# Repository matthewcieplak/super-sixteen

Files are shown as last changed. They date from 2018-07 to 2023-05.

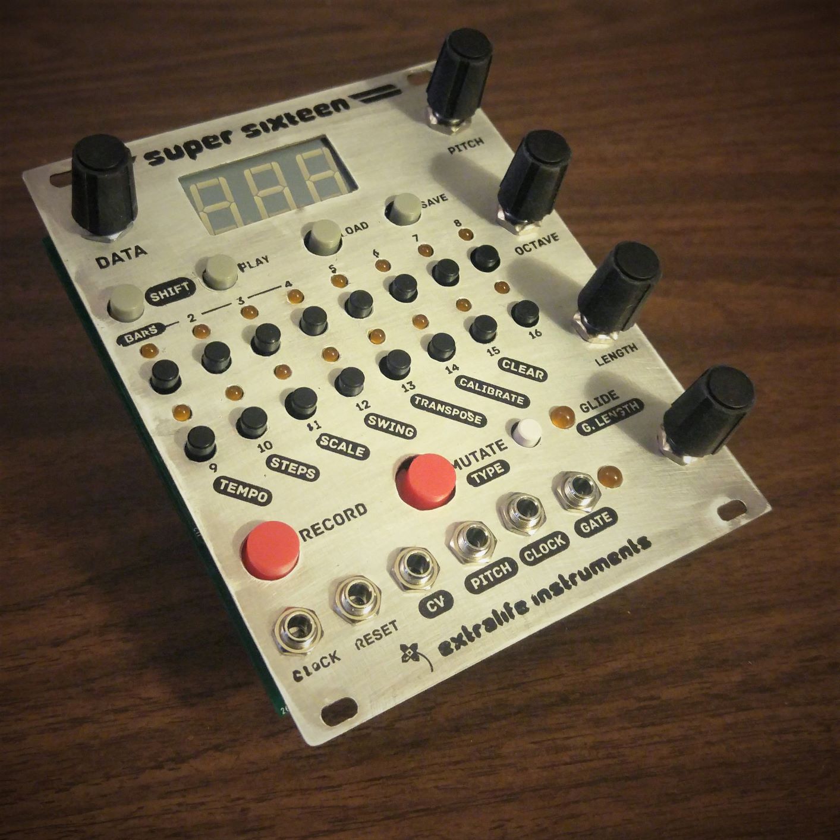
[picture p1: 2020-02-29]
graphics/supersixteen.jpg

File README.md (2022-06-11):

# Super Sixteen Eurorack Sequencer
Super Sixteen is an open-source/open-hardware sequencer for the Eurorack synthesizer format. It's available through my [web shop](https://store.extralifeinstruments.com) and fine retailers as a complete module and DIY kit. It's developed on the Arduino codebase on Atmega328P, using the [PlatformIO](https://platformio.org/) extension for Visual Studio Code.

Photo of the Super Sixteen module

At just 20HP, it is a compact and powerful 64-step control voltage sequencer with 99 song patch memory, motion recording, scale selection, realtime pitch and rhythm effects, paraphonic modes, generative mutations, and a uniquely powerful two-handed programming interface.

Video blogs [documenting the sequencer progress are available on youtube](
https://www.youtube.com/playlist?list=PLXcIAQij6ZZKMTHAFv8BHvEnsouNYhx3t).

# Documentation

*   [USER MANUAL (pdf)](graphics/manual_1.1.pdf)
*   [BUILD GUIDE (pdf)](http://extralifeinstruments.com/docs/super-sixteen/build-guide.pdf)
*   [BILL OF MATERIALS (octopart list)](https://octopart.com/bom-tool/Wq51xQ3R)
*   INTERACTIVE BOM (html - for easy part placement) [CPU board](http://extralifeinstruments.com/docs/super-sixteen/ibom-cpu.html) / [Control board](http://extralifeinstruments.com/docs/super-sixteen/ibom-control.html)
*   [Video build guide](https://www.youtube.com/watch?v=RGmp3aG8Nbw&feature=emb_title)
*   [1v/oct calibration tutorial video](https://www.youtube.com/watch?v=QJvS-ma6CHY)
*   [Build support thread on Mod Wiggler](https://modwiggler.com/forum/viewtopic.php?f=97&t=238514)
*   [ModularGrid page](https://modulargrid.net/e/other-unknown-extralife-instruments-super-sixteen)

# Hardware files
Kicad and gerber files for four PCBs are included in this repository. The project is split into two boards, one for the CPU, memory, power, and DAC logic (CPU_board) and one for the front panel controls (control_board). Each board comes in a through-hole version for DIY builders and an SMT version for automated assembly. They are functionally identical but part numbers are different to reflect the different footprints. 

# Software
Primary development of the firmware takes place in [sequencer_app_v2](https://github.com/matthewcieplak/super-sixteen/tree/master/sequencer_app_v2) using the Arduino C++ libraries but compiled using PlatformIO and typical C header files. (The older, pure Arduino version, [sequencer_app](https://github.com/matthewcieplak/super-sixteen/tree/master/sequencer_app) is here only for archival purposes and is unmaintained). You can find the .hex files to upload using the arduino updater in [sequencer_app_v2/build](https://github.com/matthewcieplak/super-sixteen/tree/master/sequencer_app_v2/build). The shell commands for updating using avrdude are contained in [upload.sh](sequencer_app_v2/upload.sh), though you may also use the Arduino IDE to upload new firmware.

# Troubleshooting
Please refer to the [official build support thread on Mod Wiggler](https://modwiggler.com/forum/viewtopic.php?f=97&t=238514) to post a query. You may find your question has already been answered!

Common issues:
* *My sequencer doesn't turn on!* - Check your soldering carefully, under magnification and bright light! 90% of functional issues can be traced to bad connections caused by missing or cold solder joints. A common place to find bad joints is on the header connector pins, as they are on the opposite side of the board from the othres.
* *My soldering is good, now what?*  After that, check the *orientation* of all your ICs closely. A backwards chip or capacitor or diode is easy to miss.
* *The screen shows "nEn" at startup and freezes when I move the encoder* - This message (actually "mEm") is caused by a communication failure between the CPU (Atmega328p) and the memory chip (W25Q80DV). Most often this is caused by soldering issues on the SMT memory chip. Reflow the SMT joints with flux and try again. If it persists, check for 3.3v at pins 8 and 4 of the memory chip. If that fails, you may suspect the 2n7000 transistors nearby (mosfets are fragile) and then potentially check the integrity of the traces between the chip and the resistors. Opening kicad and using the show net tool is helpful for this.
* *I can program sequences but they're not in tune* You need to perform the DAC calibration procedure, as outlined in the manual and [this video tutorial](https://www.youtube.com/watch?v=QJvS-ma6CHY). You'll need a multimeter or electronic tuner.

# License
Code: [GPL3.0](https://www.gnu.org/licenses/gpl-3.0.en.html)
Hardware: [cc-by-sa-3.0](https://creativecommons.org/licenses/by-sa/3.0/deed.en)

By: Matthew Cieplak (matthew.cieplak@gmail.com)

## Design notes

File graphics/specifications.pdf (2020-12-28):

# specifications

Dimensions:
Height 129.5mm
Width 102mm / 20 HP (horizontal pitch) Rear Depth 38mm
Front Depth 16mm (aka knob height)
Total Depth 55mm
Electrical characteristics:
Max current draw: 90mA (+12v) / 5mA (-12v) Pitch output voltage: 0-8 volts
CV output voltage: 0-8 volts
Gate output voltage: 0-5 volts
Clock output voltage: 0-5 volts

Clock input voltage: 10v maximum Reset input voltage: 10v maximum

Copyright 2020, Extralife Instruments, LLC

Power connector:
Super Sixteen requires a standard “Eurorack” -12V / +12V power supply (2x5 pin connector). The red stripe of the ribbon cable (-12V side) must be oriented on the same side as the “Red stripe” marking on the circuit board.

The complete manual can be found online at:
http://extralifeinstruments.com/docs/super-sixteen/manual.pdf

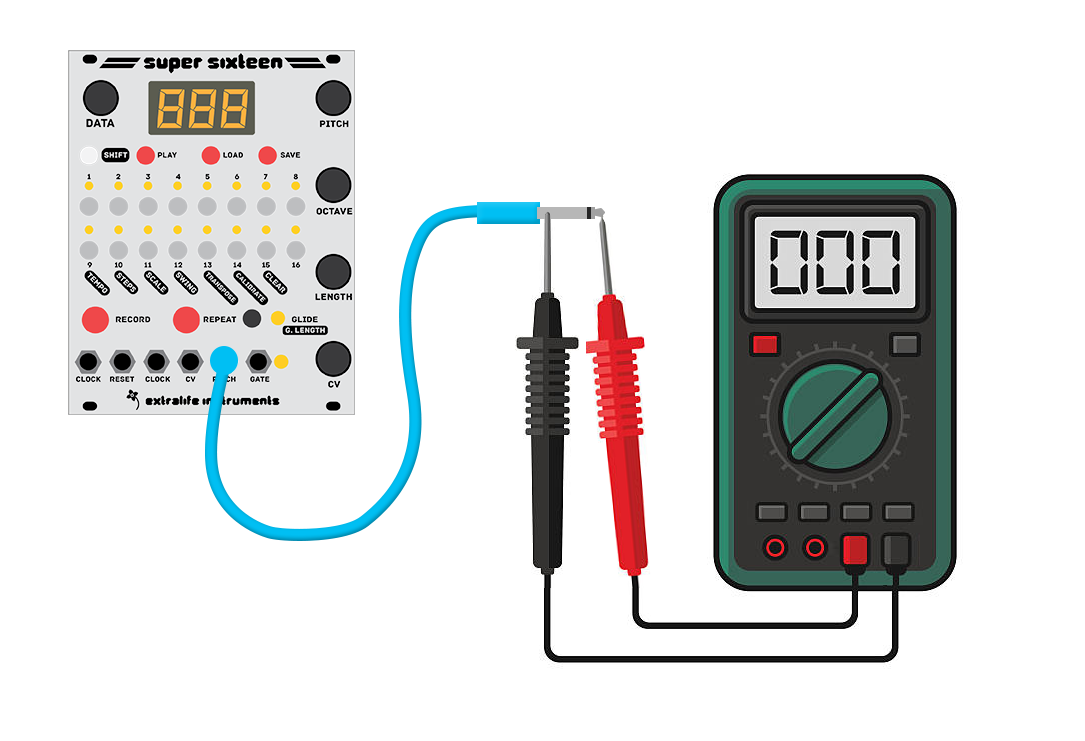
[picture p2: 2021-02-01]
graphics/multimeter clipart.png

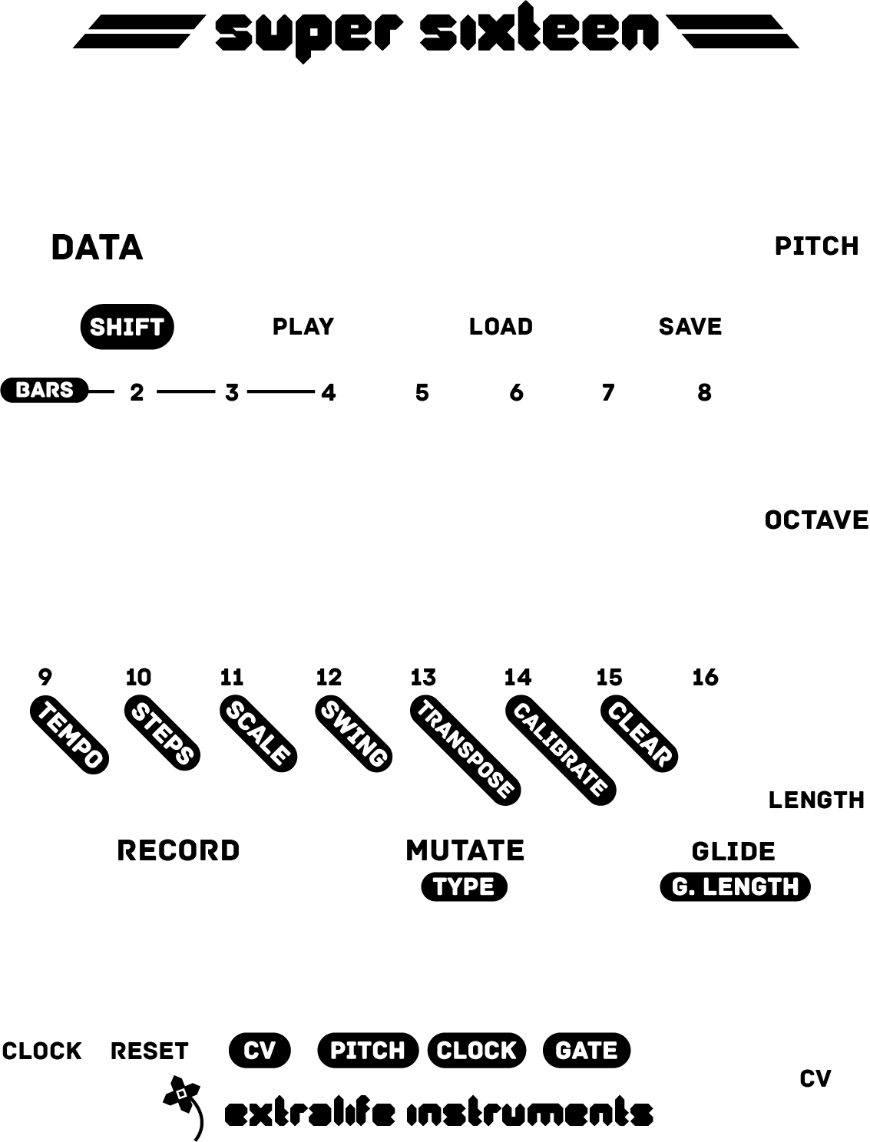
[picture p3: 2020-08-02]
kicad-panel/front_panel_labels.png

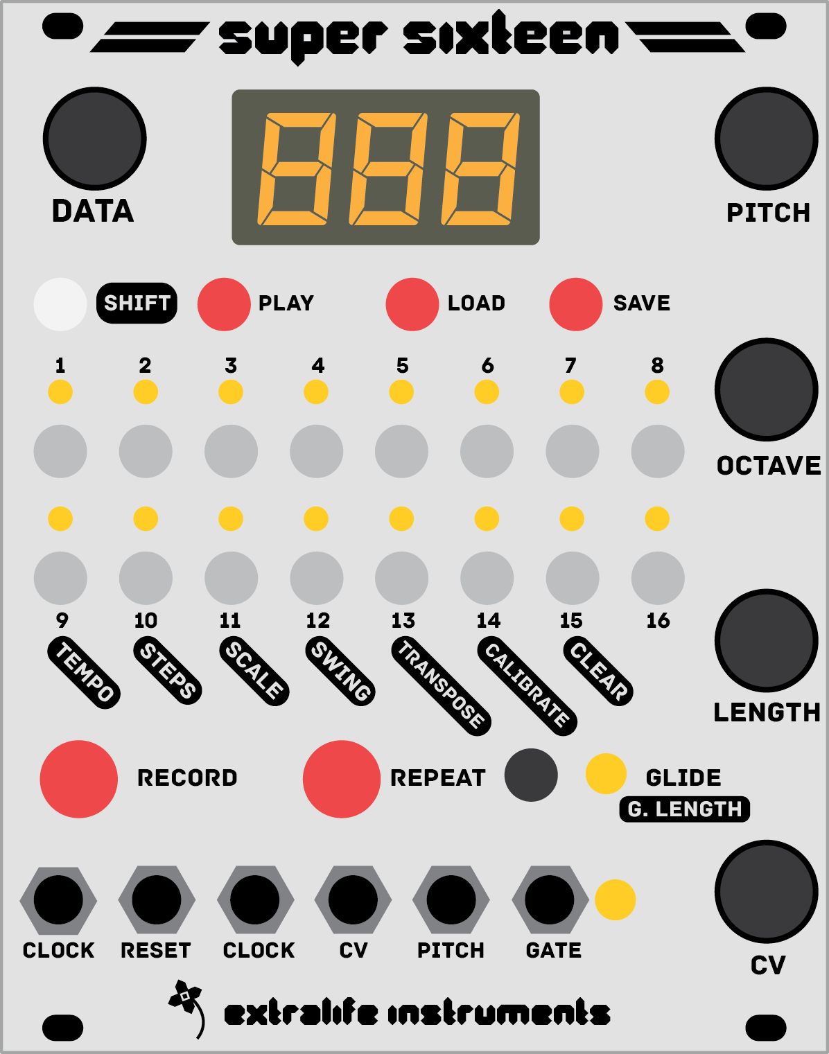
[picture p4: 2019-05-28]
graphics/front_panel.png

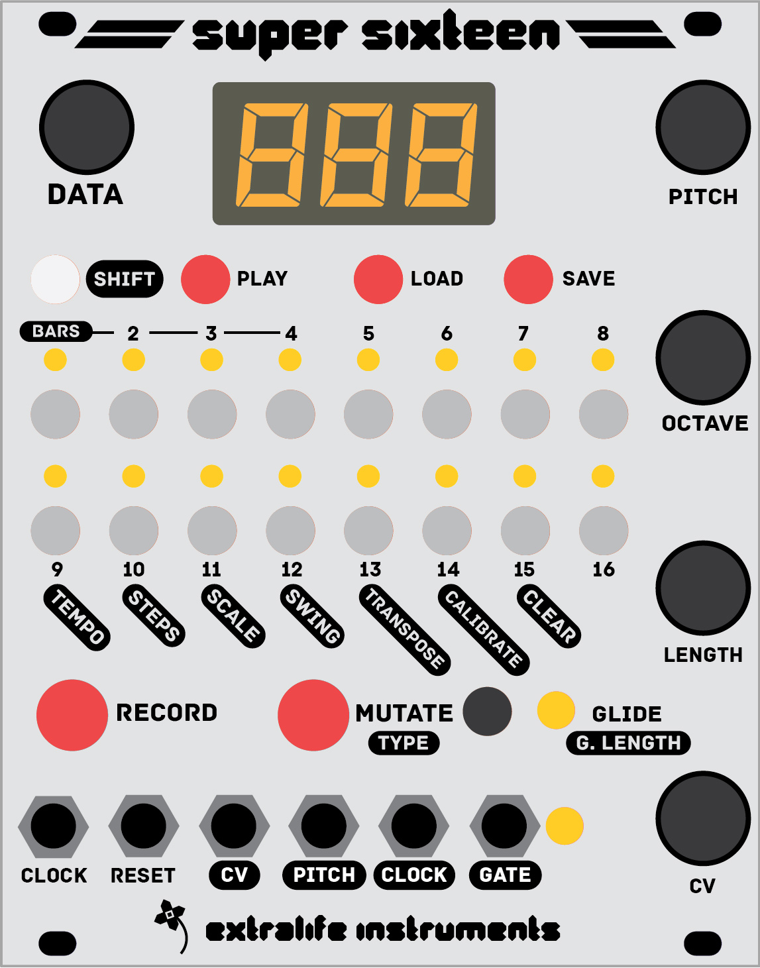
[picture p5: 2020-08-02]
graphics/supersixteenfrontpanel.jpg

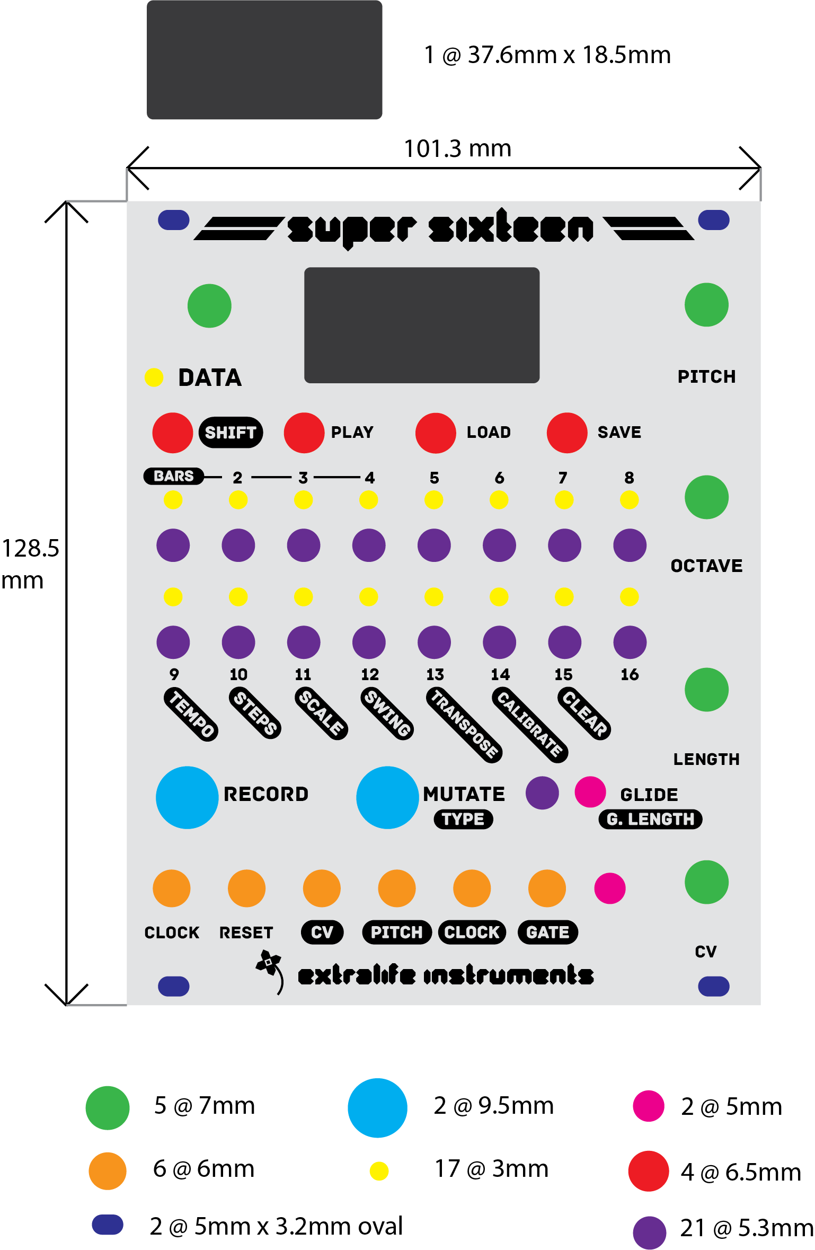
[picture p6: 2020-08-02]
kicad-panel/front_panel_legend.png

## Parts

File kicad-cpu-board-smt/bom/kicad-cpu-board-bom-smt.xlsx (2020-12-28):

Item Number | Comment | Do Not Install | Quantity | Reference Designators | Footprint | Vendor | Vendor Part # | Manufacturer Part # | Manufacturer
1 | 220uF |  | 1 | C11 | Capacitors_SMD:CP_Elec_10x10 | Digikey | 493-2179-6-ND | UWT1C221MCL1GS | Nichicon
2 | 47uF |  | 3 | C12,C10,C2 | Capacitors_SMD:CP_Elec_6.3x7.7 | Digikey | 493-2225-6-ND | UWT1H470MCL1GS | Nichicon
3 | 100nF |  | 7 | C13,C9,C1,C14,C6,C5,C4 | Capacitors_SMD:C_0603_HandSoldering | Digikey | 399-1100-6-ND | C0603C104Z3VACTU | Kemet
4 | 22pf |  | 4 | C16,C15,C7,C8 | Capacitors_SMD:C_0603_HandSoldering | Digikey | 399-7874-6-ND | C0603C220J1GACTU | Kemet
5 | 1uF |  | 1 | C3 | Capacitors_SMD:CP_Elec_4x5.3 | Digikey | 493-9985-6-ND | UUX2G010MNL1GS | Nichicon
6 | 1SMB5918BT3G |  | 2 | D2,D1 | Diodes_SMD:D_SMA-SMB_Universal_Handsoldering | Digikey | 1SMB5918BT3GOSDKR-ND | 1SMB5918BT3G | ON Semiconductor
7 | S1KB |  | 2 | D4,D3 | Diodes_SMD:D_SMA-SMB_Universal_Handsoldering | Digikey | S1KB-FDIDKR-ND | S1KB-13-F | Diodes Incorporated
8 | ICSP Header | DNI | 1 | J1 | Pin_Headers:Pin_Header_Straight_2x03_Pitch2.54mm | Digikey | 609-3218-ND | 67996-406HLF | Amphenol
9 | Conn_01x10_Male | DNI | 1 | J2 | Pin_Headers:Pin_Header_Straight_1x10_Pitch2.54mm | Digikey | 609-3285-ND | 68001-410HLF | Amphenol
10 | Conn_01x16_Male | DNI | 1 | J3 | Pin_Headers:Pin_Header_Straight_1x16_Pitch2.54mm | Digikey | 609-3267-ND | 68000-416HLF | Amphenol
11 | Conn_02x05_Odd_Even | DNI | 1 | J4 | Pin_Headers:Pin_Header_Straight_2x05_Pitch2.54mm | Digikey | 609-3243-ND | 67997-410HLF | Amphenol
12 | 220uH |  | 3 | L3,L2,L1 | Inductors_SMD:L_1210_HandSoldering | Digikey | 445-1545-6-ND | NLCV32T-221K-PF | TDK
13 | 2N7002 |  | 4 | Q2,Q4,Q3,Q1 | TO_SOT_Packages_SMD:SOT-23_Handsoldering | Digikey | 2N7002LT1GOSDKR-ND | 2N7002LT1G | ON Semiconductor
14 | 1M |  | 1 | R1 | Resistors_SMD:R_0603_HandSoldering | Digikey | RMCF0603FT1M00DKR-ND | RMCF0603FT1M00 | Stackpole Electronics, Inc
15 | 1k |  | 12 | R16,R4,R3,R12,R11,R8,R7,R6,R5,R10,R9,R13 | Resistors_SMD:R_0603_HandSoldering | Digikey | RMCF0603FT1K00DKR-ND | RMCF0603FT1K00 | Stackpole Electronics, Inc
16 | 10k |  | 5 | R17,R18,R14,R15,R2 | Resistors_SMD:R_0603_HandSoldering | Digikey | RNCP0603FTD10K0DKR-ND | RNCP0603FTD10K0 | Stackpole Electronics, Inc
17 | AMS1117-5.0 |  | 1 | U1 | TO_SOT_Packages_SMD:SOT-223-3_TabPin2 | Digikey | NCP1117ST50T3GOSDKR-ND | NCP1117ST50T3G | ON Semiconductor
18 | AMS1117-3.3 |  | 1 | U2 | TO_SOT_Packages_SMD:SOT-223-3_TabPin2 | Digikey | NCP1117ST33T3GOSDKR-ND | NCP1117ST33T3G | ON Semiconductor
19 | ATmega328P-AU |  | 1 | U3 | Housings_QFP:TQFP-32_7x7mm_Pitch0.8mm | Digikey | ATMEGA328P-AURDKR-ND | ATMEGA328P-AUR | Microchip Technology
20 | W25Q80DVSN |  | 1 | U4 | Housings_SOIC:SOIC-8_3.9x4.9mm_Pitch1.27mm | Digikey | W25Q80DVSNIG-ND | W25Q80DVSNIG | Winbond
21 | TL072 |  | 1 | U5 | Housings_SOIC:SOIC-8_3.9x4.9mm_Pitch1.27mm | Digikey | 296-1282-6-ND | TL072CDR | Texas Instruments
22 | MCP4822 |  | 1 | U6 | Housings_SOIC:SOIC-8_3.9x4.9mm_Pitch1.27mm | Digikey | MCP4822-E/SN-ND | MCP4822-E/SN | Microchip
23 | 16mHz |  | 1 | Y1 | Crystals:Crystal_SMD_3225-4pin_3.2x2.5mm_HandSoldering | Digikey | SER4069DKR-ND | TSX-3225 16.0000MF09Z-AC0 | Epson

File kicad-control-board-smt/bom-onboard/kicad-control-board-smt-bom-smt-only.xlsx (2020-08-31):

Comment | Quantity | Do Not Install | Reference Designators | Footprint | Vendor | Vendor Part # | MFG Part # | Manufacturer
47uF | 3 |  | C101,C104,C107 | Capacitors_SMD:CP_Elec_6.3x7.7 | Digikey | 493-2225-6-ND | UWT1H470MCL1GS | Nichicon
100nF | 3 |  | C102,C105,C108 | Capacitors_SMD:C_0603_HandSoldering | Digikey | 399-1100-6-ND | C0603C104Z3VACTU | Kemet
100pF | 3 |  | C103,C106,C109 | Capacitors_SMD:C_0603_HandSoldering | Digikey | 399-7821-6-ND | C0603C101J1GACTU | Kemet
SS54 | 1 |  | D1 | Diodes_SMD:D_SMA_Handsoldering | Digikey | TSS54URGGDKR-ND | TSS54U RGG | Taiwan Semiconductor
LED | 18 | DNI | D105,D114,D115,D111,D106,D102,D103,D107,D112,D116,D117,D113,D108,D104,D110,D101,D118,D109 | LEDs:LED_D3.0mm | Digikey | 160-1940-ND | LTL-1CHA | Lite-On
Conn_01x10_Female | 1 | DNI | J101 | Pin_Headers:Pin_Header_Straight_1x10_Pitch2.54mm | Digikey | S7008-ND | PPTC101LFBN-RC | Sullins
Conn_01x16_Female | 1 | DNI | J102 | Pin_Headers:Pin_Header_Straight_1x16_Pitch2.54mm | Digikey | S7014-ND | PPTC161LFBN-RC | Sullins
BA56_3DIG_7SEG | 1 | DNI | J103 | Eurocad:BA56_3DIG_7SEG | Digikey | 754-1656-5-ND | BA56-12GWA | Kingbright
3.5mm jacks | 6 | DNI | J104,J105,J106,J107,J108,J109 | Eurocad:PJ301M-12 | N/A | N/A | WQP-WQP518MA | Qingpu
MMBT3906 | 3 |  | Q101,Q102,Q103 | TO_SOT_Packages_SMD:SOT-23_Handsoldering | Digikey | MMBT3906LT1GOSDKR-ND | MMBT3906LT1G | ON Semiconductor
MMBT3904 | 2 |  | Q104,Q105 | TO_SOT_Packages_SMD:SOT-23_Handsoldering | Digikey | MMBT3904LT3GOSDKR-ND | MMBT3904LT3G | ON Semiconductor
100R | 12 |  | R101,R102,R104,R105,R106,R107,R108,R109,R110,R111,R112,R113 | Resistors_SMD:R_0603_HandSoldering | Digikey | RMCF0603FT100RDKR-ND | RMCF0603FT100R | Stackpole Electronics Inc
1k | 3 |  | R114,R118,R103 | Resistors_SMD:R_0603_HandSoldering | Digikey | RMCF0603FT1K00DKR-ND | RMCF0603FT1K00 | Stackpole Electronics Inc
680R | 3 |  | R115,R116,R117 | Resistors_SMD:R_0603_HandSoldering | Digikey | RMCF0603FT680RCT-ND | RMCF0603FT680R | Stackpole Electronics Inc
10k | 2 |  | R119,R122 | Resistors_SMD:R_0603_HandSoldering | Digikey | RMCF0603FT10K0DKR-ND | RMCF0603FT10K0 | Stackpole Electronics Inc
100k | 2 |  | R120,R123 | Resistors_SMD:R_0603_HandSoldering | Digikey | RMCF0603FG100KDKR-ND | RMCF0603FG100K | Stackpole Electronics Inc
1M | 2 |  | R121,R124 | Resistors_SMD:R_0603_HandSoldering | Digikey | RMCF0603FT1M00DKR-ND | RMCF0603FT1M00 | Stackpole Electronics Inc
R_POT | 4 | DNI | RV102,RV103,RV104,RV101 | Potentiometers:Potentiometer_Alps_RK09K_Horizontal | Digikey | N/A |  | Alpha
SW_PUSH_12mm | 2 | DNI | SW106,SW105 | Buttons_Switches_THT:Push_E-Switch_KS01Q01 | Digikey | 401-1992-ND | D6R40 F2 LFS | C&K
SW_Push_6mm | 21 | DNI | SW101,SW102,SW103,SW104,SW107,SW112,SW109,SW110,SW113,SW114,SW115,SW117,SW118,SW119,SW120,SW121,SW122,SW123,SW124,SW111,SW108 | Buttons_Switches_THT:SW_PUSH_6mm | Digikey | EG1861-ND | TL1105SPF160Q | E-Switch
Rotary_Encoder | 1 | DNI | SW116 | Rotary_Encoder:RotaryEncoder_Alps_EC12E_Vertical_H20mm | Digikey | PEC11R-4215F-N0024-ND | PEC11R-4215F-N0024 | Bourns, Inc
74HC595 | 2 |  | U101,U103 | Housings_SOIC:SOIC-16_3.9x9.9mm_Pitch1.27mm | Digikey | 1727-2821-6-ND | 74HC595D,118 | Nexperia USA, Inc
MCP23S17 | 1 |  | U102 | Housings_SOIC:SOIC-28W_7.5x18.7mm_Pitch1.27mm | Digikey | MCP23S17-E/SO-ND | MCP23S17-E/SO | Microchip

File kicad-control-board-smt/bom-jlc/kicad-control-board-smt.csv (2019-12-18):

Comment | Designator | Footprint | LCSC Part Number | MFG Part Number | Manufacturer
47uF | C101,C104,C107 | Capacitors_SMD:CP_Elec_6.3x7.7 | C108053 | VES470M1HTR-0607 | Lelon
100nF | C102,C105,C108 | Capacitors_SMD:C_0603_HandSoldering | C14663 | CC0603KRX7R9BB104 | Yageo
100pF | C103,C106,C109 | Capacitors_SMD:C_0603_HandSoldering | C14858 | CL10C101JB8NNNC | Samsung
SS54 | D1 | Diodes_SMD:D_SMA_Handsoldering | C22452 | SS54 | MDD
LED | D105,D114,D115,D111,D106,D102,D103,D107,D112,D116,D117,D113,D108,D104,D110,D101,D118 | LEDs:LED_D3.0mm
GlideLED | D109 | LEDs:LED_D3.0mm
Conn_01x10_Female | J101 | Pin_Headers:Pin_Header_Straight_1x10_Pitch2.54mm
Conn_01x16_Male | J102 | Pin_Headers:Pin_Header_Straight_1x16_Pitch2.54mm
BA56_3DIG_7SEG | J103 | Eurocad:BA56_3DIG_7SEG
Gate Out | J104 | Eurocad:PJ301M-12
Clock Out | J105 | Eurocad:PJ301M-12
Clock In | J106 | Eurocad:PJ301M-12
Pitch Out | J107 | Eurocad:PJ301M-12
CV Out | J108 | Eurocad:PJ301M-12
Reset In | J109 | Eurocad:PJ301M-12
MMBT3906 | Q101,Q102,Q103 | TO_SOT_Packages_SMD:SOT-23_Handsoldering | C53444 | MMBT3906LT1G | On Semicon
MMBT3904 | Q104,Q105 | TO_SOT_Packages_SMD:SOT-23_Handsoldering | C20526 | MMBT3904 | Changjiang
100 | R101,R102,R104,R105,R106,R107,R108,R109,R110,R111,R112,R113 | Resistors_SMD:R_0603_HandSoldering | C22775 | 0603WAF1000T5E | Uniroyal
1k | R114,R118,R103 | Resistors_SMD:R_0603_HandSoldering | C21190 | 0603WAF1001T5E | Uniroyal
680R | R115,R116,R117 | Resistors_SMD:R_0603_HandSoldering | C23228 | 0603WAF6800T5E | Uniroyal
10k | R119,R122 | Resistors_SMD:R_0603_HandSoldering | C25804 | 0603WAF1002T5E | Uniroyal
100k | R120,R123 | Resistors_SMD:R_0603_HandSoldering | C25803 | 0603WAF1003T5E | Uniroyal
1M | R121,R124 | Resistors_SMD:R_0603_HandSoldering | C22935 | 0603WAF1004T5E | Uniroyal
R_POT | RV102,RV103,RV104,RV101 | Potentiometers:Potentiometer_Alps_RK09K_Horizontal
Shift | SW101 | Buttons_Switches_THT:SW_PUSH_6mm
Play | SW102 | Buttons_Switches_THT:SW_PUSH_6mm
Load | SW103 | Buttons_Switches_THT:SW_PUSH_6mm
Save | SW104 | Buttons_Switches_THT:SW_PUSH_6mm
Repeat | SW105 | Buttons_Switches_THT:Push_E-Switch_KS01Q01
Mutate | SW106 | Buttons_Switches_THT:Push_E-Switch_KS01Q01
Glide | SW107 | Buttons_Switches_THT:SW_PUSH_6mm
SW_Push | SW112,SW109,SW110,SW113,SW114,SW115,SW117,SW118,SW119,SW120,SW121,SW122,SW123,SW124,SW111,SW108 | Buttons_Switches_THT:SW_PUSH_6mm
Rotary_Encoder | SW116 | Rotary_Encoder:RotaryEncoder_Alps_EC12E_Vertical_H20mm
74HC595 | U101,U103 | Housings_SOIC:SOIC-16_3.9x9.9mm_Pitch1.27mm | C5947 | 74HC595D,118 | Nexperia
MCP23S17 | U102 | Housings_SOIC:SOIC-28W_7.5x18.7mm_Pitch1.27mm | C145413 | MCP23S17-E/SO | Microchip

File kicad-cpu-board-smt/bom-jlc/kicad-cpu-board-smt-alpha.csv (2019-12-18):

Comment | Designator | Footprint | LCSC | LCSC Part Number | MFG Part Number | Manufacturer
220uf | C11 | Capacitors_SMD:CP_Elec_10x10 |  | C134521 | VZH221M1VTR-1010K | LELON
47uF | C2,C10,C12 | Capacitors_SMD:CP_Elec_6.3x7.7 |  | C108053 | VES470M1HTR-0607 | LELON
10uF | C3 | Capacitors_SMD:CP_Elec_4x5.3 |  | C249759 | VEZ100M1ETR-0405 | LELON
100nF | C4,C5,C6,C14,C1,C9,C13 | Capacitors_SMD:C_0603_HandSoldering |  | C14663 | CC0603KRX7R9BB104 | YAGEO
22pf | C8,C7,C15,C16 | Capacitors_SMD:C_0603_HandSoldering |  | C1653 | CL10C220JB8NNNC | SAMSUNG
1SMA4733A | D1,D2 | Diodes_SMD:D_SMA_Handsoldering |  | C173487 | 1SMA4733A | MDD
M7 | D3,D4 | Diodes_SMD:D_SMA_Handsoldering |  | C95872 | M7 | MDD
ICSP Header | J1 | Pin_Headers:Pin_Header_Straight_2x03_Pitch2.54mm
Conn_01x10_Male | J2 | Pin_Headers:Pin_Header_Straight_1x10_Pitch2.54mm
Conn_01x16_Female | J3 | Pin_Headers:Pin_Header_Straight_1x16_Pitch2.54mm
Conn_02x05_Odd_Even | J4 | Pin_Headers:Pin_Header_Straight_2x05_Pitch2.54mm
220uH | L1,L2,L3 | Inductors_SMD:L_1210_HandSoldering |  | C89015 | NLV32T-221J-PF | TDK
2N7002 | Q1,Q3,Q4,Q2 | TO_SOT_Packages_SMD:SOT-23_Handsoldering |  | C8545 | 2N7002 | CJ
1M | R1 | Resistors_SMD:R_0603_HandSoldering |  | C22935 | 0603WAF1004T5E | Uniroyal
10k | R2,R15,R14,R18,R17 | Resistors_SMD:R_0603_HandSoldering |  | C25804 | 0603WAF1002T5E | Uniroyal
1k | R3,R4,R13,R16 | Resistors_SMD:R_0603_HandSoldering |  | C21190 | 0603WAF1001T5E | Uniroyal
1K | R9,R10,R5,R6,R7,R8,R11,R12 | Resistors_SMD:R_0603_HandSoldering |  | C21190 | 0603WAF1001T5E | Uniroyal
AMS1117-5.0 | U1 | TO_SOT_Packages_SMD:SOT-223-3_TabPin2 |  | C6187 | AMS1117-5.0 | AMS
AMS1117-3.3 | U2 | TO_SOT_Packages_SMD:SOT-223-3_TabPin2 |  | C6186 | AMS1117-3.3 | AMS
ATmega328-PU | U3 | Housings_QFP:LQFP-32_7x7mm_Pitch0.8mm |  | C14877 | ATMEGA328P-AU | Microchip
W25Q80DVSN | U4 | Housings_SOIC:SOIC-8_3.9x4.9mm_Pitch1.27mm |  | C401655 | W25Q80DVSNIG TR | Winbond
TL072 | U5 | Housings_SOIC:SOIC-8_3.9x4.9mm_Pitch1.27mm |  | C6961 | TL072CDT | ST
MCP4822 | U6 | Housings_SOIC:SOIC-8_3.9x4.9mm_Pitch1.27mm |  | C16040 | MCP4822-E/SN | Microchip
16mHz | Y1 | Crystals:Crystal_SMD_3225-4pin_3.2x2.5mm_HandSoldering |  | C13738 | X322516MLB4SI | Yanxing Tech

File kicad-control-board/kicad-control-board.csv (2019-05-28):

Id | Designator | Package | Quantity | Designation | Supplier and ref
1 | J3 | BA56_3DIG_7SEG | 1 | BA56_3DIG_7SEG
2 | U2 | DIP-28_W7.62mm | 1 | MCP23S17
3 | J2 | Pin_Header_Straight_1x15_Pitch2.54mm | 1 | Conn_01x15_Male
4 | R23,R20 | R_Axial_DIN0204_L3.6mm_D1.6mm_P7.62mm_Horizontal | 2 | 100k
5 | C1,C4,C7 | CP_Radial_D6.3mm_P2.50mm | 3 | 47uF
6 | SW3 | RotaryEncoder_Alps_EC12E_Vertical_H20mm | 1 | Rotary_Encoder
7 | S9,S1,S2,S3,S4,S5,S6,S7,S8,S10,S11,S12,S13,S14,S15,S16 | SW_TH_Tactile_Omron_B3F-10xx | 16 | SW
8 | R14,R15,R16 | R_Axial_DIN0204_L3.6mm_D1.6mm_P7.62mm_Horizontal | 3 | 1K
9 | R17,R26,R25 | R_Axial_DIN0204_L3.6mm_D1.6mm_P7.62mm_Horizontal | 3 | R
10 | R19,R22 | R_Axial_DIN0204_L3.6mm_D1.6mm_P7.62mm_Horizontal | 2 | 10k
11 | R21,R24 | R_Axial_DIN0204_L3.6mm_D1.6mm_P7.62mm_Horizontal | 2 | 1M
12 | R18,R13 | R_Axial_DIN0204_L3.6mm_D1.6mm_P7.62mm_Horizontal | 2 | 1k
13 | R1,R2,R3,R4,R5,R12,R8,R9,R10,R11,R6,R7 | R_Axial_DIN0204_L3.6mm_D1.6mm_P7.62mm_Horizontal | 12 | 100
14 | C2,C5,C8 | C_Disc_D5.0mm_W2.5mm_P2.50mm | 3 | 100nF
15 | C3,C6,C9 | C_Disc_D3.8mm_W2.6mm_P2.50mm | 3 | 100pF
16 | D1,D2,D3,D4,D5,D6,D7,D8,D9,D10,D11,D12,D13,D14,D15,D16,D17 | LED3mm | 17 | LED
17 | D18 | LED3mm | 1 | GlideLED
18 | D19 | D_A-405_P7.62mm_Horizontal | 1 | BAT85
19 | J1 | Pin_Header_Straight_1x10_Pitch2.54mm | 1 | Conn_01x10_Female
20 | J4 | PJ301M-12 | 1 | Gate Out
21 | J5 | PJ301M-12 | 1 | Clock Out
22 | J6 | PJ301M-12 | 1 | Clock In
23 | J7 | PJ301M-12 | 1 | Pitch Out
24 | J8 | PJ301M-12 | 1 | CV Out
25 | J9 | PJ301M-12 | 1 | Reset In
26 | Q1,Q2,Q3,Q4,Q5 | TO-92_Inline_Narrow_Oval | 5 | 2N3904
27 | RV1,RV2,RV3,RV4 | Alpha9mmPot | 4 | B100K
28 | S17 | SW_TH_Tactile_Omron_B3F-10xx | 1 | Load
29 | S18 | SW_TH_Tactile_Omron_B3F-10xx | 1 | Save
30 | S19 | SW_TH_Tactile_Omron_B3F-10xx | 1 | Play
31 | S20 | SW_TH_Tactile_Omron_B3F-10xx | 1 | Shift
32 | S21 | SW_TH_Tactile_Omron_B3F-10xx | 1 | GlideBtn
33 | SW1 | Push_E-Switch_KS01Q01 | 1 | Repeat
34 | SW2 | Push_E-Switch_KS01Q01 | 1 | Mutate
35 | U1,U3 | DIP-16_W7.62mm | 2 | 74HC595

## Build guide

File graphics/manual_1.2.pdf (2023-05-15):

## extralife instruments

Owner’s manual v1.2
Documents available at:
http://extralifeinstruments.com/

# SUPER SIXTEEN

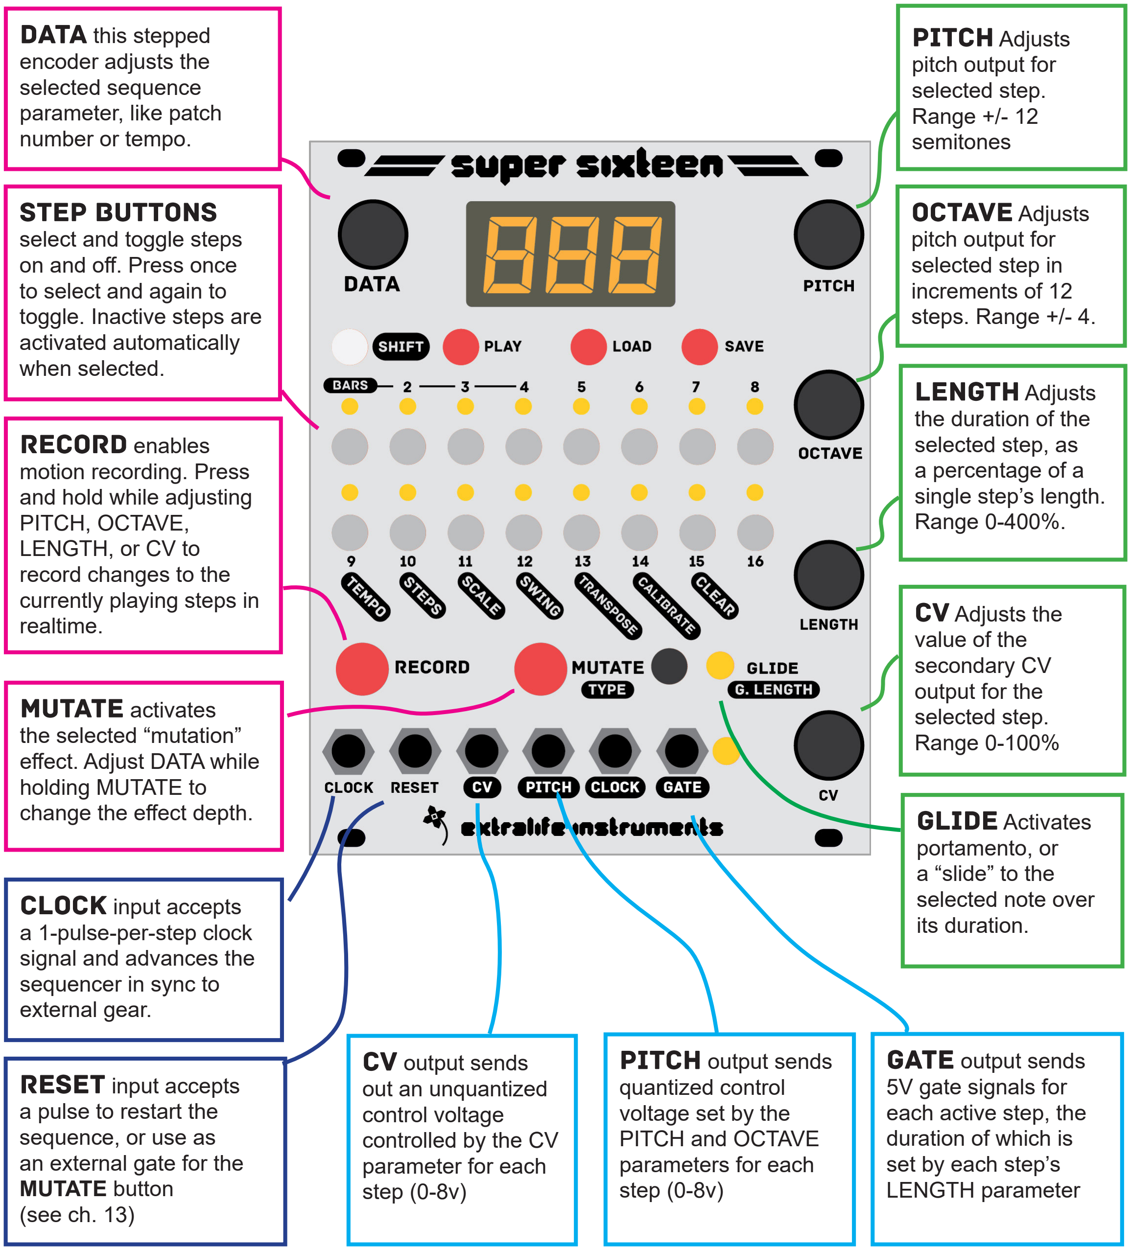
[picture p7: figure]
PITCH Adjusts pitch output for selected step. Range +/- 12 semitones; DATA this stepped encoder adjusts the selected sequence parameter, like patch number or tempo.; CLOCK input accepts a 1-pulse-per-step clock signal and advances the sequencer in sync to external gear.; RESET input accepts a pulse to restart the sequence, or use as an external gate for the MUTATE button (see ch. 13); CV output sends out an unquantized control voltage controlled by the CV parameter for each step (0-8v); PITCH output sends quantized control voltage set by the PITCH and OCTAVE parameters for each step (0-8v)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

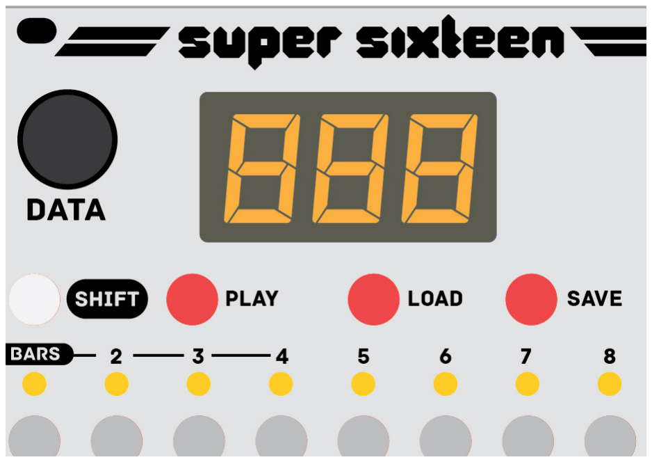
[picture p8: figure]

SHIFT Press [SHIFT] plus another button simultaneously to access its secondary or “shift” function (these are outlined in black labels on the panel). Buttons that have shift functions include Steps 9-16, Record, Mutate, Glide, and Play. When
you are editing a parameter, press [SHIFT] again to exit back to the main note data display.

PLAY Start or stop the internal sequencer playback. [SHIFT]+Play resets to the start, the same as a pulse to the RESET input. A pulse to the CLOCK input will stop the internal sequencer.

Note: Pressing play while the
CLOCK input is receiving a signal generally has no effect - if the internal tempo is set much faster than the external clock, however, pressing play may cause the sequencer to gain a step relative to the external clock before it syncs again.

LOAD/SAVE enables you to save the active sequence or load a new one. To save a sequence to memory, press SAVE once, and then use the DATA knob to choose the PATCH NUMBER (1-99) [0-99] where this sequence will be saved. To confirm it, press SAVE again. Press [SHIFT] to cancel saving. Once saved, the sequence can be recalled at any time. It’s a good idea to save your sequences frequently, since it’s easy to radically alter the patch memory.

Note: While selecting a patch number, the decimal point after the number indicates that there is already a sequence saved at that patch number.

Once you’ve chosen a PATCH NUMBER to save your sequence, you can double-tap SAVE to overwrite it with the active sequence. Get in the habit of doing this whenever you make a change you like! You can likewise double-tap LOAD to reload the last-saved sequence if you make a change you dislike.

To load a sequence, press LOAD once, and then use the DATA knob to choose a PATCH NUMBER to load. Press LOAD again to confirm and load the sequence

Note:If there is no sequence in that patch number, a blank sequence will be loaded.

When a new sequence is loaded, the sequence will “pick up” playback in real-time at the same place in the last bar of the sequence, making synchronized songs and pickup phrasing dead simple.

# 1. Sequence controls

# 2. Step editing

Step editing is accomplished by pressing the the 16 step buttons in the center of the panel. The LEDs adjacent to each button indicate whether that step is active or inactive. This display indicates the 16-step rhythm of the sequence.When selected for editing, its LED will blink on and off. If the selective step is active, it will be mostly on and blink off briefly. If it’s inactive, it will be mostly off and blink on briefly.

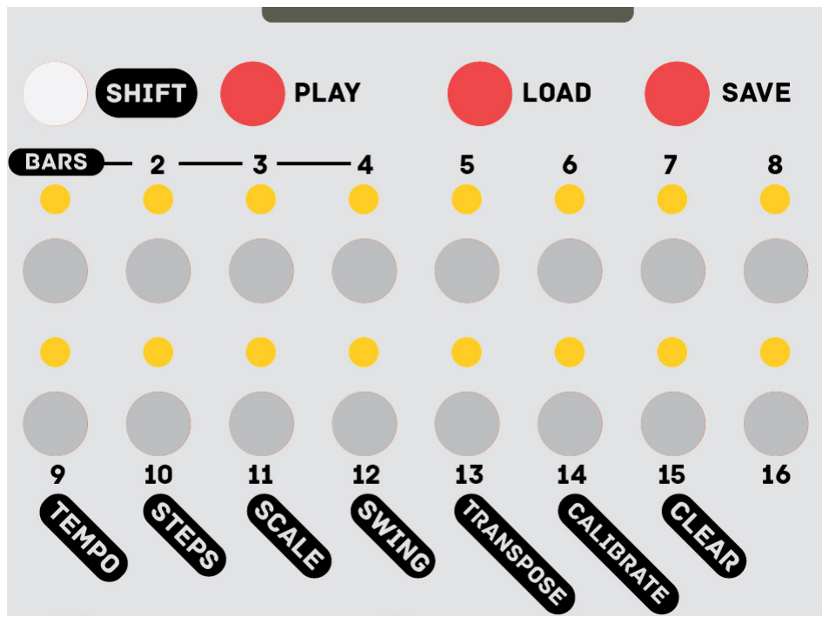
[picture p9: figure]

To select a step, press the corresponding button once.

If inactive, that step will be automatically activated when selected. To deactivate a step, press it again.

Once a step is selected, you can edit its PITCH, OCTAVE, DURATION, CV, and GLIDE values with the corresponding knobs and button on the right side of the panel. These values only change when the knobs are moved and the display updates to reflect the new value. When a step is selected, the display will update to show its value for the last edited parameter.

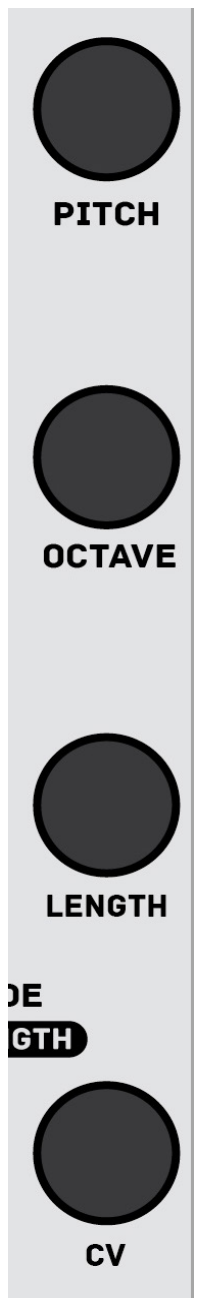
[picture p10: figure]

Only active steps will trigger the gate output and change the PITCH/CV outputs. Inactive steps do not have any effect on the seqeuncer, but their values are saved with the sequence.

While the sequencer is playing, the LEDS will blink as each step is played to show a “Running light” indicating the current step.

Tap once to select/activate a step

Tap again to deactivate

Press a button to select a step then edit it by turning the knobs.

## PITCH & OCTAVE

### together control the Pitch

output voltage.

### CV controls the CV

output voltage.

### DURATION controls the length of the pulse sent

to the GATE output.

# 5. Multi-bar sequences

To view and edit a bar of 16 steps, press SHIFT and STEP 1, 2, 3, or 4, indicated by the “BARS” label. This will update the step display LEDs to show the active steps for that bar.

The default sequence length is 16 steps, but sequences of any length from 1-64 steps can be programmed. To access steps 17-64, make use of the BARS buttons (SHIFT+1 thru 4) and the STEPS parameter (SHIFT+10). This feature is analogous to “Pages.”

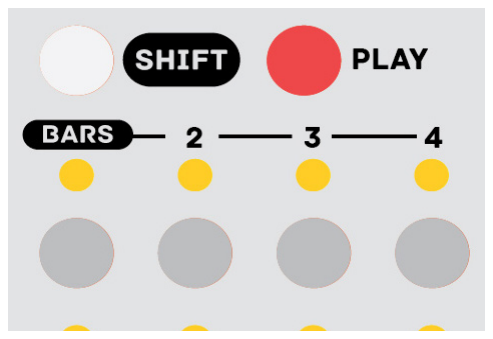
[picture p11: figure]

Note: A subsequent bar may be edited and have active steps, but it will not play unless the STEPS parameter is adjusted so the sequence is long enough to reach it.

Bars may be COPIED and PASTED within a sequence to create repetitions. To copy and paste a bar, press SHIFT, then press the button for the bar you wish to copy (the source), then (while holding SHIFT+source) press the button for the bar you want to paste it to (the destination). The display will flash “CPY” when a bar is successfully pasted.

To adjust the sequence length, select STEPS (SHIFT+10), and then select a number of steps using the DATA knob. If you continue holding shift, the knob will skip through common sequence lengths divisible by 4 (4, 8, 12, 16, 24, 32, 48, 64). Release SHIFT to adjust 1 step at a time and create odd-length sequences if desired.

### Copy/paste a bar:

[SHIFT]+ SOURCE + DESTINATION

Example:
[SHIFT] + 1 + 2 = Copy bar 1 to bar 2

[SHIFT] + 2 + 4 = Copy bar 2 to bar 4

Change seq. length:
[SHIFT] + 10 (STEPS)
Adjust with DATA knob

View and edit BARS:
[SHIFT] + 1 (Steps 1-16)
[SHIFT] + 2 (17-32)
[SHIFT] + 3 (33-48)
[SHIFT] + 4 (49-64)

# 4. Motion recording

Step parameters can also be editing in real-time using the RECORD button.

While the sequencer is playing, press and hold RECORD and adjust any of the knobs for PITCH, OCTAVE, DURATION, or CV to record those changes to the sequence as it plays.

The changes are only recorded while the button is held down, and only the first knob adjusted during recording is recorded. Only active steps will be updated. To record another parameter, release the record button and press it again as the sequence loops during playback. It is good to get in the habit of releasing the record button quickly as it is easy to overwrite your sequence with new notes.

It is also a good idea to SAVE your sequence before recording in new data. Double-tap the SAVE button to write it to the last-used patch number. Then record your new part. If you aren’t happy with the change, just double-tap LOAD to “undo” the changes and reload the previous version.

Hold RECORD
while adjusting
PITCH,
OCTAVE,
DURATION,
or CV to
make quick
changes to the
sequence

Real-time rhythm:
hold SHIFT and
tap a rhythm on
RECORD to activate
steps during sequence
playback.

Note: during a live performance, motion-recording using the PITCH parameter can be quite dangerous as it can introduce non-diatonic “wrong notes” into your sequence. These can be avoided by selecting a SCALE for the sequence to exclude such notes and allow greater improvisation (see the SCALE section). However, in a typical patch, recording real-time changes to OCTAVE, DURATION and usually CV is relatively “safe” for live performance, though it is still a good idea to save your patches frequently for reloading.

# 6. CV Output Modes

# CV - STEPPED CV MODE

# LFO - SMOOTHED CV MODE

In smoothed CV, or “LFO” (low frequency oscillator) mode, the CV output ramps up or down continuously to the next value over the course of each step, creating smooth transitions from each value to the next.

This is especially useful when using the CV output to control synth parameters like filter frequency, FM modulations, or wavetable positions, where the continuous “in-between” values create audible timbre changes. This can also be thought of as a seqeunced arbitrary envelope generator.

Using motion recording with LFO mode is especially satisfying, as it can more accurately reproduce expressive control movements than stepped mode.

In the default stepped CV mode, the CV output jumps to the next value when an active step is reached. The output ranges from 0-100, scaled from 0-8V. This can be thought of as “velocity,” providing a constant linear scaled CV output per-step.

### The secondary control voltage output “CV” and its corresponding knob

can be used to create several different types of control signals - stepped,

### smoothed, and quantized 1v/oct pitch. (This feature is only available in firmware version 1.2 and later.)

### Hold SHIFT and turn the CV knob to adjust the CV output mode to any of the following modes. This setting is saved per-sequence and resets to default stepped linear CV when a blank sequence is loaded or the CLEAR

function is used.

# int - Paraphonic interval mode

# not - Paraphonic note mode

The paraphonic CV Modes allow the CV output to be used as a 1 volt/octave scaled control, exactly like the PITCH output. In “Interval mode” the value of the CV output tracks relative to the value of the Pitch output (controlled by the Pitch/Octave knobs).
In this mode the CV output can be offset from the Pitch output by a musical interval from -24 to +24 steps (2 octaves up and down). This is ideal for creating harmonized melodies or chord sequences. If a non-chromatic scale is selected using the SCALE function, the CV output will also be quantized to the nearest diatonic scale degree (musical note within the scale), just like the Pitch output.

“Note” mode is also scaled for 1v/octave pitch output, but in this mode the CV output is decoupled from the “Pitch/Octave” controls. You can use the CV knob to select an arbitrary pitch for each active step and program a completely separate melody from the main sequence.

However, the CV output only changes when the selected step is active, so it shares the same rhythm as the main sequence. (By using an external gate sequencer, it is possible to program two completely parts.)

In this mode the CV output can be set to pitch values from C1 to C5 (1v to 5v). This mode always uses named musical pitches rather than numbers. This output also obeys the sequence’s scale quantization and transposition values, allowing lower or higher ranges to be achieved if desired (e.g. 0v-4v, or 2v-6v).

This mode is ideal for programming basslines which complement the main melody. It can also be used for programming counterpoint melodies or chords more easily by those who are familiar with music theory.

# 7. [Shift] functions

Additional sequence parameters can
be edited by pressing and holding [SHIFT] and pressing another button, then adjusting that parameter using the DATA knob. These values are saved with each sequence (except CALIBRATE and CLEAR).

Most buttons which have a secondary
function show that function in
outlined text.

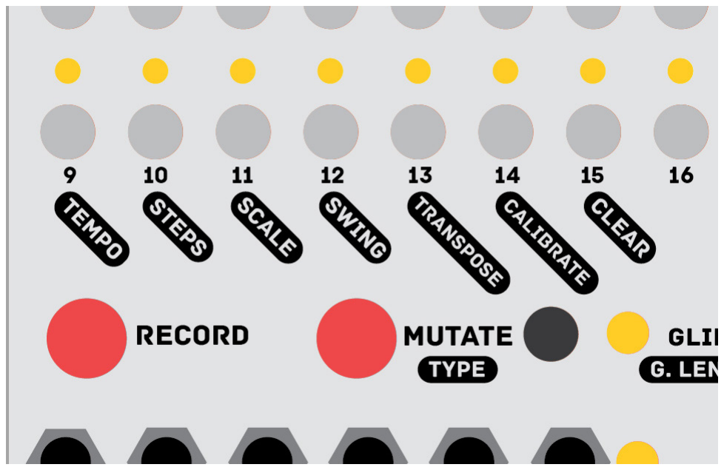
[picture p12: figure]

SELECT BAR | SHIFT + 1/2/3/4
To edit steps after 1-16, you can jump to the next BAR by pressing SHIFT+[BAR NUMBER]. Buttons 1-4 are marked BAR to indicate this function. Keep in mind than in order for steps after 16 to be played, the STEPS parameter must be adjusted as well.
TEMPO | SHIFT + 9
Controls the speed of the sequence, in beats per minute (BPM).

NOTE: When loading a new sequence, the sequencer tempo is only adjusted if the sequencer is PAUSED. When a new sequence is loaded during playback, it will continue at the same tempo as the previous sequence to avoid sudden jumps.

STEPS | SHIFT + 10
Controls the number of steps in the sequence (Range: 1-64). See the section on MULTI-BAR SEQUENCING (p 11).
SCALE | SHIFT + 11
Selects a musical scale to constrain the values for the PITCH parameter.
See SCALES (page 10).
SWING | SHIFT + 12
Adjusts the timing of even-numbered steps to create a “swing” or “shuffle” rhythm. A default value of 50 produces a “straight” rhythm, while higher values produce more swing. The sequencer can accept a straight Clock input signal and still play swung notes, but will produce a “swung” clock output when the swing parameter is adjusted.

TRANSPOSE | SHIFT + 13
Adjusts the pitch output of the entire sequence up and down in increments of 1 semitone. This enables different sequences to be played in different “keys” without adjusting oscillator tuning or step editing. Range +/- 36.
CALIBRATE | SHIFT + 14
Enters calibration mode to tune the voltage scaling. See CALIBRATION (pg. 13)
CLEAR | SHIFT + 15
Deactivates all steps and resets all note values to their default (zero for PITCH, OCTAVE, and CV, and 80 for DURATION).
FACTORY RESET | SHIFT + 15 (five times)
To reset the module to factory settings and erase all stored sequences, hold SHIFT and then the 15 button five times in a row. The screen will show “CLR” then “E - R - S” (one letter each press), then blink “ERS.” Press 15 a fifth time to erase all sequences.
SONG MODE | SHIFT + 16
This lets you choose a sequence and loop counter to chain sequences together. See the SONG MODE section for more details. ((Firmware 1.1 and later)
NEXT SEQUENCE | SHIFT + LOAD
Immediately loads the next sequence selected in SONG MODE. (Firmware 1.1 and later)
RESET CLOCK | SHIFT + PLAY
To reset the sequence clock to Step 1, hold shift and press play. When the play button is pressed or the next clock pulse is received, the sequence will restart. The same thing can be achieved by sending a pulse to the RESET input jack.
CV MODE SELECT | SHIFT + CV KNOB
To use the CV output as a paraphonic pitch control or a smoothed LFO, hold shift and turn the CV knob to the desired setting (see Ch. 6) (Firmware 1.2 and later)
Note Audition | SHIFT + PITCH KNOB
To hear the pitch of a note while editing, press shift and turn the PITCH knob to the right. Thee screen will show AUD (“audition”) or OFF. When activated, the gate output will be activated and the selected step’s pitch sent to the PITCH output whenever the PITCH or OCTAVE knobs are changed. This allows you to program sequences by ear more quickly. (Firmware 1.2 and later)

# 8. Mutations

Pressing and holding the MUTATE button activates the selected mutation effect while the button is held. While MUTATE is held, you can turn the DATA knob to adjust its effect depth. This does different things depending on the selected mutation - see the table below.

Pressing SHIFT+MUTATE will enter the mutation selection menu. Use the DATA knob to select a mutation. Press SHIFT or another button to exit the menu. The available mutations are shown in the table.

To RECORD a mutation sequence, you can press and hold RECORD, then tap the MUTATE button on each step that you want the mutation to be active, just as you would when using it in real-time, then release the RECORD button.

To ERASE a mutation sequence, you must simply record over it. So, press and hold RECORD, then tap MUTATE once to initate recording of mutation data, then release the MUTATE button and continue holding record to “erase” mutation data for as long as you like (one complete loop of the sequence will erase it all).

### EXTERNAL TRIGGERING:

You can also trigger mutations with a gate input. This produces the same effect as pressing the MUTATE button but frees up your hands. To use the RESET input as an external trigger input for the mutation function, enter calibration mode and press button 11 to toggle between “MUT” (mutate) and “RST” (reset). (See chapter 13 for diagram).

### Suggested uses:

Mutations can be used creatively to add real-time variation to recorded sequence. Try “playing” the mutate button rhythmically to introduce varied repetitions or “fills” in your sequences. While holding the mutate button, adjust the effect depth step-by-step to create variations of increasing intensity.

Recording mutation data can be especially fun with the RANDOMIZE mode, because you can create semi-random sequences in which certain sections vary each time it’s played. Use it in combination with a particular SCALE mode to create a generative sequence that never quite repeats itself twice.

The “Turing” mutation modes can be used for generative sequencing inspired by their namesake module. Turing 1 will alter your pitch data, Turing 2 will create new rhythms, and Turing 3 will create brand new sequences from scratch.

Display | Mutation | Adjustment | Description
rep | Repeat | Number of steps | Repeats a short section of the sequence
rev | Reverse | N/A | Reverses playback while held
OCT | Octave shift | Num. of octaves up/down | Transposes pitch up/down by 12 steps
TRS | Transpose | Num. of steps up/down | Transposes pitch by steps (within scale)
gld | Auto-glide | Glide duration | Activates glide for every step while held
frz | Freeze | N/A | Holds the current pitch and activates the gate
5tp | Stop | Duration | Pitch slowly ramps down to 0V
rnd | | Randomness | Transposes pitch by random amount (and conforms to selected scale)
5tt | Stutter | Stutter-step duration | Adds short repeated steps on inactive notes
rol | Roll | Step subdivision | Subdivides clock and doubles, triples, etc notes
tu1 | Turing 1* | Randomness | Melody generator: Same as “Randomize,” but new pitches are stored in the active sequence.
tu2 | Turing 2* | Density | Rhythm generator: Randomly adds new steps using existing pitch data to create new rhythms but preserves harmony.
tu3 | Turing 3* | Density | Sequence generator: creates completely new random sequence data including pitch, octave (+/-2), gate(20-170), CV (0-90), and glide (10% rate).
Cho | Chord** | Interval (semitones) | Sets CV output to a fixed harmonic interval relative to pitch output
chQ | Chord** Quantized | Interval (semitones) | Same as chord, but obeys scale selection
5ub | Sub Osc** | Num of octaves up/down | Sets CV output to an octave interval relative to pitch output (for use as sub-oscillator)
Vib | Vibrato** | Intensity | Adds a vibrato effect to pitch outputs
* = Only available in firmware version 1.1 and later | ** = Only available in firmware 1.2 and later

# 9. Glide/portamento

Glide (aka “portamento” or “slide”) may be activated for any active step by selecting a step and then pressing the GLIDE button. When active, the pitch output will slowly ramp up or down to that step’s pitch over its duration. The ramp time begins at the beginning of the step.

The glide duration may be adjusted by pressing SHIFT+GLIDE and adjusting the value with the encoder. The value goes from 0-400, and like the “duration” knob represents a percentage fo the current step length. (A value greater than 100 will take longer than one step to complete, and the pitch output may not reach the final value before the next step activates.) The glide duration is saved along with the other sequence data.

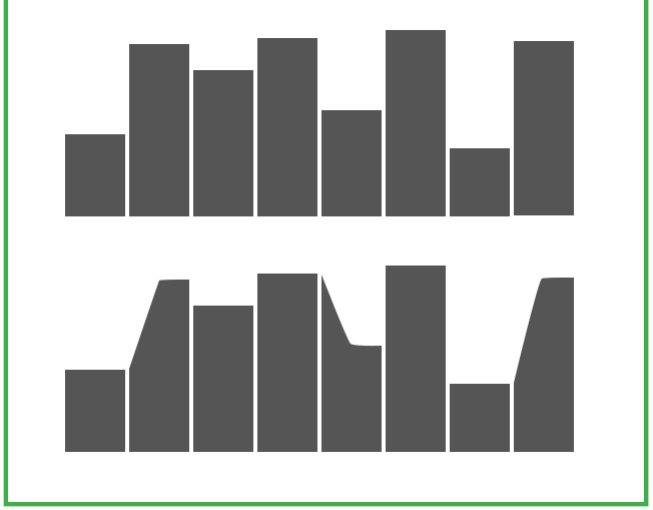
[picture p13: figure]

A sequence of control voltages showing the sharp transitions without glide (above) and the smoother “ramp” transition with glide (below)

# 10. Scales

Pressing SHIFT+11 will enter the scale selection menu, where you can use the DATA knob to select a scale.

The selected scale will quantize the sequence to and restrict pitch selection to notes within the scale. Any previously entered sequence data will remain unedited, but will be quantized in realtime to the selected scale.

RANDOMIZE and TRANSPOSE mutations will also obey the selected scale quantization and produce variations which remain in-key with the sequence.

When a scale type besides Chromatic is selected, non-diatonic pitch values will be skipped when adjusting the PITCH knob for any step.

Display | Scale
chr | Chromatic
MAJ | Major
min | Minor
pen | Pentatonic
pem | Minor pentatonic
Blu | Blues
BLM | Minor blues
phr | Phrygian
dor | Dorian
Who | Whole tone

# 11. Song mode

Sequences can be chained together one after another using SONG MODE. Enabling chaining consists of setting two special parameters for a given sequence:

1. SONG SEQUENCE (5n9) - the patch number of the sequence to be played after the current sequence. [0-99]. Setting this to zero will deactivate song mode (default).
2. SONG LOOPS (lp5) - the number of times the current sequence should loop before advancing to the next sequence [0-99]. Setting this to Zero will loop the current sequence indefinitely (default).

Both parameters can be edited by pressing SHIFT+16 in sequence mode. The display will show either 5n9 or Lp5 to indicate which parameter is selected. To edit the other, simply press SHIFT+16 again. Turn the DATA knob to edit each parameter as desired.

IMPORTANT: Editing these parameters during playback can produce unexpected jumps to the next sequence, erasing your changes! It is best to edit these parameters while paused.

After both parameters are set, save the sequence to memory by double-tapping SAVE (otherwise these settings will be lost when the next sequence is loaded!). Then reset playback by pressing SHIFT+PLAY (this resets the sequence loop counter). Start playback by pressing PLAY or using an external clock.

The sequence will play through the number of times specified in the LOOPS parameter, then the patch number selected in SONG SEQUENCE will be loaded automatically and start playing in time. This can be used to create longer, song-length compositions that play in sequence.

If either parameter is set to zero, or if the selected patch is empty, the current patch will simply continue playing.

Song mode can be used without automatic advance by choosing a next sequence and setting the LOOPS parameter to zero. Just press SHIFT+LOAD to instantly load the next sequence whenever desired. This can be used to create sequential “sets” of sequences without adhering to a strict song format and length.

Note: Song mode is only available in firmware version 1.1 and later.

# 12. Calibration

To achieve accurate tuning of the analog 1v/octave pitch output, it must be calibrated using digital multimeter, or an electronic tuner and well calibrated oscillator.

### Multimeter

Connect a 3.5mm TS cable to the PITCH output of the Super Sixteen. Set your multimeter to read DC volts (10V range minimum). Connect the negative/ground/common (black) input of the multimeter to the SLEEVE of the TS cable using an alligator clip. Connect the positive/red input of the multimeter to the TIP of the cable.

### Electronic tuner

Connect the PITCH output to the 1V/OCT input of a well-calibrated oscillator. Using a simple waveform (like a sine or triangle wave), connect the output of the oscillator to a digital tuner. (Make sure to attenuate the output if necessary, as eurorack level signals can damage equipment made for instrument or line level inputs).

Enter calibrate mode on the Super Sixteen and select the lowest output voltage (button 1). Turn on the tuner and use the COARSE tune of the oscillator to set the pitch to the lowest note that the tuner can easily pick up. Use the FINE tune of the oscillator to set it to an exact concert pitch (typically C1 or A1).

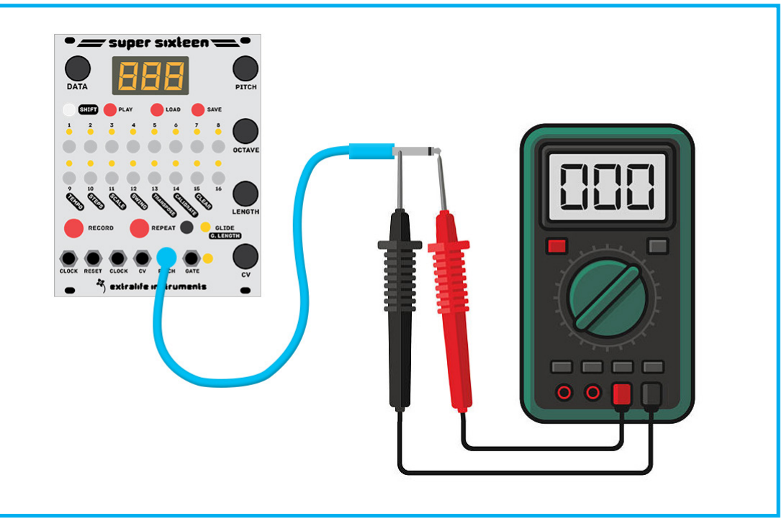
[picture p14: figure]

Connect a multimeter to the pitch output as shown. Alligator clips are helpful to secure the multimeter probes if a direct 3.5mm to banana adapter is unavailable.

Press SHIFT+14 to enter calibration mode. In this mode buttons 1-8 let you choose different octaves, which will set the PITCH output to exact voltages, from 1v, 2v, 3v, up to 8v.

Press 1 and use the DATA encoder to set the calibration to 1.000V as exactly as possible. (Use the CV knob instead to adjust the CV output voltage).

Press 2 and use the encoder to set the calibration to exactly 2.000 volts, or 1 octave above your tuned pitch at 0V. It is common to have to adjust by 5-20 “units” of correction. Each unit represents about 0.002 volts, or about 3 cents of concert pitch.

Press 3 and repeat the tuning at 3 volts. Continue all the way up to 8 (8 volts). You may have to tune your oscillator lower than initially in order to use your tuner at the top of the pitch range.

IMPORTANT: When you are satisfied that all octaves are playing in tune, press SAVE to store the calibration values to memory. These values are saved to
EEPROM and will persist even after a factory reset. If you have made and error and want to discard the new calibration values, press SHIFT to return to sequence mode.

### Calibration procedure (continued)

secondary CV OUTPUT calibration - for paraphonic sequencing If you are planning to use the secondary CV output as a 1v/oct pitch control, then it must also be calibrated to match the PITCH output. The procedure is the same as with the PITCH output. Connect a cable to the CV output and connect to either an oscillator and tuner or a multimeter. When calibrating, instead of the DATA encoder, adjust the CV output’s pitch using the CV knob.

The CV output can also be tuned to the primary PITCH output much like tuning strings on a guitar. (This may produce a more musically pleasing result than tuning both to exactly 1v/octave, esp. when playing chords.) Connect each output to two oscillators’ 1v/oct inputs, then enter calibration mode and choose an octave using buttons 1-8.

If the PITCH output is already calibrated satisfactorily, you can simply adjust the tuning of the CV output to match the two oscillators’ frequencies as closely as possible. You must adjust the second oscillator’s tuning to roughly match the first oscillator. Then listen to the “beat frequency” of the two sounds and adjust the CV knob on Super Sixteen until the “beat” slows down to a nearly imperceptible level. Repeat for each octave as you would for each pair of strings on a guitar.

NOTE NAME / NUMERIC DISPLAY
While in calibration mode, you can press buttons 15 and 16 to choose between two types of note display. This will affect what shows on the display when editing PITCH and OCTAVE values. Press 15 to choose “Note” mode (not). Notes will display as C0, B1, D3, etc, reflecting traditional MIDI/piano note names. Press 16 to choose “Numeric” mode (num). Notes will display as numbers from -12 to +12 and octaves from -4 to +4, reflecting chromatic scale degrees.
This option is only available in firmware version 1.1 and later.

Calibration values

Use buttons 1-8 to set the
PITCH and CV outputs to exact octave values, and then calibrate them using the DATA encoder and CV knob respectively.
Button 1 should output exactly 1 volt, 2 should be 2 volts, etc. (In firmware version 1.0, button 1 set the output to 0v and buttons 2-9 were used for 1-8v).

# 13. SETTINGS

BRIGHTNESS
Adjust the LED screen
brightness by pressing
9 then turning the DATA
encoder. (Range 1-5).
(Firmware v1.1 and later)

RESET/Mutate
Use the “RESET” gate input as an external mutation trigger by pressing button 11 and toggling between “RST” (RESET) and
“MUT” (MUTATE).
(Firmware v1.2 and later)

ENCODER INVERT
if your DATA encoder
changes numbers in
the opposite direction
(clockwise/anticlockwise), press button 13 to invert
its operation (INV/REG)

While in calibration mode, several other settings are available to adjust:

- BRIGHTNESS (button 9, DATA knob)
- RESET/MUTATE (button 11, toggle)
- INVERT ENCODER (button 13, toggle)
- NOTE NAME DISPLAY (buttons 15 and 16)

# 14. Specifications

### Dimensions:

Height: 129.5mm
Width: 102mm / 20 HP (horizontal pitch) Rear Depth: 38mm
Front Depth: 16mm (aka knob height)
Total Depth: 55mm

### Electrical characteristics:

Max current draw: 160mA (+12v) / 5mA (-12v) Pitch output voltage: 0-8 volts
CV output voltage: 0-8 volts
Gate output voltage: 0-5 volts
Clock output voltage: 0-5 volts

Clock input voltage: 10v maximum Reset input voltage: 10v maximum

Copyright 2020, Extralife Instruments, LLC

Power connector:
Super Sixteen requires a standard “Eurorack” -12V / +12V power supply (2x5 pin connector). The red stripe of the ribbon cable (-12V side) must be oriented on the same side as the “Red stripe” marking on the circuit board.

The complete manual can be found online at: http://extralifeinstruments.com/docs/super-sixteen/manual.pdf

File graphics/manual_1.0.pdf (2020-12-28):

### extralife instruments

Quick Start Guide 1.0
Complete manual available at: http://extralifeinstruments.com/

# SUPER SIXTEEN

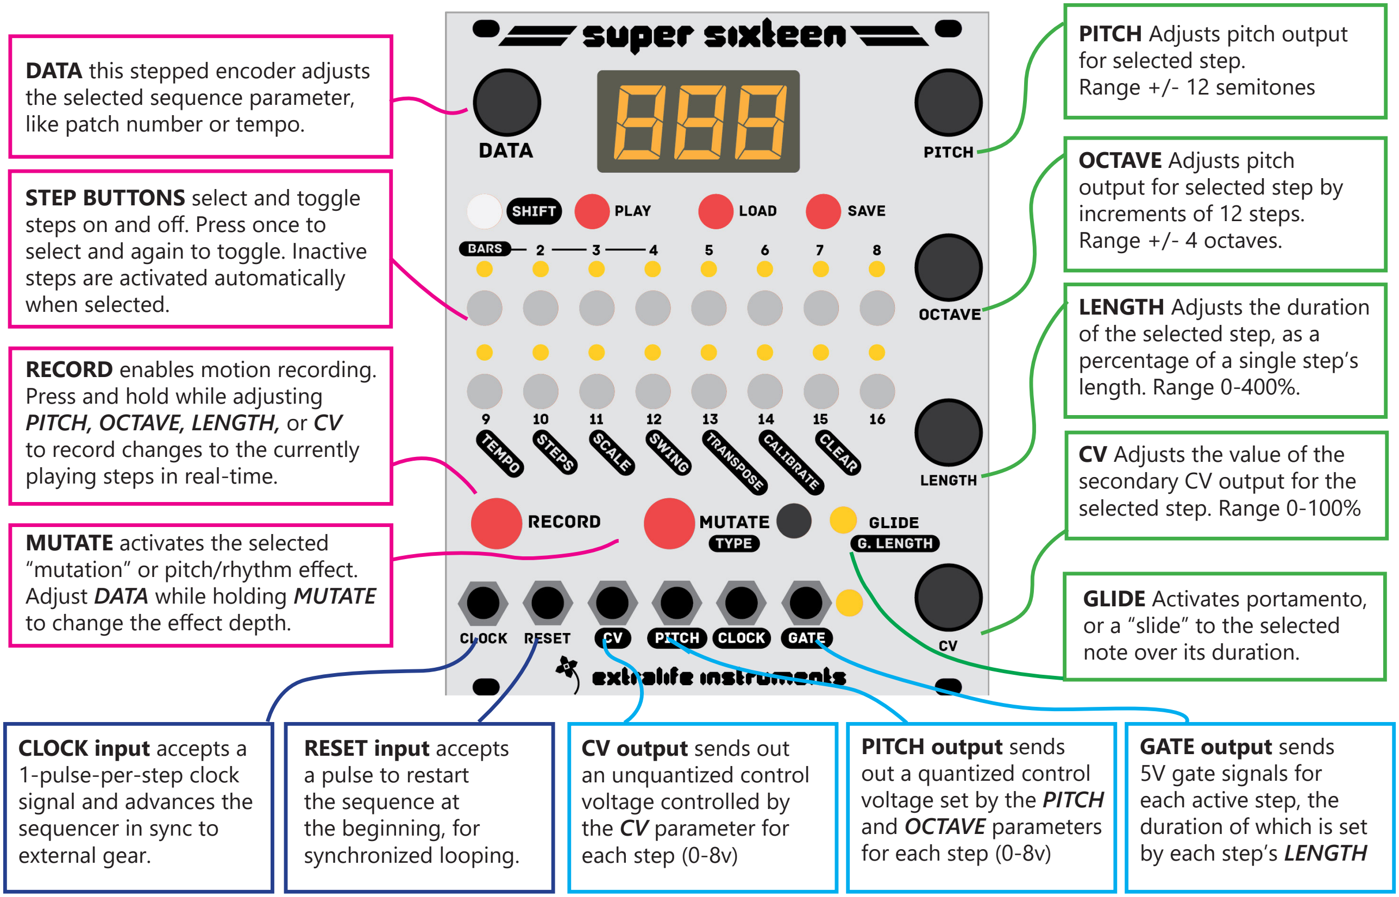
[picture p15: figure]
PITCH Adjusts pitch output for selected step. Range +/- 12 semitones; DATA this stepped encoder adjusts the selected sequence parameter, like patch number or tempo.; CLOCK input accepts a 1-pulse-per-step clock signal and advances the sequencer in sync to external gear.; RESET input accepts a pulse to restart the sequence at the beginning, for synchronized looping.; CV output sends out an unquantized control voltage controlled by the CV parameter for each step (0-8v); PITCH output sends out a quantized control voltage set by the PITCH and OCTAVE parameters for each step (0-8v)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

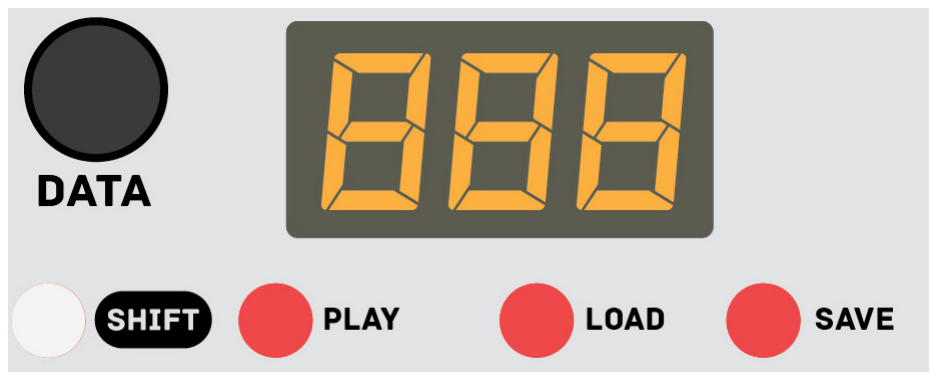
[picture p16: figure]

SHIFT Press [SHIFT] plus another button simultaneously to access its secondary or “shift” function (these are outlined in black labels on the panel). Buttons that have shift functions include Steps 9-16, Record, Mutate, Glide, and Play. When you are editing a parameter, press [SHIFT] again to exit back to the main note data display.

PLAY Start or stop the internal sequencer playback. [SHIFT]+Play resets to the start, the same as a pulse to the RESET input. A pulse to the CLOCK input will stop the internal sequencer.
NOTE: Pressing play while the CLOCK input is receiving a signal generally has no effect - if

LOAD/SAVE enables you to save the active sequence or load a new one. To save a sequence to memory, press SAVE once, and then use the DATA knob to choose the PATCH NUMBER (1-99) [0-99] where this sequence will be saved. To confirm it, press SAVE again. Press [SHIFT] to cancel saving. Once saved, the sequence can be recalled at any time. It’s a good idea to save your sequences frequently, since it’s easy to radically alter the patch memory.
Once you’ve chosen a PATCH NUMBER to save your sequence, you can double-tap SAVE to overwrite it with the active sequence. Get in the habit of doing this whenever you make a change you like! You can likewise double-tap LOAD to reload the last-saved sequence if you make a change you dislike.
To load a sequence, press LOAD once, and then use the DATA knob to choose a PATCH NUMBER to load. Press LOAD again to confirm it. If there is no sequence in that patch number, the display will flash “ERR” (error). This just means that patch number is empty.
NOTE: When a new sequence is loaded, the sequence will “pick up” playback in real-time at the same place in the last bar of the sequence, making synchronized

# -sequence controls

# step editing

Step editing is accomplished by pressing the the 16 step buttons in the center of the panel. The LEDs adjacent to each button indicate whether that step is active or inactive. This display indicates the 16-step rhythm of the sequence.When selected for editing, its LED will blink on and off. If the selective step is active, it will be mostly on and blink off briefly. If it’s inactive, it will be mostly off and blink on briefly.

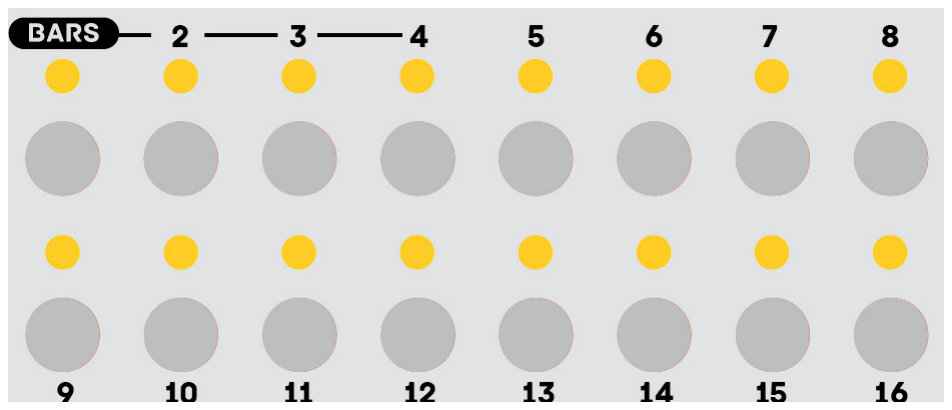
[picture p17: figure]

To select a step, press the corresponding button once. If inactive, that step will be automatically activated when selected. To deactivate a step, press it again. Once a step is selected, you can edit its PITCH, OCTAVE, DURATION, CV, and GLIDE values with the corresponding knobs and button on the right side of the panel. These values only change when the knobs are moved and the display updates to reflect the new value. When a step is selected, the display will update to show its value for the last edited parameter.
Only active steps will trigger the gate output and change the PITCH/CV outputs. Inactive steps do not have any effect on the seqeuncer, but their values are saved with the sequence.
While the sequencer is playing, the LEDS will blink as each step is played to show a “Running light” indicating the current step.

## Tap once to activate a step Double-tap a step to deactivate

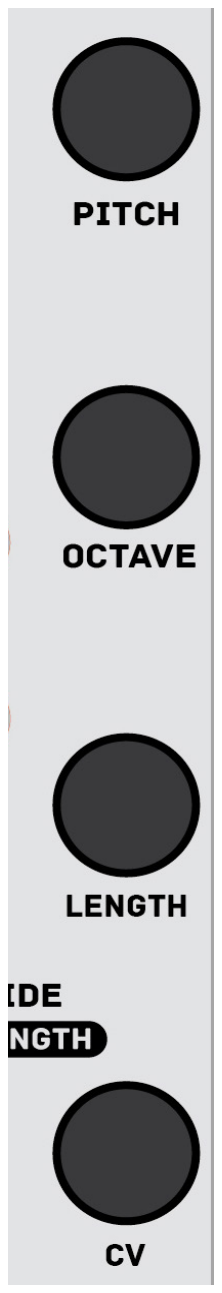
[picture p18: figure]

### Press a button to select a step

then edit it by turning the knobs.
- PITCH and OCTAVE together control the Pitch output voltage.
- CV controls the CV output voltage.
- DURATION controls the length of the pulse sent to the GATE output.

# multi-bar sequences

To view and edit a bar of 16 steps, press SHIFT and
STEP 1, 2, 3, or 4, indicated by the “BARS” label. This will update the step display LEDs to show the active steps for that bar.

The default sequence length is 16 steps, but sequences of any length from 1-64 steps can be programmed. To access steps 17-64, make use of the BARS buttons (SHIFT+1 thru 4) and the STEPS parameter (SHIFT+10). This feature is analogous to “Pages.”

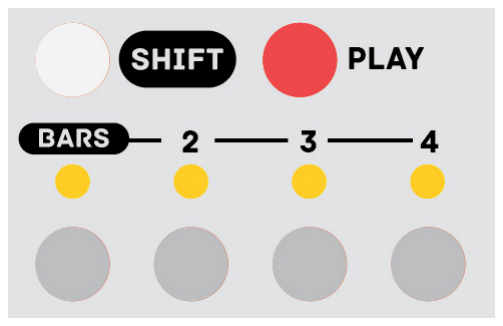
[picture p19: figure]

Note: A subsequent bar may be edited and have active steps, but it will not play unless the STEPS parameter is adjusted so the sequence is long enough to reach it. Bars may be COPIED and PASTED within a sequence to create repetitions. To copy and paste a bar, press SHIFT, then press the button for the bar you wish to copy (the source), then (while holding SHIFT+source) press the button for the bar you want to paste it to (the destination). The display will flash “CPY” when a bar is successfully pasted.

To adjust the sequence length, select STEPS (SHIFT+10), and then select a number of steps using the DATA knob. If you continue holding shift, the knob will skip through common sequence lengths divisible by 4 (4, 8, 12, 16, 24, 32, 48, 64). Release SHIFT to adjust 1 step at a time and create odd-length sequences if desired.

Copy/paste a bar:
[SHIFT]+ SOURCE + DESTINATION For example:
[SHIFT] + 1 + 2 = Copy bar 1 to bar 2 [SHIFT] + 2 + 4 = Copy bar 2 to bar 4

Change sequence length:
-[SHIFT] + 10 (STEPS)
-Adjust with DATA knob
View and edit a bar:
[SHIFT] + 1 (Steps 1-16)
[SHIFT] + 2 (17-32)
[SHIFT] + 3 (33-48)
[SHIFT] + 4 (49-64)

# motion recording

Step parameters can also be editing in real-time using the RECORD button. While the sequencer is playing, press and hold RECORD and adjust any of the knobs for PITCH, OCTAVE, DURATION, or CV to record those changes to the sequence as it plays.
The changes are only recorded while the button is held down, and only the first knob adjusted during recording is recorded. Only active steps will be updated. To record another parameter, release the record button and press it again as the sequence loops during playback. It is good to get in the habit of releasing the record button quickly as it is easy to overwrite your sequence with new notes. It is also a good idea to SAVE your sequence before recording in new data. Double-tap the SAVE button to write it to the last-used patch number. Then record your new part. If you aren’t happy with the change, just double-tap LOAD to “undo” the changes and reload the previous version.

Hold RECORD
while
adjusting
PITCH,
OCTAVE,
DURATION,
or CV to
make quick
changes to
the sequence

Real-time rhythm:
hold SHIFT+RECORD
to activate steps during
sequence playback.

Note: during a live performance, motion-recording using the PITCH parameter can be quite dangerous as it can introduce non-diatonic “wrong notes” into your sequence. These can be avoided by selecting a SCALE for the sequence to exclude such notes and allow greater improvisation (see the SCALE section). However, in a typical patch, recording real-time changes to OCTAVE, DURATION and usually CV is relatively “safe” for live performance, though it is still a good idea to save your patches frequently for reloading.

# shift functions

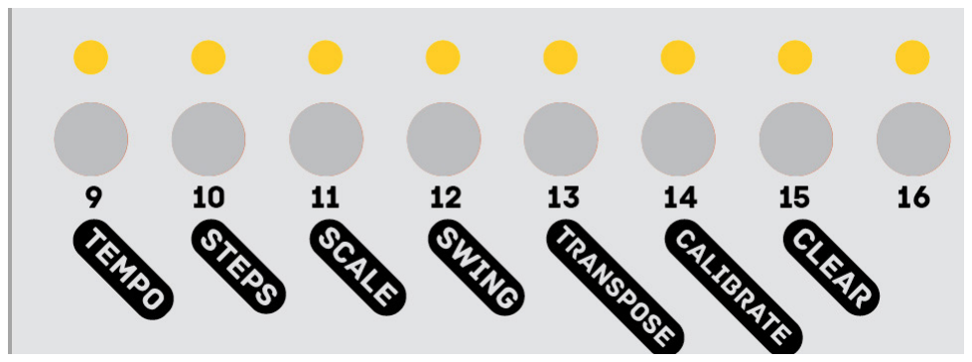
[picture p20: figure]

Additional sequence parameters can be edited by
pressing and holding [SHIFT] and pressing another
button, then adjusting that parameter using the
DATA knob. These values are saved with each sequence (except CALIBRATE and CLEAR).
Most buttons which have a secondary function
show that function in outlined text.
TEMPO (SHIFT+9)
Controls the speed of the sequence, in beats per minute (BPM).
NOTE: When loading a new sequence, the sequencer tempo is only adjusted if the sequencer is PAUSED. When a new sequence is loaded during playback, it will continue at the same tempo as the previous sequence to avoid sudden jumps.

STEPS (SHIFT+10)
Controls the number of steps in the sequence (Range: 1-64). See the section on MULTI-BAR SEQUENCING (p 11).

SCALE (SHIFT+11)
Selects a musical scale to constrain the values for the PITCH parameter. See SCALES (page 10).

SWING (SHIFT+12)
Adjusts the timing of even-numbered steps to create a “swing” or “shuffle” rhythm. A default value of 50 produces a “straight” rhythm, while higher values produce more swing. The sequencer can accept a straight Clock input signal and still play swung notes, but will produce a “swung” Clock output when the swing parameter is adjusted.
TRANSPOSE (SHIFT+13)
Adjusts the pitch output of the entire sequence up and down in increments of 1 semitone. This enables different sequences to be played in different “keys” without adjusting oscillator tuning or step editing. Range +/- 36.

## CALIBRATE (SHIFT+14

Enters calibration mode to tune the voltage scaling. See CALIBRATION (pg. 13)
CLEAR (SHIFT+15)
Deactivates all steps and resets all note values to their default (zero for PITCH, OCTAVE, and CV, and 80 for DURATION).

## FACTORY RESET (SHIFT + 15 5x)

To reset the module to factory settings and erase all stored sequences, hold SHIFT and then the 15 button five times in a row. The screen will show “CLR” then “E - R - S” (one letter each press), then blink “ERS.” Press 15 a fifth time to erase all sequences.

## RESET (CLOCK) (SHIFT+PLAY)

To reset the sequence clock to Step 1, hold shift and press play. When the play button is pressed or the next clock pulse is received, the sequence will restart. The same thing can be achieved by sending a pulse to the RESET input jack.

# mutations

Pressing and holding the MUTATE button activates the selected mutation effect while the button is held. While MUTATE is held, you can turn the DATA knob to adjust its effect depth. This does different things depending on the selected mutation - see the table below.

Pressing SHIFT+MUTATE will enter the mutation selection menu. Use the DATA knob to select a mutation. Press SHIFT or another button to exit the menu. The available mutations are shown in the table.
To RECORD a mutation sequence, you can press and hold RECORD, then tap the MUTATE button on each step that you want the mutation to be active, just as you would when using it in real-time, then release the RECORD button. To ERASE a mutation sequence, you must simply record over it. So, press and hold RECORD, then tap MUTATE once to initate recording of mutation data, then release the MUTATE button and continue holding record to “erase” mutation data for as long as you like (one complete loop of the sequence will erase it all).

## Suggested uses:

Mutations can be used creatively to add real-time variation to recorded sequence. Try “playing” the mutate button rhythmically to introduce varied repetitions or “fills” in your sequences. While holding the mutate button, adjust the effect depth step-by-step to create variations of increasing intensity (this works especially well with REPEAT, TRANSPOSE, OCTAVE SHIFT, and ROLL modes).
Recording mutation data can be especially fun with the RANDOMIZE mode, because you can create semi-random sequences in which certain sections vary each time it’s played. Use it in combination with a particular SCALE mode to create a generative sequence that varies over time.

Display | Mutation | Adjustment | Description
rep | Repeat | Number of steps | Repeats a short section of the sequence
rev | Reverse | N/A | Reverses playback while held
OCT | Octave shift | Num. of octaves up/down | Transposes pitch up/down by 12 steps
TRS | Transpose | Num. of steps up/down | Transposes pitch by steps (within scale)
gld | Auto-glide | Glide duration | Activates glide for every step while held
frz | Freeze | N/A | Holds the current pitch and activates the gate
5tp | Stop | Duration | Pitch slowly ramps down to 0V
rnd | Randomize | Randomness | Transposes pitch by random amount (w/in scale)
5tt | Stutter | Stutter-step duration | Adds short repeated steps on inactive notes
rol | Roll | Step subdivision | Subdivides clock and doubles, triples, etc notes

# glide

Glide (aka “portamento” or “slide”) may be activated for any active step by selecting a step and then pressing the glide button. When active, the pitch output will slowly ramp up or down to that step’s pitch over its duration. The ramp time begins at the beginning of the step.
The glide duration may be adjusted by pressing SHIFT+GLIDE and adjusting the value with the encoder. The value goes from 0-400, and like the “duration” knob represents a percentage fo the current step length. (A value greater than 100 will take longer than one step to complete, and the pitch output may not reach the final value before the next step activates.) The glide duration is saved along with the other sequence data.

# scales

Pressing SHIFT+11 will enter the scale selection menu, where you can use the DATA knob to select a scale to quantize the sequence to and restrict pitch selection. Any previously entered sequence data will remain unedited, but will be quantized in real-time to the selected scale.
RANDOMIZE and TRANSPOSE mutations will also obey the selected scale quantization and produce variations which remain in-key with the sequence.
When a scale type besides Chromatic is selected, non-diatonic pitch values will be skipped when adjusting the PITCH knob for any step.
Display | Scale
chr | Chromatic
MAJ | Major
min | Minor
pen | Pentatonic
pem | Minor pentatonic
Blu | Blues
BLM | Minor blues
phr | Phrygian
dor | Dorian
Who | Whole tone

# calibration

To get accurate tuning of the analog 1v/octave pitch output, it must be calibrated using digital multimeter, or an electronic tuner and well calibrated oscillator.

### Multimeter

Connect a 3.5mm TS cable to the PITCH output of the Super Sixteen. Set your multimeter to read DC volts (10V range minimum). Connect the negative/ground/common (black) input of the multimeter to the SLEEVE of the TS cable using an alligator clip. Connect the positive/red input of the multimeter to the TIP of the cable.

### Electronic tuner

Connect the PITCH output to the 1V/OCT input of a well-calibrated oscillator. Using a simple waveform (like a sine or triangle wave), connect the output of the oscillator to a digital tuner. (Make sure to attenuate the output if necessary, as eurorack level signals can damage equipment made for instrument or line level inputs).
Enter calibrate mode on the Super Sixteen and select the lowest output voltage (button 1). Turn on the tuner and use the COARSE tune of the oscillator to set the pitch to the lowest note that the tuner can easily pick up. Use the FINE tune of the oscillator to set it to an exact concert pitch (typically C1 or A1).

Press SHIFT+14 to enter calibration mode. In this mode buttons 1-9 let you choose different octaves, which will set the PITCH output to exact voltages, from 0v, 1v, 2v, 3v up to 8v.
Press 1 and use the encoder to set the calibration of the lowest step to zero (0). The lowest possible output of the DAC is not very accurate at 0v, and cannot be made to go lower (this will cause it to “wrap around” to 8V, so avoid this at all costs! Because of this limitiation, this lowest octave is the least accurate range.
Press 2 and use the encoder to set the calibration to exactly 1 volt, or 1 octave above your tuned pitch at 0V. It is common to have to adjust by 5-20 “units” of correction. Each unit represents about 0.002 volts, or about 3 cents of concert pitch.
Press 3 and repeat the tuning at 2 volts. Continue all the way up to 9 (8 volts). You may have to tune your oscillator lower than initially in order to use your tuner at the top of the pitch range.
IMPORTANT: When you are satisfied that all octaves are playing in tune, press SAVE to store the calibration values to memory. These values are saved to EEPROM and will persist even after a factory reset. If you have made and error and want to discard the new calibration values, press SHIFT to return to sequence mode.

# specifications

Dimensions:
Height 129.5mm
Width 102mm / 20 HP (horizontal pitch) Rear Depth 38mm
Front Depth 16mm (aka knob height)
Total Depth 55mm
Electrical characteristics:
Max current draw: 90mA (+12v) / 5mA (-12v) Pitch output voltage: 0-8 volts
CV output voltage: 0-8 volts
Gate output voltage: 0-5 volts
Clock output voltage: 0-5 volts Clock input voltage: 10v maximum Reset input voltage: 10v maximum

Copyright 2020, Extralife Instruments, LLC

Power connector:
Super Sixteen requires a standard “Eurorack” -12V / +12V power supply (2x5 pin connector). The red stripe of the ribbon cable (-12V side) must be oriented on the same side as the “Red stripe” marking on the circuit board. The complete manual can be found online at:
http://extralifeinstruments.com/docs/super-sixteen/manual.pdf

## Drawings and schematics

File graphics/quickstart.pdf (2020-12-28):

# extralife instruments

## Quick Start Guide 1.0

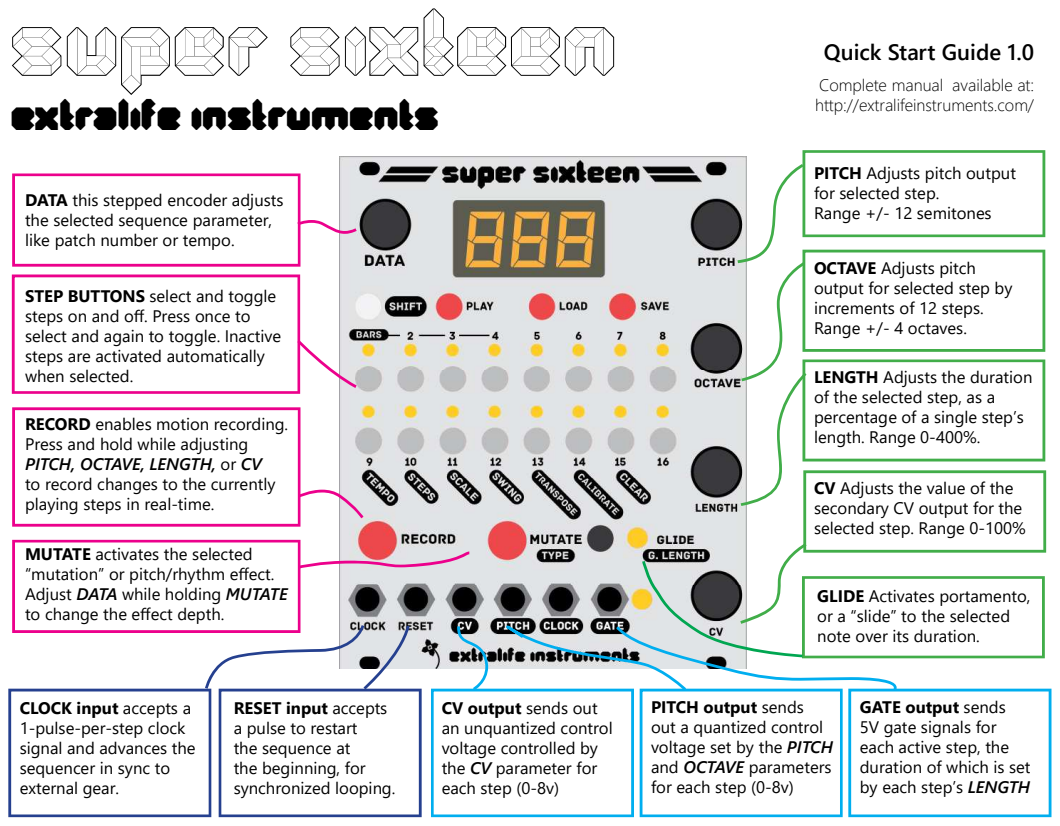
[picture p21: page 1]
SUPER SIXTEEN

Complete manual available at:
http://extralifeinstruments.com/

PITCH Adjusts pitch output
for selected step.

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

OCTAVE Adjusts pitch
output for selected step by
increments of 12 steps.
Range +/- 4 octaves.

STEP BUTTONS select and toggle
steps on and off . Press once to
select and again to toggle. Inactive
steps are activated automatically
when selected.

LENGTH Adjusts the duration
of the selected step, as a
percentage of a single step’s
length. Range 0-400%.

RECORD enables motion recording.
Press and hold while adjusting
PITCH, OCTAVE, LENGTH, or CV
to record changes to the currently
playing steps in real-time.

CV Adjusts the value of the
secondary CV output for the
selected step. Range 0-100%

MUTATE activates the selected
“mutation” or pitch/rhythm eff ect.
Adjust DATA while holding MUTATE
to change the eff ect depth.

GLIDE Activates portamento,
or a “slide” to the selected
note over its duration.

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

RESET input accepts
a pulse to restart
the sequence at
the beginning, for
synchronized looping.

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

GATE output sends
5V gate signals for
each active step, the
duration of which is set
by each step’s LENGTH

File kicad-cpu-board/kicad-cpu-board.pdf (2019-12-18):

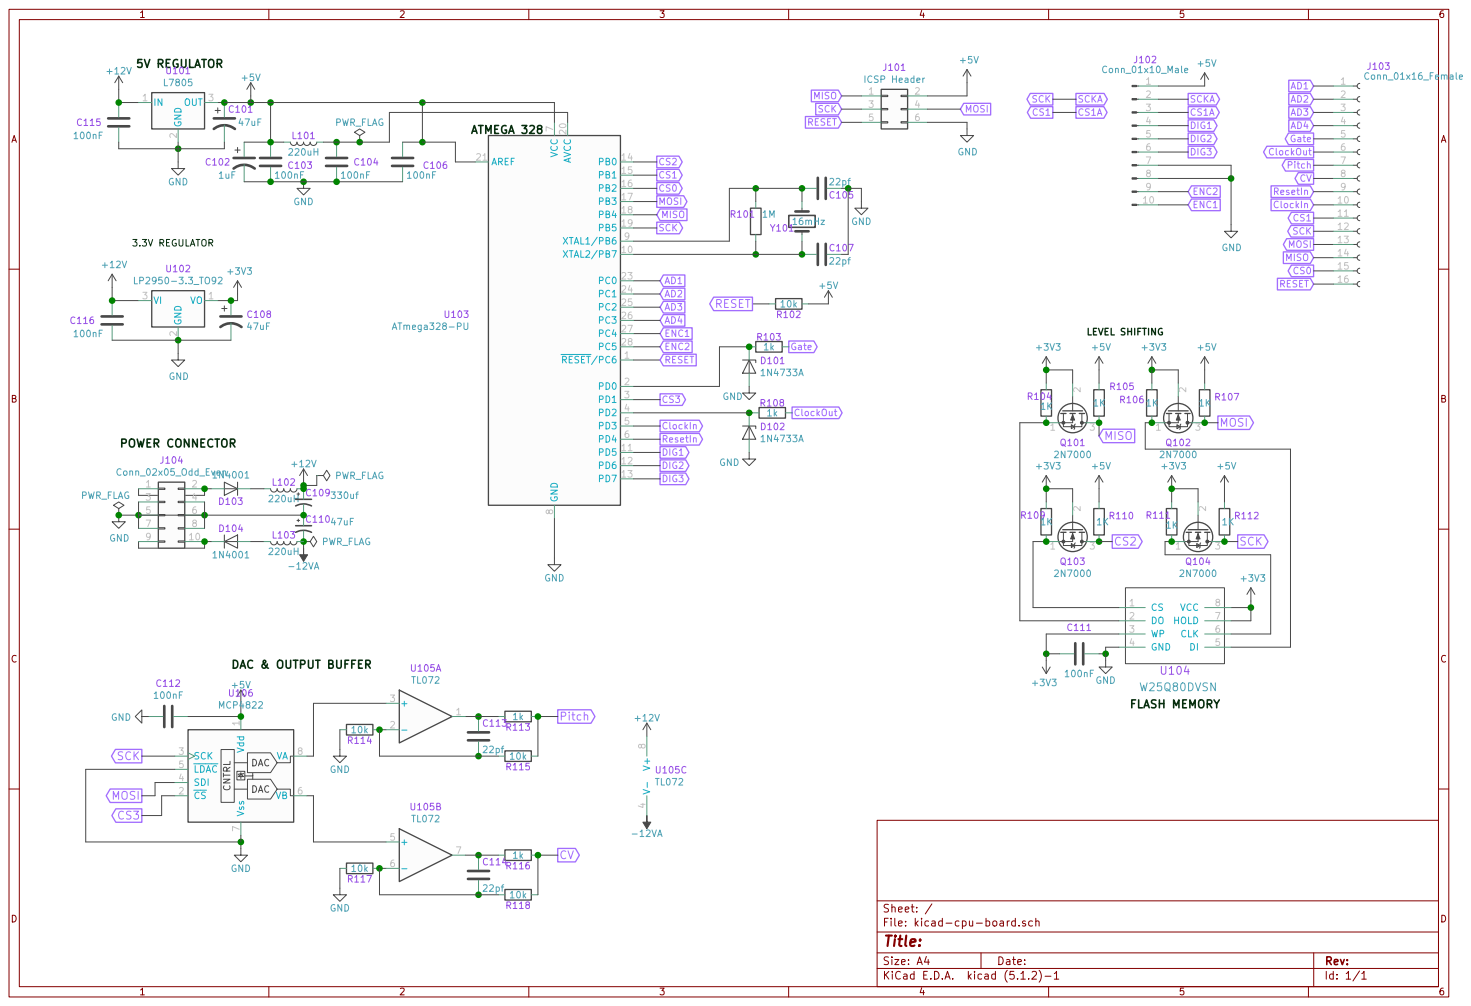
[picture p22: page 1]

5V REGULATOR
File: kicad-cpu-board.sch Sheet: / GND GND

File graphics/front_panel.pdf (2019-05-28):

## SUPER SIXTEEN

888

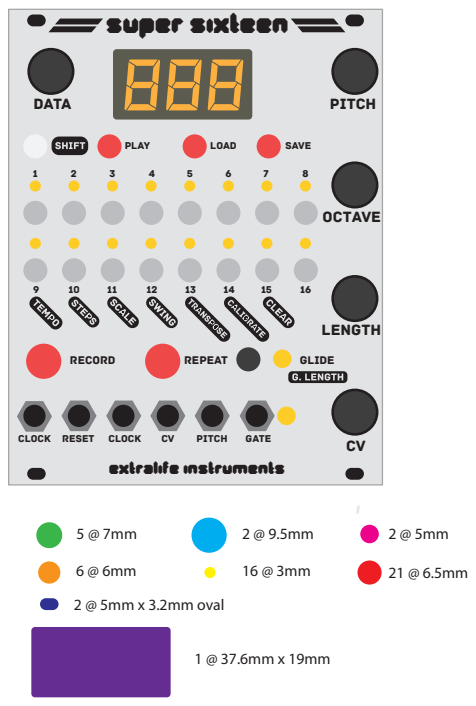
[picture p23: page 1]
2 @ 5mm x 3.2mm oval; data; PITCH; OCtAVE; LENGTH; PLAY; LOAD; SAVE; RECORD; REPEAT; GLIDE; CLOCK RESET CLOCK; GATE; EXTRALIFE INSTRUMENTS

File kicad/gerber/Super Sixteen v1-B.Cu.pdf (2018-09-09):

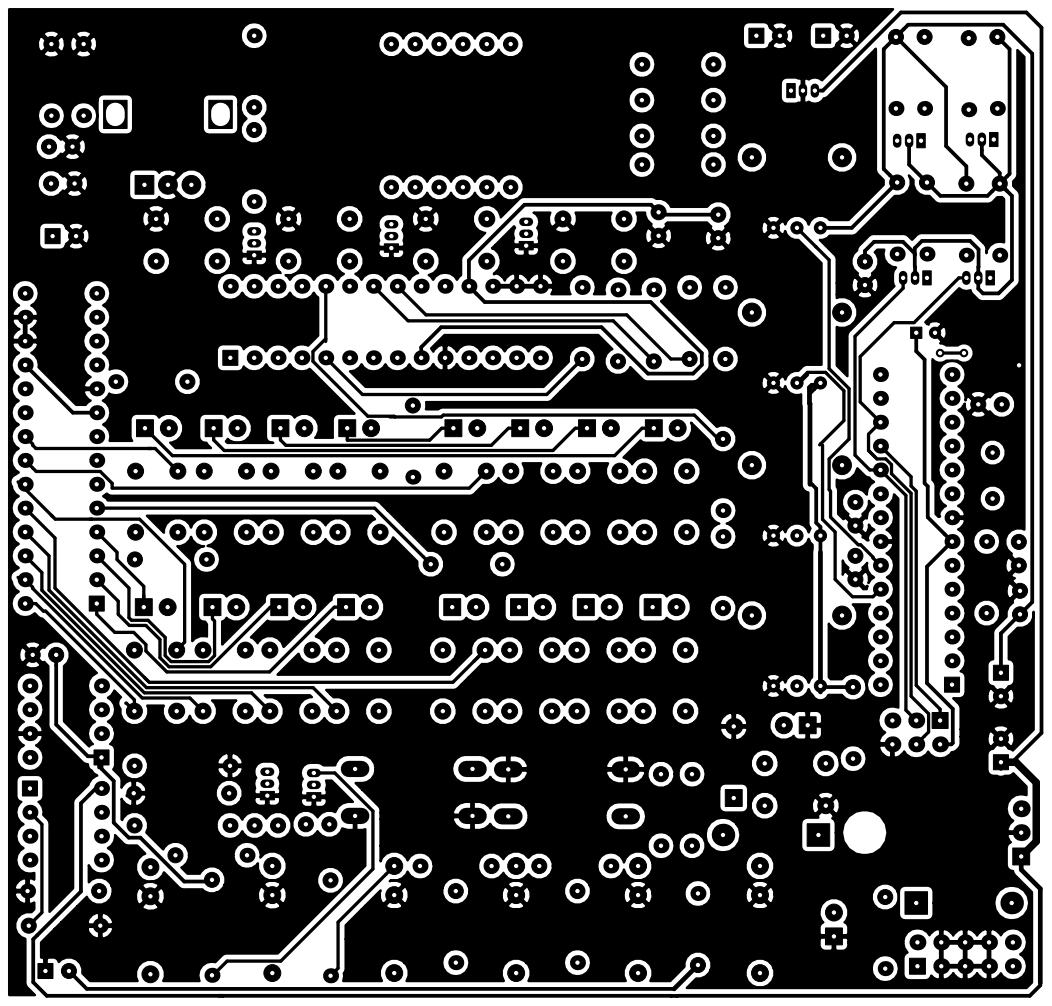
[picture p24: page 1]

File: Super Sixteen v1.kicad_pcb Sheet:
Id: 1/1 Title:

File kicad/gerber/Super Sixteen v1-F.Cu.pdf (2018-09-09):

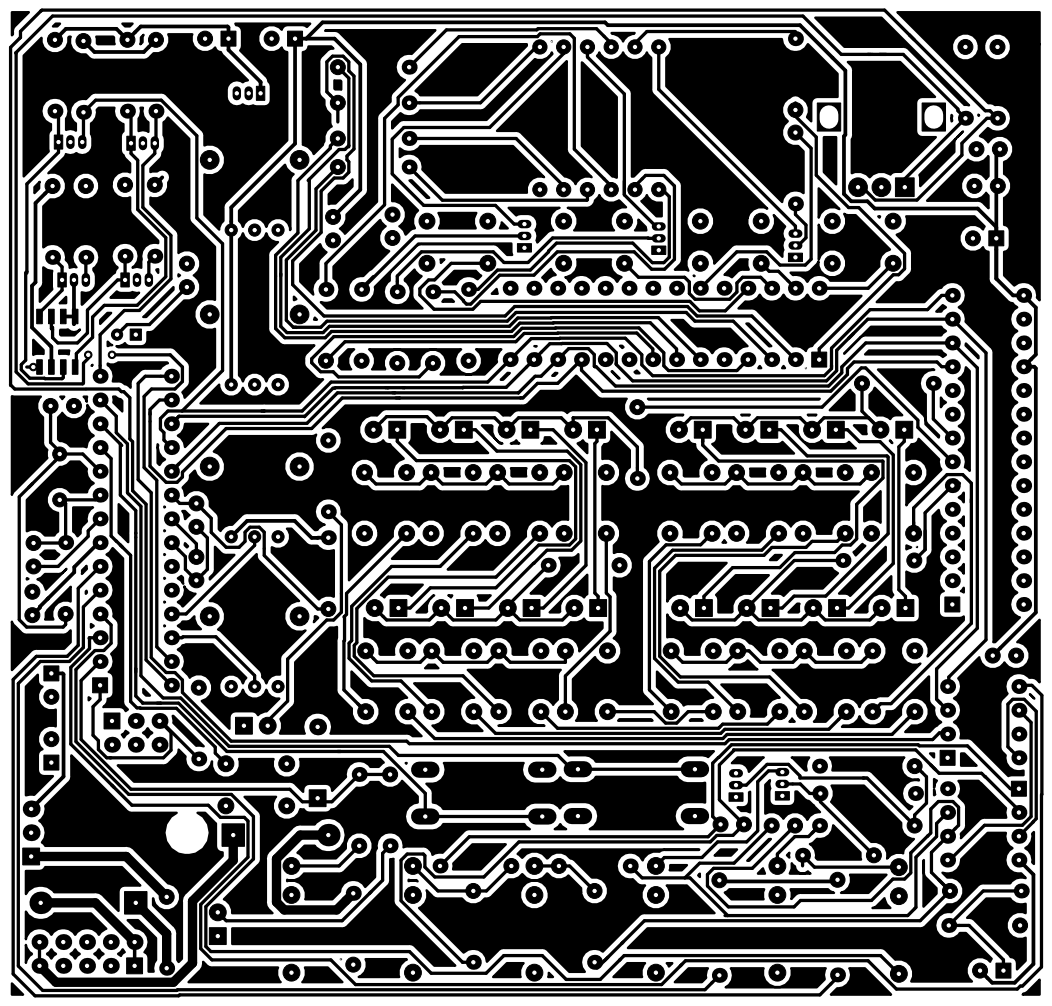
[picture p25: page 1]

File: Super Sixteen v1.kicad_pcb Sheet:
Id: 1/1 Title:

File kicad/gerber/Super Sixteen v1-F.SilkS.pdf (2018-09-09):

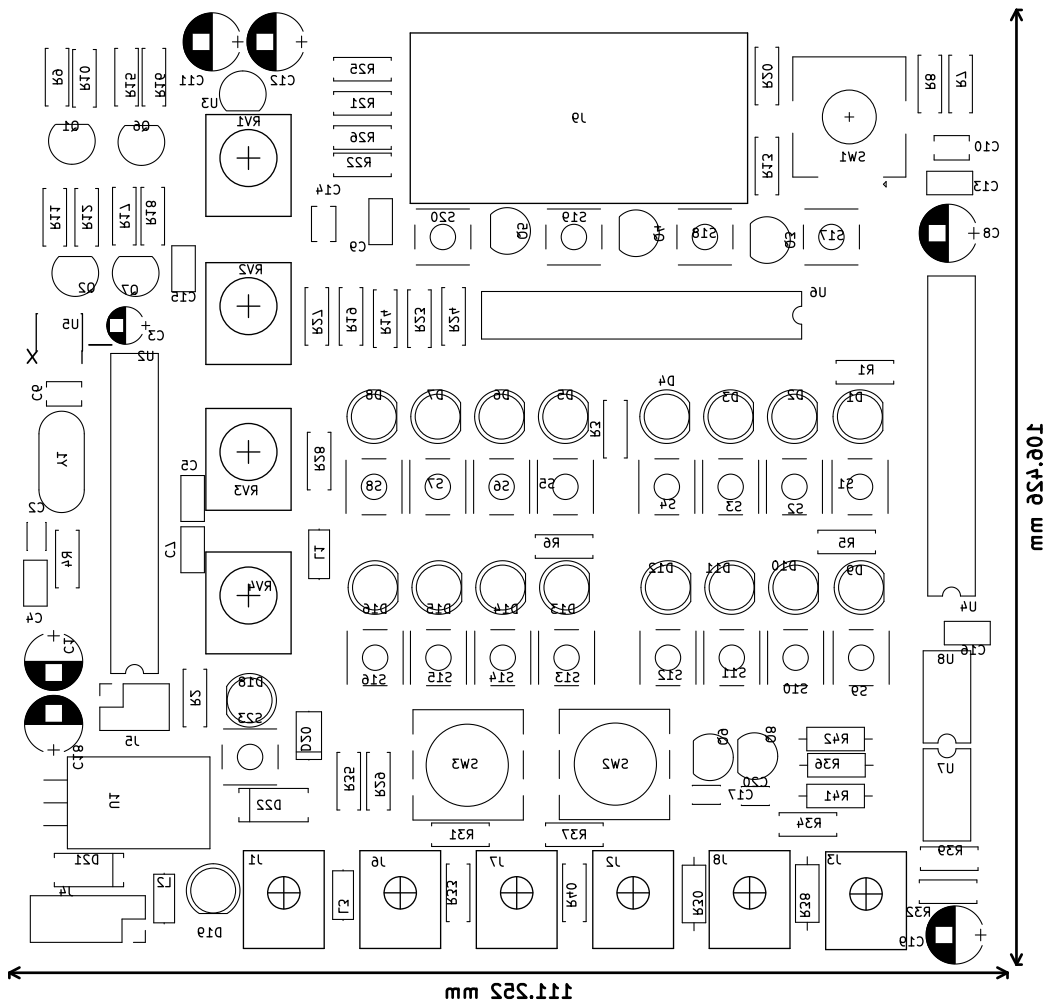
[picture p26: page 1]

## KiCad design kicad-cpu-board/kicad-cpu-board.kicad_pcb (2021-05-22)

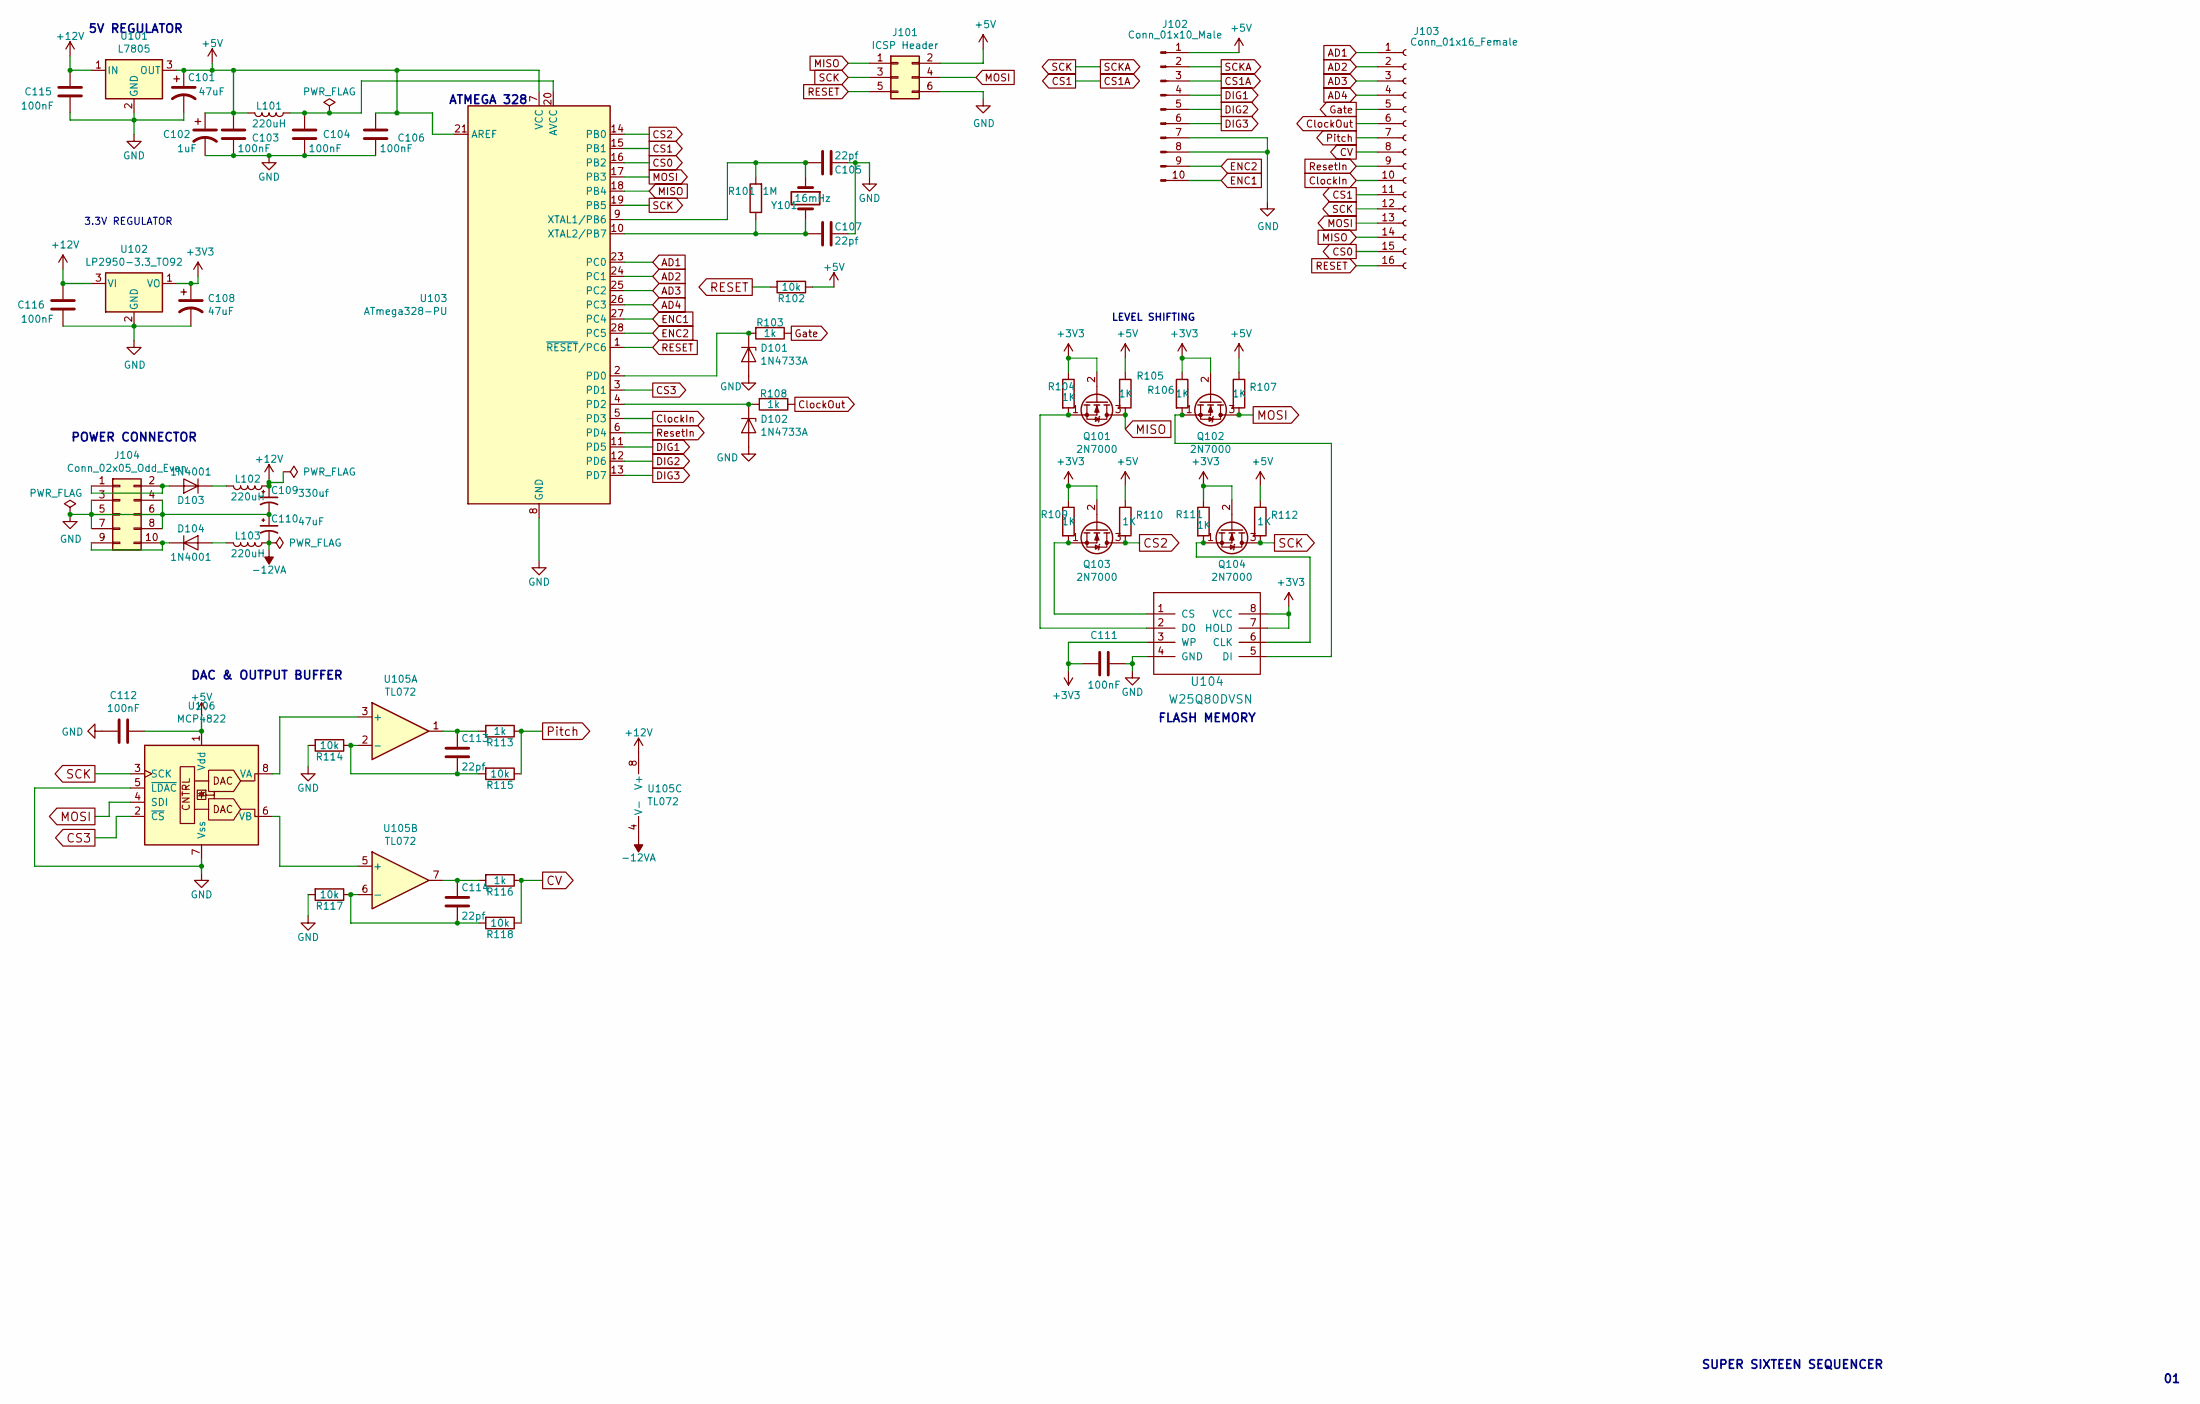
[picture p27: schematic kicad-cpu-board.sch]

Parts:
C101, C108, C110: 47uF; CP_Radial_D6.3mm_P2.50mm
C102: 1uF; CP_Radial_D4.0mm_P2.00mm
C103, C104, C106, C111, C112, C115, C116: 100nF; C_Disc_D5.0mm_W2.5mm_P2.50mm
C105, C113, C114: 22pf; C_Disc_D3.0mm_W2.0mm_P2.50mm
C107: 22pf; C_Disc_D3.8mm_W2.6mm_P2.50mm
C109: 330uf; CP_Radial_D6.3mm_P2.50mm
D101, D102: 1N4733A; D_A-405_P7.62mm_Horizontal
D103, D104: 1N4001; D_DO-15_P10.16mm_Horizontal
J101: ICSP Header; Pin_Header_Straight_2x03_Pitch2.54mm
J102: Conn_01x10_Male; Pin_Header_Straight_1x10_Pitch2.54mm
J103: Conn_01x16_Female; Pin_Header_Straight_1x16_Pitch2.54mm
J104: Conn_02x05_Odd_Even; Pin_Header_Straight_2x05_Pitch2.54mm
L101, L102, L103: 220uH; L_Axial_L6.6mm_D2.7mm_P10.16mm_Horizontal_Vishay_IM-2
Q101, Q102, Q103, Q104: 2N7000; TO-92_Inline_Wide
R101: 1M; R_Axial_DIN0207_L6.3mm_D2.5mm_P7.62mm_Horizontal
R102, R114, R115, R117, R118: 10k; R_Axial_DIN0207_L6.3mm_D2.5mm_P7.62mm_Horizontal
R103, R108, R113, R116: 1k; R_Axial_DIN0207_L6.3mm_D2.5mm_P7.62mm_Horizontal
R104, R105, R106, R107, R109, R110, R111, R112: 1K; R_Axial_DIN0207_L6.3mm_D2.5mm_P7.62mm_Horizontal
U101: L7805; TO-220-3_Horizontal
U102: LP2950-3.3_TO92; TO-92_Inline_Wide
U103: ATmega328-PU; DIP-28_W7.62mm
U104: W25Q80DVSN; SOIC-8_3.9x4.9mm_Pitch1.27mm
U105: TL072; DIP-8_W7.62mm
U106: MCP4822; DIP-8_W7.62mm
Y101: 16mHz; Crystal_HC18-U_Vertical

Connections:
+3V3: C108.1, C111.2, Q101.2 (G), Q102.2 (G), Q103.2 (G), Q104.2 (G), R104.1, R106.1, R109.1, R111.1, U102.1 (VO), U104.3 (WP), U104.7 (HOLD), U104.8 (VCC)
+5V: C101.1, C102.1, C103.1, C106.1, C112.1, J101.2, J102.1, L101.2, R102.1, R105.1, R107.1, R110.1, R112.1, U101.3 (OUT), U103.7 (VCC), U103.21 (AREF), U106.1 (Vdd)
+12V: C109.1, C115.1, C116.1, L102.1, U101.1 (IN), U102.3 (VI), U105.8 (V+)
-12VA: C110.2, L103.1, U105.4 (V-)
AD1: J103.1, U103.23 (PC0)
AD2: J103.2, U103.24 (PC1)
AD3: J103.3, U103.25 (PC2)
AD4: J103.4, U103.26 (PC3)
CS0: J103.15, U103.16 (PB2)
CS1: J102.3, J103.11, U103.15 (PB1)
CS2: Q103.3 (D), R110.2, U103.14 (PB0)
CS3: U103.3 (PD1), U106.2 (~CS)
CV: J103.8, R116.1, R118.1
ClockIn: J103.10, U103.5 (PD3)
ClockOut: J103.6, R108.1
DIG1: J102.4, U103.11 (PD5)
DIG2: J102.5, U103.12 (PD6)
DIG3: J102.6, U103.13 (PD7)
ENC1: J102.10, U103.27 (PC4)
ENC2: J102.9, U103.28 (PC5)
GND: C101.2, C102.2, C103.2, C104.2, C105.1, C106.2, C107.1, C108.2, C109.2, C110.1, C111.1, C112.2, C115.2, C116.2, D101.2 (A), D102.2 (A), J101.6, J102.7, J102.8, J104.3, J104.4, J104.5, J104.6, J104.7, J104.8, R114.2, R117.2, U101.2 (GND), U102.2 (GND), U103.8 (GND), U103.22 (GND), U104.4 (GND), U106.5 (~LDAC), U106.7 (Vss)
Gate: J103.5, R103.1
MISO: J101.1, J103.14, Q101.3 (D), R105.2, U103.18 (PB4)
MOSI: J101.4, J103.13, Q102.3 (D), R107.2, U103.17 (PB3), U106.4 (SDI)
unnamed: C104.1, L101.1, U103.20 (AVCC)
unnamed: C105.2, R101.2, U103.9 (XTAL1/PB6), Y101.1
unnamed: C107.2, R101.1, U103.10 (XTAL2/PB7), Y101.2
unnamed: C113.1, R113.2, U105.1
unnamed: C113.2, R114.1, R115.2, U105.2 (-)
unnamed: C114.1, R116.2, U105.7
unnamed: C114.2, R117.1, R118.2, U105.6 (-)
unnamed: D101.1 (K), R103.2, U103.2 (PD0)
unnamed: D102.1 (K), R108.2, U103.4 (PD2)
unnamed: D103.1 (K), L102.2
unnamed: D103.2 (A), J104.1, J104.2
unnamed: D104.1 (K), J104.9, J104.10
unnamed: D104.2 (A), L103.2
unnamed: Q101.1 (S), R104.2, U104.2 (DO)
unnamed: Q102.1 (S), R106.2, U104.5 (DI)
unnamed: Q103.1 (S), R109.2, U104.1 (CS)
unnamed: Q104.1 (S), R111.2, U104.6 (CLK)
unnamed: U105.3 (+), U106.8 (VA)
unnamed: U105.5 (+), U106.6 (VB)
Pitch: J103.7, R113.1, R115.1
RESET: J101.5, J103.16, R102.2, U103.1 (~RESET~/PC6)
ResetIn: J103.9, U103.6 (PD4)
SCK: J101.3, J102.2, J103.12, Q104.3 (D), R112.2, U103.19 (PB5), U106.3 (SCK)

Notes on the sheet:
5V REGULATOR
ATMEGA 328
FLASH MEMORY
LEVEL SHIFTING
DAC & OUTPUT BUFFER
3.3V REGULATOR
SUPER SIXTEEN SEQUENCER
POWER CONNECTOR

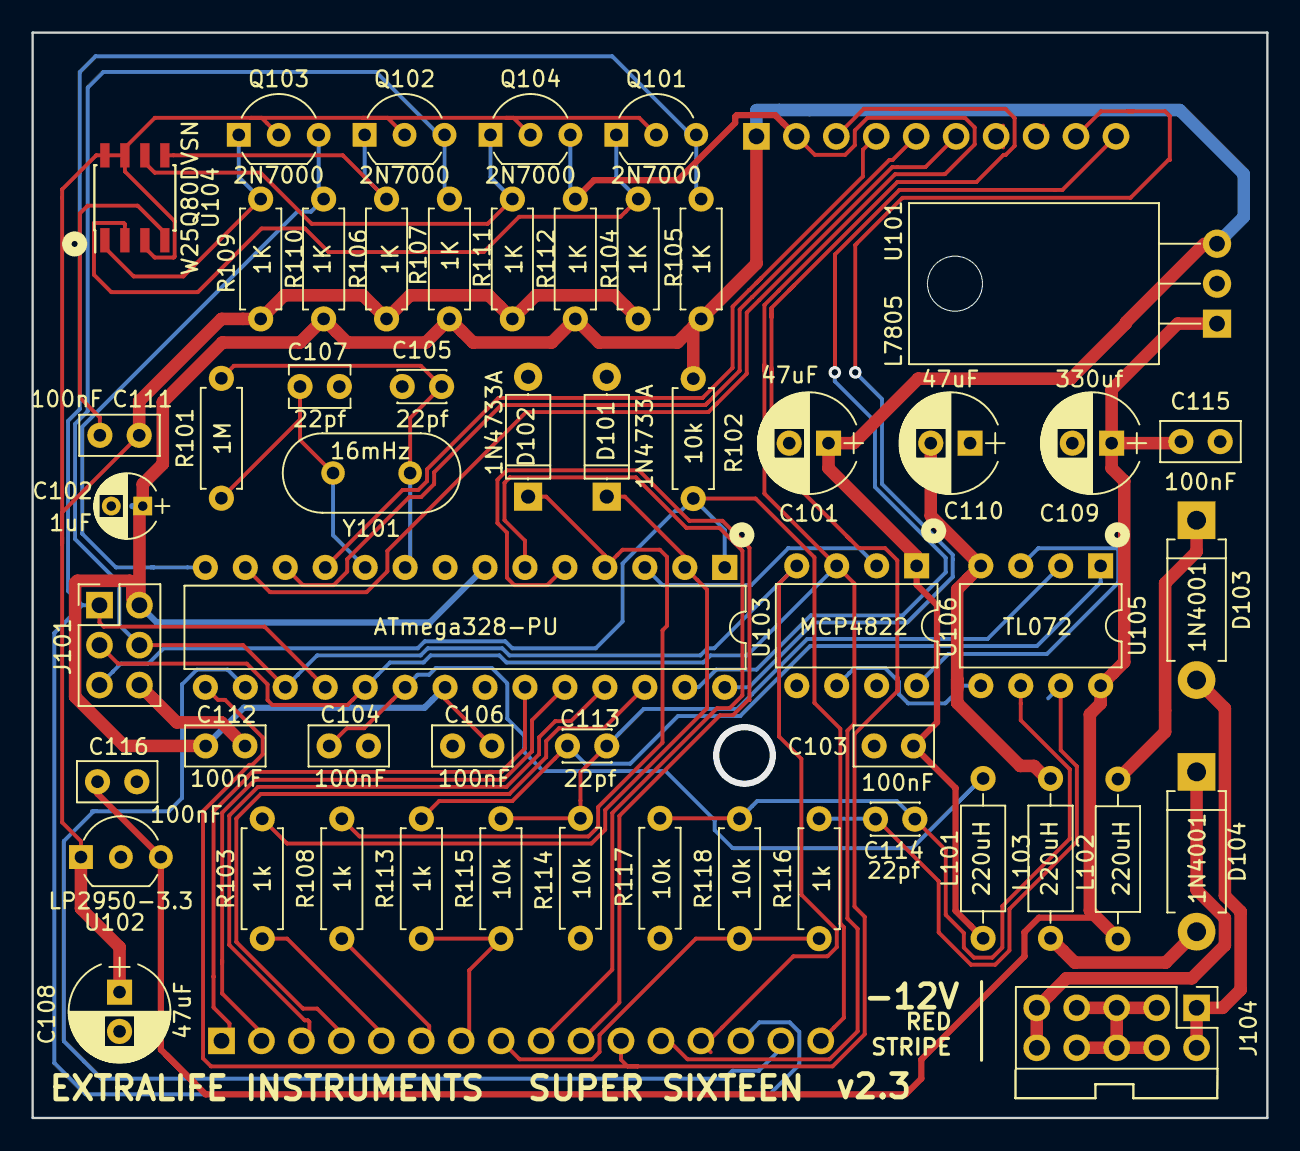
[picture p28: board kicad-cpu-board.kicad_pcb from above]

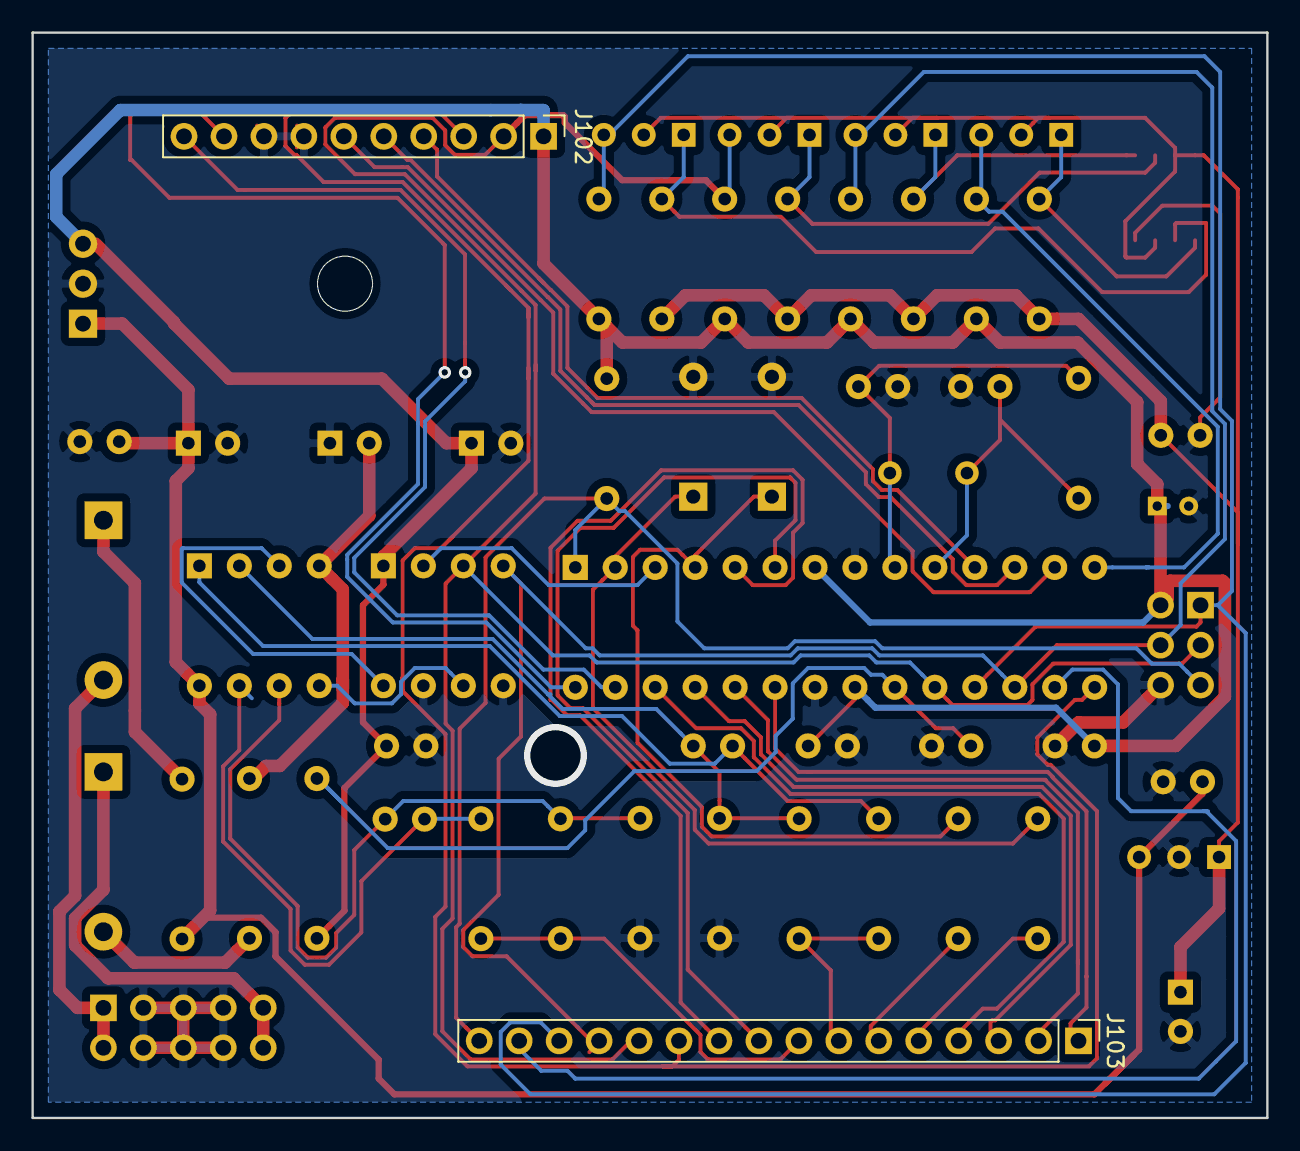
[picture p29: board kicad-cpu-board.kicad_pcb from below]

Board: 2 copper layers, 78.5 x 69.0 mm, 56 parts (2 on the bottom side), 47 nets.

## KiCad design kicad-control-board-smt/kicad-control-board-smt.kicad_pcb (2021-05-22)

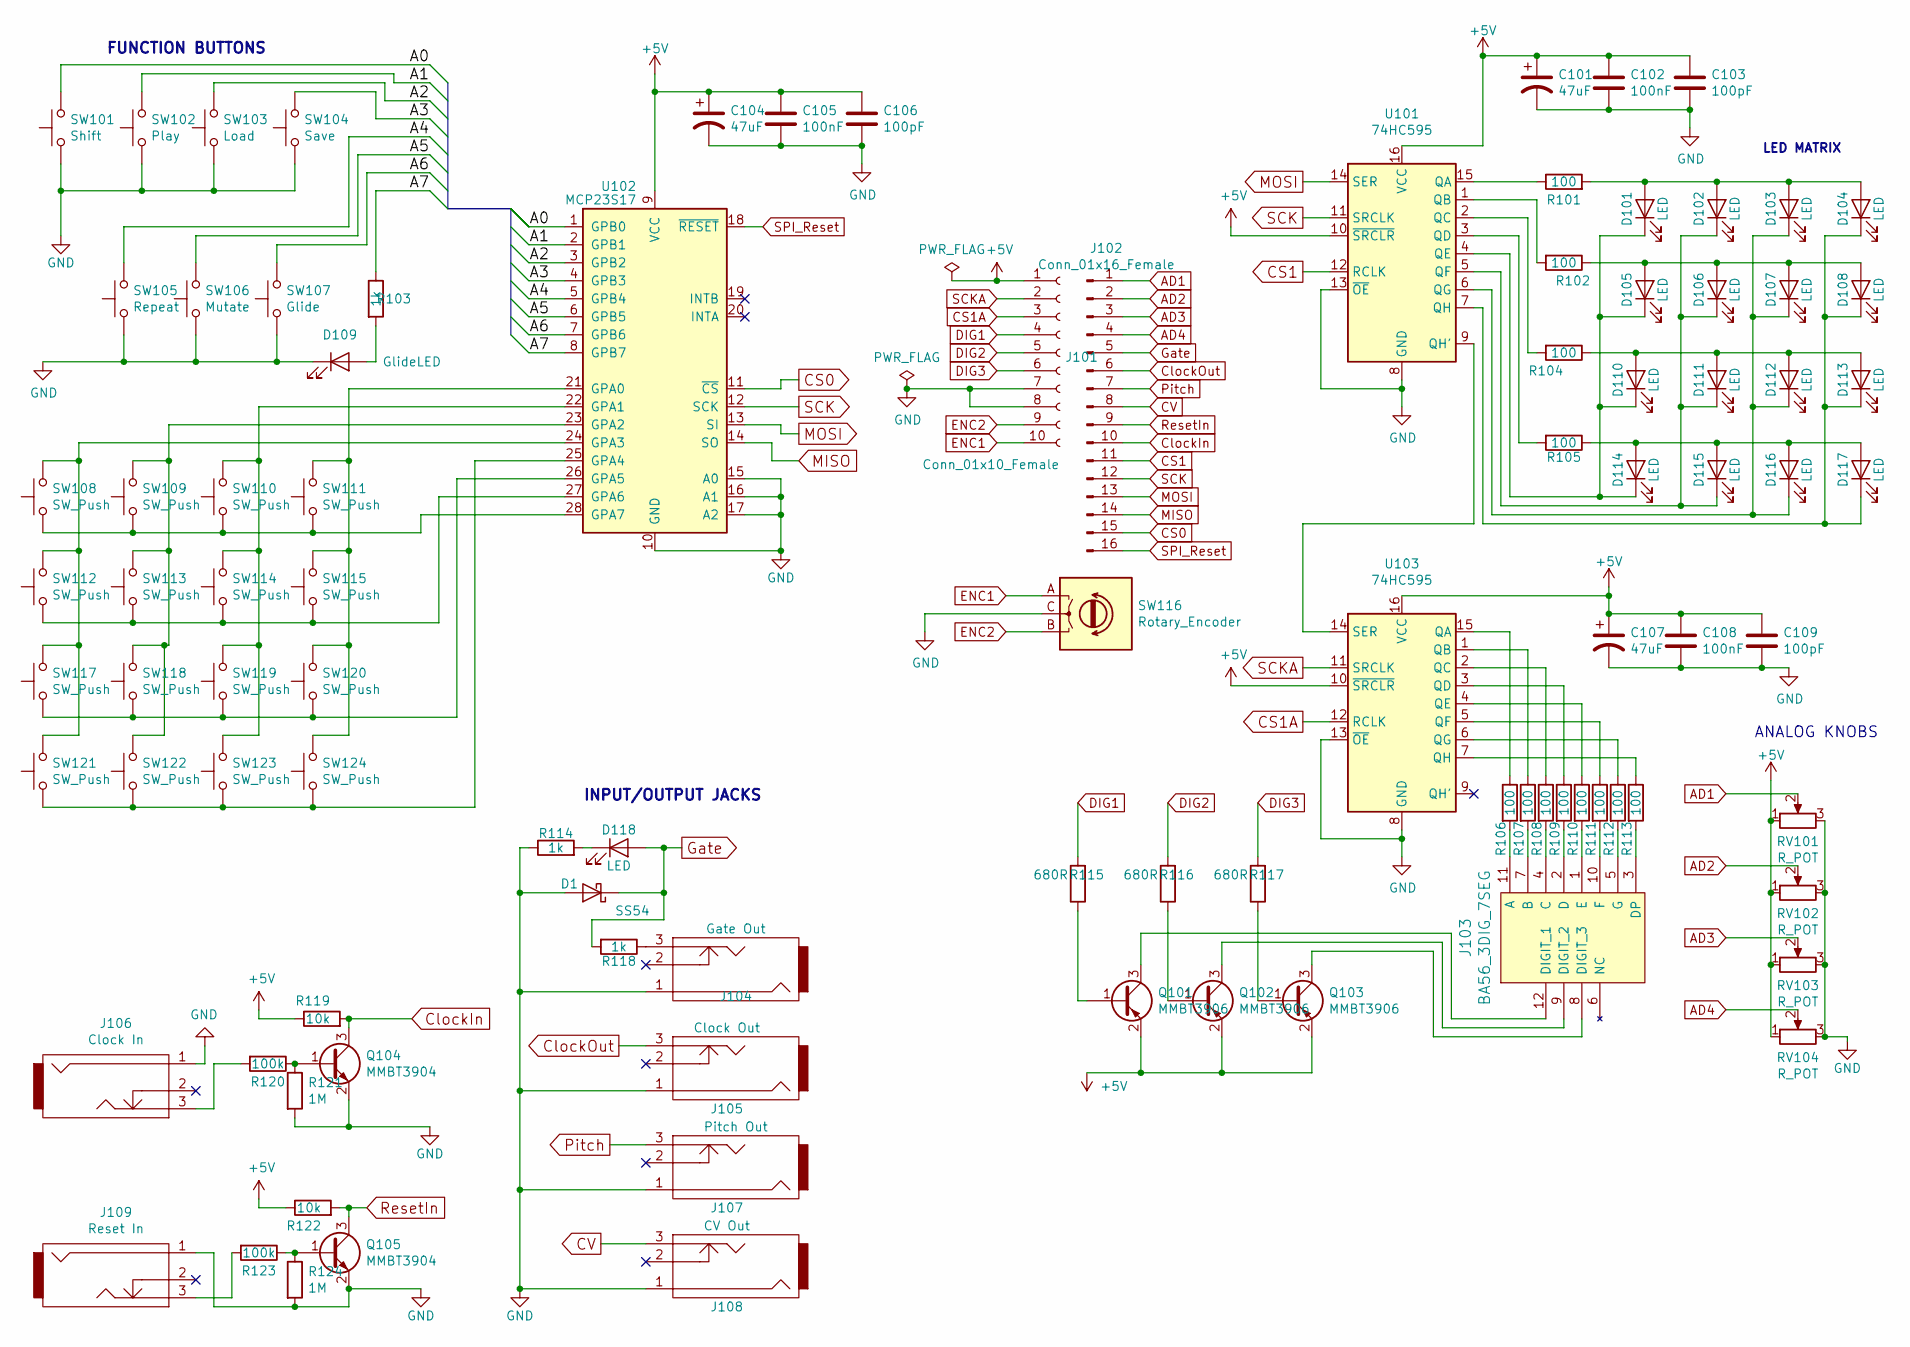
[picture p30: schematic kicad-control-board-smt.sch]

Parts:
C101, C104, C107: 47uF; CP_Elec_6.3x7.7; MFG Part Number VES470M1HTR-0607; LCSC Part Number C108053
C102, C105, C108: 100nF; C_0603_HandSoldering; MFG Part Number C0603C104Z3VACTU; LCSC Part Number C14663
C103, C106, C109: 100pF; C_0603_HandSoldering; MFG Part Number C0603C101J1GACTU; LCSC Part Number C14858
D1: SS54; D_SMA_Handsoldering; MFG Part Number TSS54U RGG; Digikey Part Number TSS54URGGDKR-ND
D101, D102, D103, D104, D105, D106, D107, D108, D110, D111, D112, D113, D114, D115, D116, D117, D118: LED; LED_D3.0mm; MFG Part Number C503B-AAS-CY0B0251; Digikey Part Number C503B-AAS-CY0B0251-ND
D109: GlideLED; LED_D3.0mm; MFG Part Number C503B-AAS-CY0B0251; Digikey Part Number C503B-AAS-CY0B0251-ND
J101: Conn_01x10_Female; Pin_Header_Straight_1x10_Pitch2.54mm; MFG Part Number PPTC101LFBN-RC; Digikey Part Number S7008-ND
J102: Conn_01x16_Female; Pin_Header_Straight_1x16_Pitch2.54mm; MFG Part Number PPTC161LFBN-RC; Digikey Part Number S7014-ND
J103: BA56_3DIG_7SEG; MFG Part Number BA56-12GWA; Digikey Part Number 754-1656-5-ND
J104: Gate Out; PJ301M-12; MFG Part Number WQP-WQP518MA; Digikey Part Number N/A
J105: Clock Out; PJ301M-12; MFG Part Number WQP-WQP518MA; Digikey Part Number N/A
J106: Clock In; PJ301M-12; MFG Part Number WQP-WQP518MA; Digikey Part Number N/A
J107: Pitch Out; PJ301M-12; MFG Part Number WQP-WQP518MA; Digikey Part Number N/A
J108: CV Out; PJ301M-12; MFG Part Number WQP-WQP518MA; Digikey Part Number N/A
J109: Reset In; PJ301M-12; MFG Part Number WQP-WQP518MA; Digikey Part Number N/A
Q101, Q102, Q103: MMBT3906; SOT-23_Handsoldering; MFG Part Number MMBT3906LT1G; LCSC Part Number C53444
Q104, Q105: MMBT3904; SOT-23_Handsoldering; MFG Part Number MMBT3904LT3G; LCSC Part Number C20526
R101, R102, R104, R105, R106, R107, R108, R109, R110, R111, R112, R113: 100; R_0603_HandSoldering; MFG Part Number RMCF0603FT100R; LCSC Part Number C22775
R103, R114, R118: 1k; R_0603_HandSoldering; MFG Part Number RMCF0603FT1K00; Digikey Part Number RMCF0603FT1K00DKR-ND
R115, R116, R117: 680R; R_0603_HandSoldering; MFG Part Number RMCF0603FT680R; LCSC Part Number C23228
R119, R122: 10k; R_0603_HandSoldering; MFG Part Number RMCF0603FT10K0; LCSC Part Number C25804
R120, R123: 100k; R_0603_HandSoldering; MFG Part Number RMCF0603FG100K; LCSC Part Number C25803
R121, R124: 1M; R_0603_HandSoldering; MFG Part Number RMCF0603FT1M00; LCSC Part Number C22935
RV101, RV102, RV103, RV104: R_POT; Potentiometer_Alps_RK09K_Horizontal; MFG Part Number RV09AF-40-20K-B100K; Digikey Part Number N/A
SW101: Shift; SW_PUSH_6mm; MFG Part Number TL1105SPF160Q; Digikey Part Number EG1861-ND
SW102: Play; SW_PUSH_6mm; MFG Part Number TL1105SPF160Q; Digikey Part Number EG1861-ND
SW103: Load; SW_PUSH_6mm; MFG Part Number TL1105SPF160Q; Digikey Part Number EG1861-ND
SW104: Save; SW_PUSH_6mm; MFG Part Number TL1105SPF160Q; Digikey Part Number EG1861-ND
SW105: Repeat; Push_E-Switch_KS01Q01; MFG Part Number D6R40 F2 LFS; Digikey Part Number 401-1992-ND
SW106: Mutate; Push_E-Switch_KS01Q01; MFG Part Number D6R40 F2 LFS; Digikey Part Number 401-1992-ND
SW107: Glide; SW_PUSH_6mm; MFG Part Number TL1105SPF160Q; Digikey Part Number EG1861-ND
SW108, SW109, SW110, SW111, SW112, SW113, SW114, SW115, SW117, SW118, SW119, SW120, SW121, SW122, SW123, SW124: SW_Push; SW_PUSH_6mm; MFG Part Number TL1105SPF160Q; Digikey Part Number EG1861-ND
SW116: Rotary_Encoder; RotaryEncoder_Alps_EC12E_Vertical_H20mm; MFG Part Number PEC11R-4215F-N0024; Digikey Part Number PEC11R-4215F-N0024-ND
U101, U103: 74HC595; SOIC-16_3.9x9.9mm_Pitch1.27mm; MFG Part Number 74HC595D,118; LCSC Part Number C5947
U102: MCP23S17; SOIC-28W_7.5x18.7mm_Pitch1.27mm; MFG Part Number MCP23S17-E/SO; LCSC Part Number C145413

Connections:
+5V: C101.1, C102.1, C103.1, C104.1, C105.1, C106.1, C107.1, C108.1, C109.1, J101.1, Q101.2 (E), Q102.2 (E), Q103.2 (E), R119.1, R122.1, RV101.1, RV102.1, RV103.1, RV104.1, U101.10 (~SRCLR), U101.16 (VCC), U102.9 (VCC), U103.10 (~SRCLR), U103.16 (VCC)
/A0: SW101.2, U102.1 (GPB0)
/A1: SW102.2, U102.2 (GPB1)
/A2: SW103.2, U102.3 (GPB2)
/A3: SW104.2, U102.4 (GPB3)
/A4: SW105.2, U102.5 (GPB4)
/A5: SW106.2, U102.6 (GPB5)
/A6: SW107.2, U102.7 (GPB6)
/A7: R103.1, U102.8 (GPB7)
AD1: J102.1, RV101.2
AD2: J102.2, RV102.2
AD3: J102.3, RV103.2
AD4: J102.4, RV104.2
CS0: J102.15, U102.11 (~CS)
CS1: J102.11, U101.12 (RCLK)
CS1A: J101.3, U103.12 (RCLK)
CV: J102.8, J108.3
ClockIn: J102.10, Q104.3 (C), R119.2
ClockOut: J102.6, J105.3
DIG1: J101.4, R115.2
DIG2: J101.5, R116.2
DIG3: J101.6, R117.2
ENC1: J101.10, SW116.A
ENC2: J101.9, SW116.B
GND: C101.2, C102.2, C103.2, C104.2, C105.2, C106.2, C107.2, C108.2, C109.2, D1.2 (A), D109.1 (K), J101.7, J101.8, J104.1, J105.1, J106.1, J107.1, J108.1, J109.1, Q104.2 (E), Q105.2 (E), R114.1, R121.2, R124.2, RV101.3, RV102.3, RV103.3, RV104.3, SW101.1, SW102.1, SW103.1, SW104.1, SW105.1, SW106.1, SW107.1, SW116.C, U101.8 (GND), U101.13 (~OE), U102.10 (GND), U102.15 (A0), U102.16 (A1), U102.17 (A2), U103.8 (GND), U103.13 (~OE)
Gate: D1.1 (K), D118.2 (A), J102.5, R118.2
MISO: J102.14, U102.14 (SO)
MOSI: J102.13, U101.14 (SER), U102.13 (SI)
unnamed: D101.1 (K), D105.1 (K), D110.1 (K), D114.1 (K), U101.4 (QE)
unnamed: D101.2 (A), D102.2 (A), D103.2 (A), D104.2 (A), R101.2
unnamed: D102.1 (K), D106.1 (K), D111.1 (K), D115.1 (K), U101.5 (QF)
unnamed: D103.1 (K), D107.1 (K), D112.1 (K), D116.1 (K), U101.6 (QG)
unnamed: D104.1 (K), D108.1 (K), D113.1 (K), D117.1 (K), U101.7 (QH)
unnamed: D105.2 (A), D106.2 (A), D107.2 (A), D108.2 (A), R102.1
unnamed: D109.2 (A), R103.2
unnamed: D110.2 (A), D111.2 (A), D112.2 (A), D113.2 (A), R104.1
unnamed: D114.2 (A), D115.2 (A), D116.2 (A), D117.2 (A), R105.1
unnamed: D118.1 (K), R114.2
unnamed: J103.1 (E), R110.2
unnamed: J103.2 (D), R109.2
unnamed: J103.3 (DP), R113.2
unnamed: J103.4 (C), R108.2
unnamed: J103.5 (G), R112.2
unnamed: J103.7 (B), R107.2
unnamed: J103.8 (DIGIT_3), Q103.3 (C)
unnamed: J103.9 (DIGIT_2), Q102.3 (C)
unnamed: J103.10 (F), R111.2
unnamed: J103.11 (A), R106.2
unnamed: J103.12 (DIGIT_1), Q101.3 (C)
unnamed: J104.3, R118.1
unnamed: J106.3, R120.2
unnamed: J109.3, R123.2
unnamed: Q101.1 (B), R115.1
unnamed: Q102.1 (B), R116.1
unnamed: Q103.1 (B), R117.1
unnamed: Q104.1 (B), R120.1, R121.1
unnamed: Q105.1 (B), R123.1, R124.1
unnamed: R101.1, U101.15 (QA)
unnamed: R102.2, U101.1 (QB)
unnamed: R104.2, U101.2 (QC)
unnamed: R105.2, U101.3 (QD)
unnamed: R106.1, U103.15 (QA)
unnamed: R107.1, U103.1 (QB)
unnamed: R108.1, U103.2 (QC)
unnamed: R109.1, U103.3 (QD)
unnamed: R110.1, U103.4 (QE)
unnamed: R111.1, U103.5 (QF)
unnamed: R112.1, U103.6 (QG)
unnamed: R113.1, U103.7 (QH)
unnamed: SW108.1, SW109.1, SW110.1, SW111.1, U102.28 (GPA7)
unnamed: SW108.2, SW112.2, SW117.2, SW121.2, U102.24 (GPA3)
unnamed: SW109.2, SW113.2, SW118.2, SW122.2, U102.23 (GPA2)
unnamed: SW110.2, SW114.2, SW119.2, SW123.2, U102.22 (GPA1)
unnamed: SW111.2, SW115.2, SW120.2, SW124.2, U102.21 (GPA0)
unnamed: SW112.1, SW113.1, SW114.1, SW115.1, U102.27 (GPA6)
unnamed: SW117.1, SW118.1, SW119.1, SW120.1, U102.26 (GPA5)
unnamed: SW121.1, SW122.1, SW123.1, SW124.1, U102.25 (GPA4)
unnamed: U101.9 (QH'), U103.14 (SER)
Pitch: J102.7, J107.3
ResetIn: J102.9, Q105.3 (C), R122.2
SCK: J102.12, U101.11 (SRCLK), U102.12 (SCK)
SCKA: J101.2, U103.11 (SRCLK)
SPI_Reset: J102.16, U102.18 (~RESET)

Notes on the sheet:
ANALOG KNOBS
FUNCTION BUTTONS
INPUT/OUTPUT JACKS
LED MATRIX

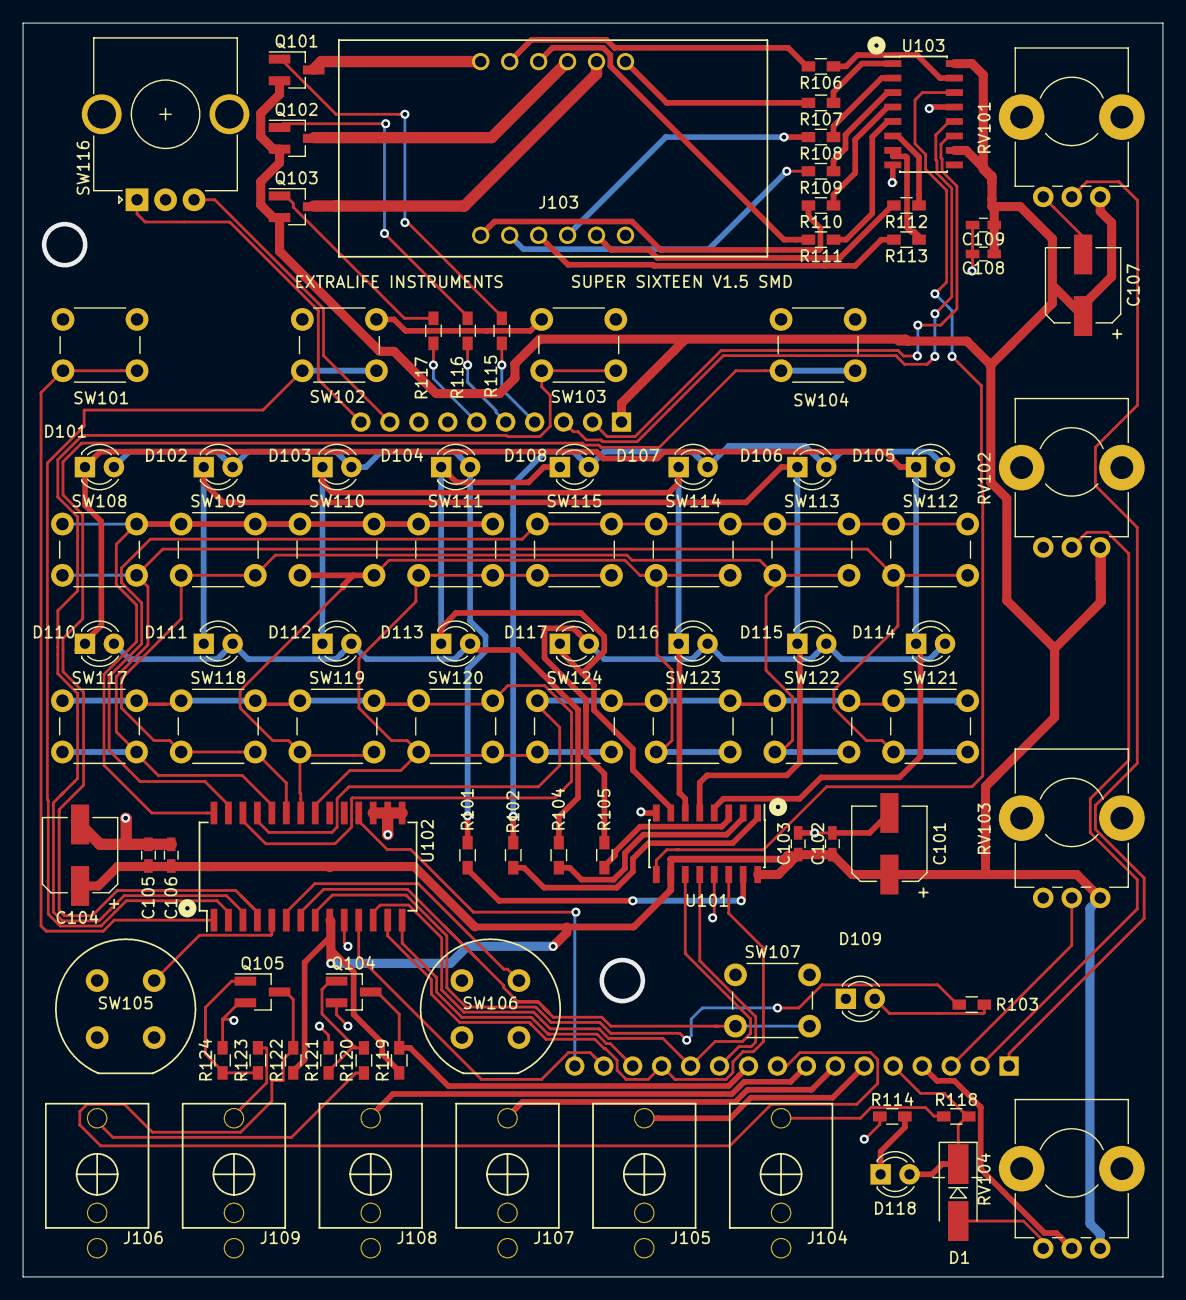
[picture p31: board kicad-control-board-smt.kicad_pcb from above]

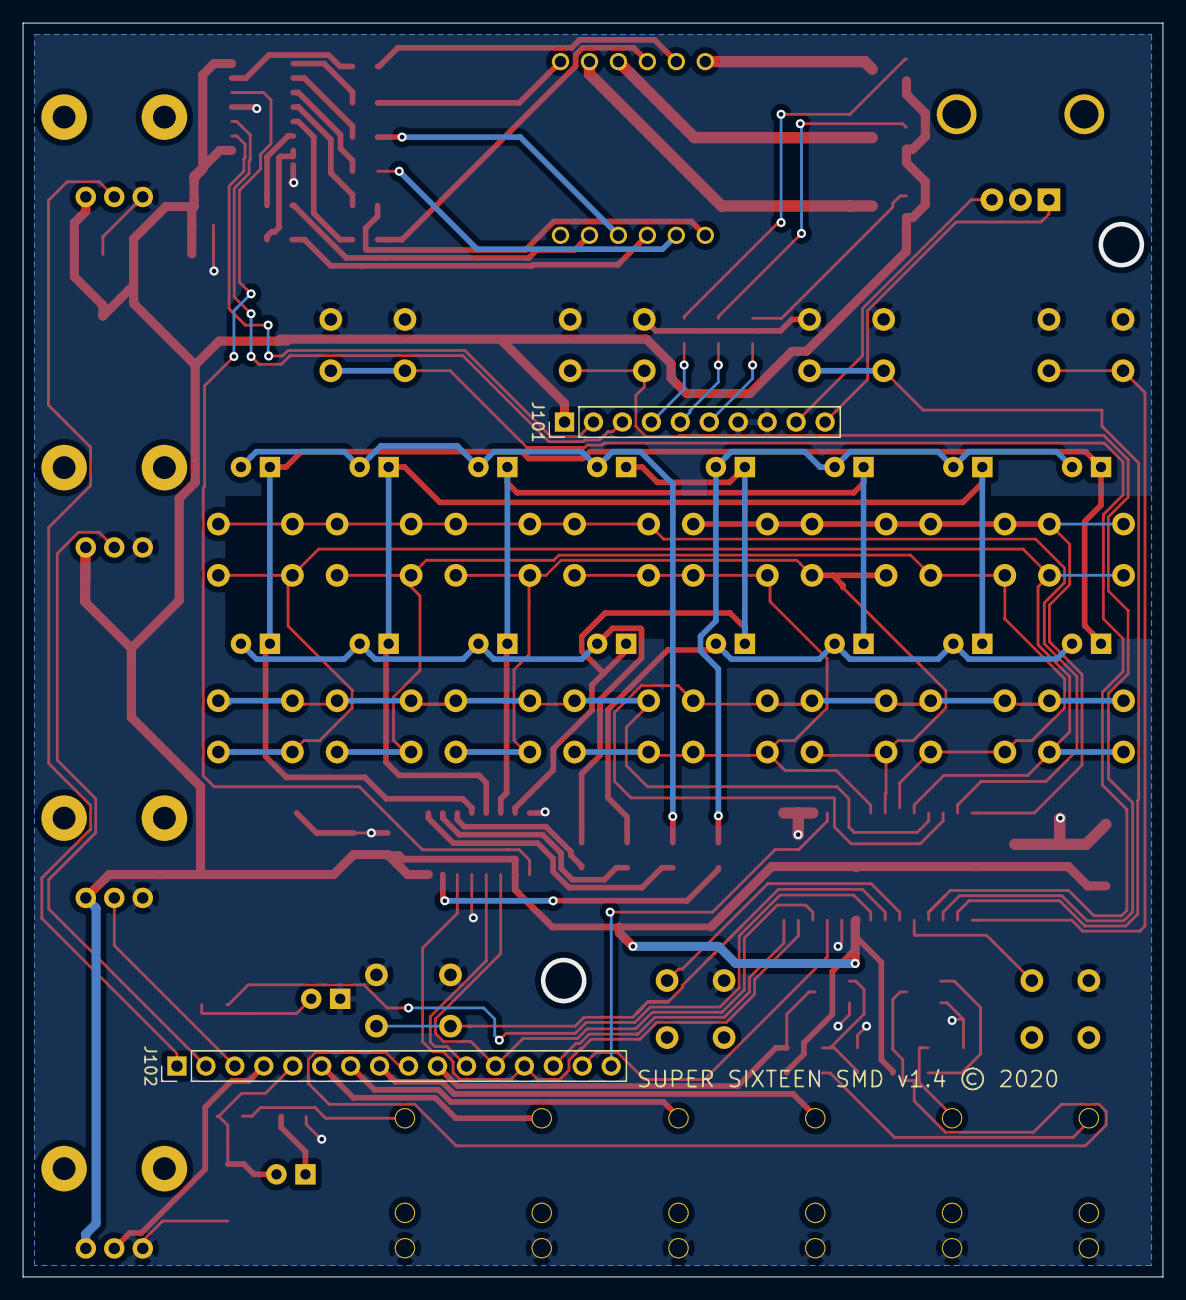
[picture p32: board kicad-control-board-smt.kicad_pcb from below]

Board: 2 copper layers, 100.0 x 110.0 mm, 97 parts (2 on the bottom side), 83 nets.

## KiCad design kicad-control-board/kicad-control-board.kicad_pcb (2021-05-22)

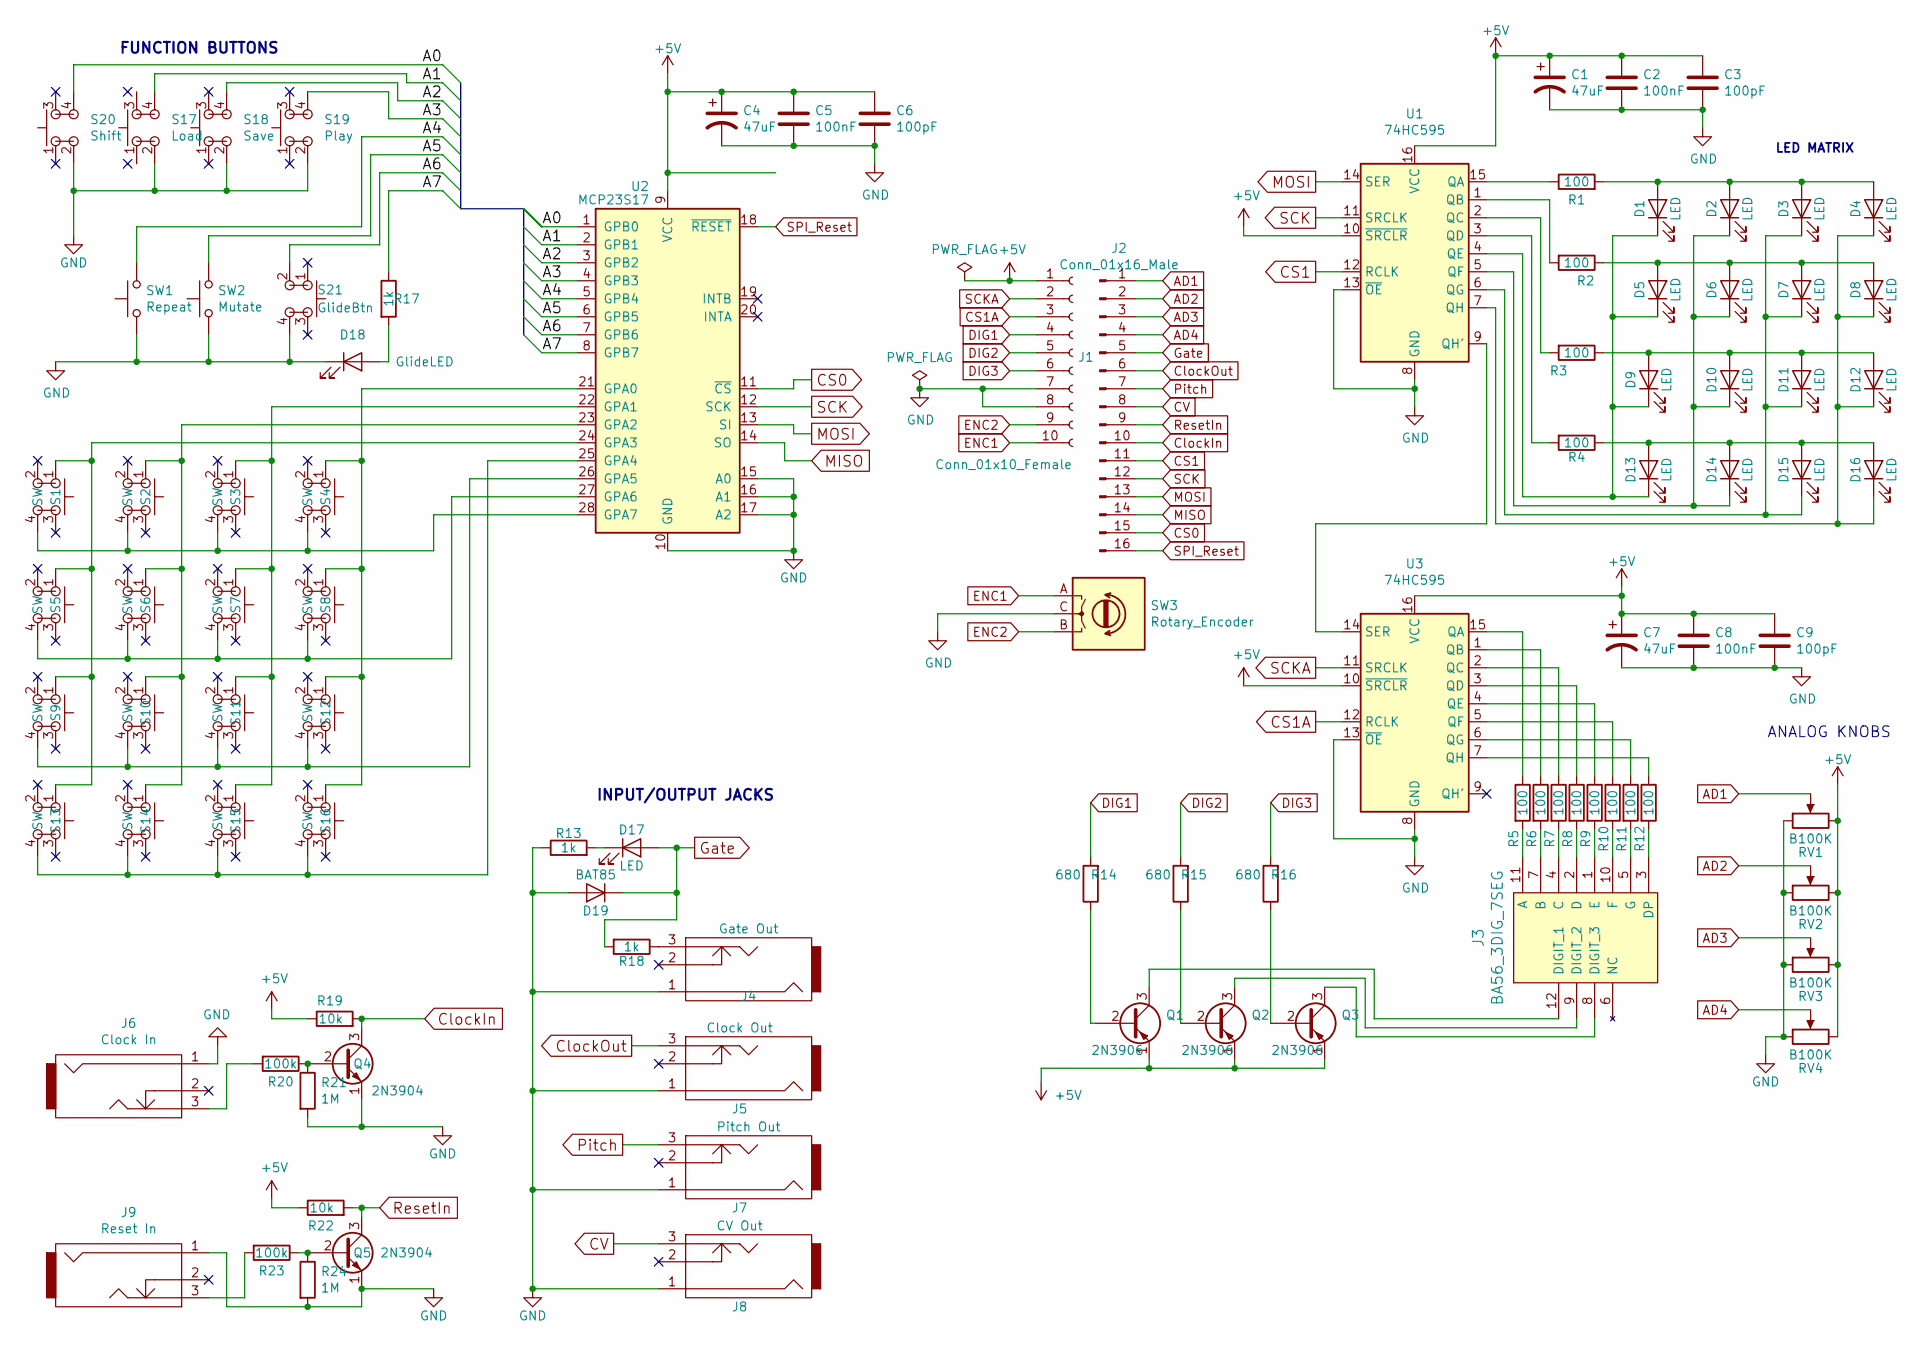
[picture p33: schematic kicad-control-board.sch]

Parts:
C1, C4, C7: 47uF; CP_Radial_D6.3mm_P2.50mm
C2, C5, C8: 100nF; C_Disc_D5.0mm_W2.5mm_P2.50mm
C3, C6, C9: 100pF; C_Disc_D5.0mm_W2.5mm_P2.50mm
D1, D2, D3, D4, D5, D6, D7, D8, D9, D10, D11, D12, D13, D14, D15, D16, D17: LED; LED3mm
D18: GlideLED; LED3mm
D19: BAT85; D_A-405_P7.62mm_Horizontal
J1: Conn_01x10_Female; Pin_Header_Straight_1x10_Pitch2.54mm
J2: Conn_01x16_Male; Pin_Header_Straight_1x16_Pitch2.54mm
J3: BA56_3DIG_7SEG
J4: Gate Out; PJ301M-12
J5: Clock Out; PJ301M-12
J6: Clock In; PJ301M-12
J7: Pitch Out; PJ301M-12
J8: CV Out; PJ301M-12
J9: Reset In; PJ301M-12
Q1, Q2, Q3: 2N3906; TO-92_Inline_Wide
Q4, Q5: 2N3904; TO-92_Inline_Wide
R1, R2, R3, R4, R5, R6, R7, R8, R9, R10, R11, R12: 100; R_Axial_DIN0204_L3.6mm_D1.6mm_P7.62mm_Horizontal
R13, R17, R18: 1k; R_Axial_DIN0204_L3.6mm_D1.6mm_P7.62mm_Horizontal
R14, R15, R16: 680; R_Axial_DIN0204_L3.6mm_D1.6mm_P7.62mm_Horizontal
R19, R22: 10k; R_Axial_DIN0204_L3.6mm_D1.6mm_P7.62mm_Horizontal
R20, R23: 100k; R_Axial_DIN0204_L3.6mm_D1.6mm_P7.62mm_Horizontal
R21, R24: 1M; R_Axial_DIN0204_L3.6mm_D1.6mm_P7.62mm_Horizontal
RV1, RV2, RV3, RV4: B100K; Potentiometer_Alps_RK09K_Horizontal
S1, S2, S3, S4, S5, S6, S7, S8, S9, S10, S11, S12, S13, S14, S15, S16: SW; SW_TH_Tactile_Omron_B3F-10xx
S17: Load; SW_TH_Tactile_Omron_B3F-10xx
S18: Save; SW_TH_Tactile_Omron_B3F-10xx
S19: Play; SW_TH_Tactile_Omron_B3F-10xx
S20: Shift; SW_TH_Tactile_Omron_B3F-10xx
S21: GlideBtn; SW_TH_Tactile_Omron_B3F-10xx
SW1: Repeat; Push_E-Switch_KS01Q01
SW2: Mutate; Push_E-Switch_KS01Q01
SW3: Rotary_Encoder; RotaryEncoder_Alps_EC12E_Vertical_H20mm
U1, U3: 74HC595; DIP-16_W7.62mm
U2: MCP23S17; DIP-28_W7.62mm

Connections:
+5V: C1.1, C2.1, C3.1, C4.1, C5.1, C6.1, C7.1, C8.1, C9.1, J1.1, Q1.1 (E), Q2.1 (E), Q3.1 (E), R19.1, R22.1, RV1.3, RV2.3, RV3.3, RV4.3, U1.10 (~SRCLR), U1.16 (VCC), U2.9 (VCC), U3.10 (~SRCLR), U3.16 (VCC)
/A0: S20.4, U2.1 (GPB0)
/A1: S17.4, U2.2 (GPB1)
/A2: S18.4, U2.3 (GPB2)
/A3: S19.4, U2.4 (GPB3)
/A4: SW1.2, U2.5 (GPB4)
/A5: SW2.2, U2.6 (GPB5)
/A6: S21.2, U2.7 (GPB6)
/A7: R17.1, U2.8 (GPB7)
AD1: J2.1, RV1.2
AD2: J2.2, RV2.2
AD3: J2.3, RV3.2
AD4: J2.4, RV4.2
CS0: J2.15, U2.11 (~CS)
CS1: J2.11, U1.12 (RCLK)
CS1A: J1.3, U3.12 (RCLK)
CV: J2.8, J8.3
ClockIn: J2.10, Q4.3 (C), R19.2
ClockOut: J2.6, J5.3
DIG1: J1.4, R14.2
DIG2: J1.5, R15.2
DIG3: J1.6, R16.2
ENC1: J1.10, SW3.A
ENC2: J1.9, SW3.B
GND: C1.2, C2.2, C3.2, C4.2, C5.2, C6.2, C7.2, C8.2, C9.2, D18.1 (K), D19.2 (A), J1.7, J1.8, J4.1, J5.1, J6.1, J7.1, J8.1, J9.1, Q4.1 (E), Q5.1 (E), R13.1, R21.2, R24.2, RV1.1, RV2.1, RV3.1, RV4.1, S17.2, S18.2, S19.2, S20.2, S21.4, SW1.1, SW2.1, SW3.C, U1.8 (GND), U1.13 (~OE), U2.10 (GND), U2.15 (A0), U2.16 (A1), U2.17 (A2), U3.8 (GND), U3.13 (~OE)
Gate: D17.2 (A), D19.1 (K), J2.5, R18.2
MISO: J2.14, U2.14 (SO)
MOSI: J2.13, U1.14 (SER), U2.13 (SI)
unnamed: D1.1 (K), D5.1 (K), D9.1 (K), D13.1 (K), U1.4 (QE)
unnamed: D1.2 (A), D2.2 (A), D3.2 (A), D4.2 (A), R1.2
unnamed: D5.2 (A), D6.2 (A), D7.2 (A), D8.2 (A), R2.1
unnamed: D2.1 (K), D6.1 (K), D10.1 (K), D14.1 (K), U1.5 (QF)
unnamed: D9.2 (A), D10.2 (A), D11.2 (A), D12.2 (A), R3.1
unnamed: D3.1 (K), D7.1 (K), D11.1 (K), D15.1 (K), U1.6 (QG)
unnamed: D4.1 (K), D8.1 (K), D12.1 (K), D16.1 (K), U1.7 (QH)
unnamed: D13.2 (A), D14.2 (A), D15.2 (A), D16.2 (A), R4.1
unnamed: D17.1 (K), R13.2
unnamed: D18.2 (A), R17.2
unnamed: J3.1 (E), R9.2
unnamed: J3.2 (D), R8.2
unnamed: J3.3 (DP), R12.2
unnamed: J3.4 (C), R7.2
unnamed: J3.5 (G), R11.2
unnamed: J3.7 (B), R6.2
unnamed: J3.8 (DIGIT_3), Q3.3 (C)
unnamed: J3.9 (DIGIT_2), Q2.3 (C)
unnamed: J3.10 (F), R10.2
unnamed: J3.11 (A), R5.2
unnamed: J3.12 (DIGIT_1), Q1.3 (C)
unnamed: J4.3, R18.1
unnamed: J6.3, R20.2
unnamed: J9.3, R23.2
unnamed: Q1.2 (B), R14.1
unnamed: Q2.2 (B), R15.1
unnamed: Q3.2 (B), R16.1
unnamed: Q4.2 (B), R20.1, R21.1
unnamed: Q5.2 (B), R23.1, R24.1
unnamed: R1.1, U1.15 (QA)
unnamed: R2.2, U1.1 (QB)
unnamed: R3.2, U1.2 (QC)
unnamed: R4.2, U1.3 (QD)
unnamed: R5.1, U3.15 (QA)
unnamed: R6.1, U3.1 (QB)
unnamed: R7.1, U3.2 (QC)
unnamed: R8.1, U3.3 (QD)
unnamed: R9.1, U3.4 (QE)
unnamed: R10.1, U3.5 (QF)
unnamed: R11.1, U3.6 (QG)
unnamed: R12.1, U3.7 (QH)
unnamed: S1.1, S5.1, S9.1, S13.1, U2.24 (GPA3)
unnamed: S1.4, S2.4, S3.4, S4.4, U2.28 (GPA7)
unnamed: S5.4, S6.4, S7.4, S8.4, U2.27 (GPA6)
unnamed: S2.1, S6.1, S10.1, S14.1, U2.23 (GPA2)
unnamed: S9.4, S10.4, S11.4, S12.4, U2.26 (GPA5)
unnamed: S3.1, S7.1, S11.1, S15.1, U2.22 (GPA1)
unnamed: S4.1, S8.1, S12.1, S16.1, U2.21 (GPA0)
unnamed: S13.4, S14.4, S15.4, S16.4, U2.25 (GPA4)
unnamed: U1.9 (QH'), U3.14 (SER)
Pitch: J2.7, J7.3
ResetIn: J2.9, Q5.3 (C), R22.2
SCK: J2.12, U1.11 (SRCLK), U2.12 (SCK)
SCKA: J1.2, U3.11 (SRCLK)
SPI_Reset: J2.16, U2.18 (~RESET)

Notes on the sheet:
ANALOG KNOBS
FUNCTION BUTTONS
INPUT/OUTPUT JACKS
LED MATRIX

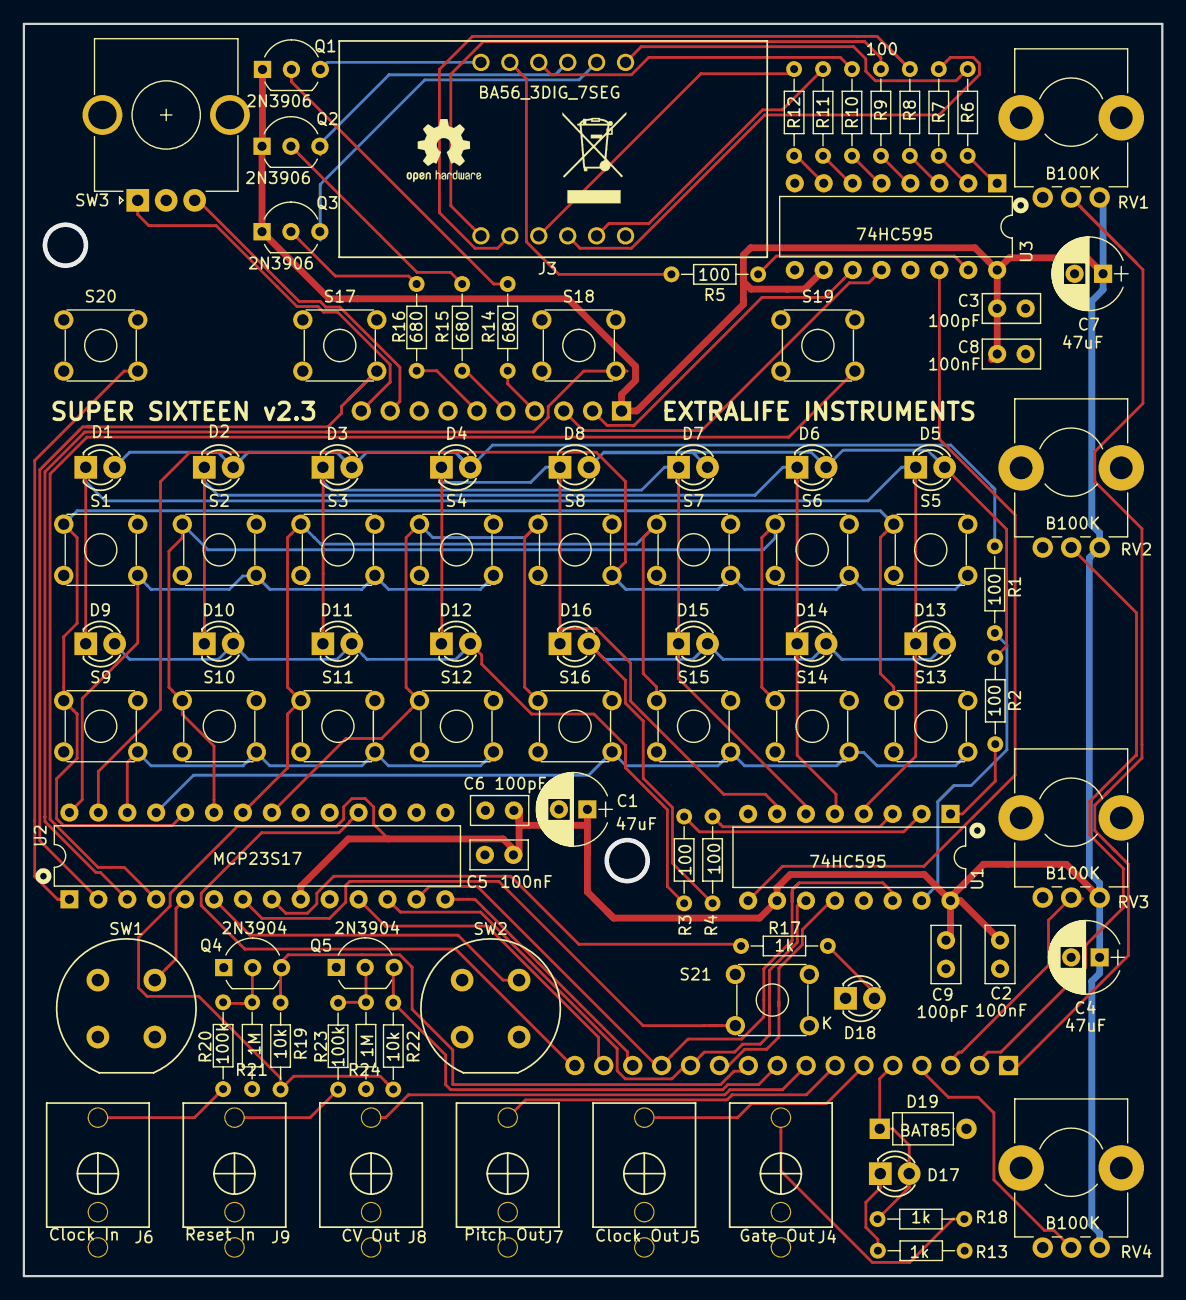
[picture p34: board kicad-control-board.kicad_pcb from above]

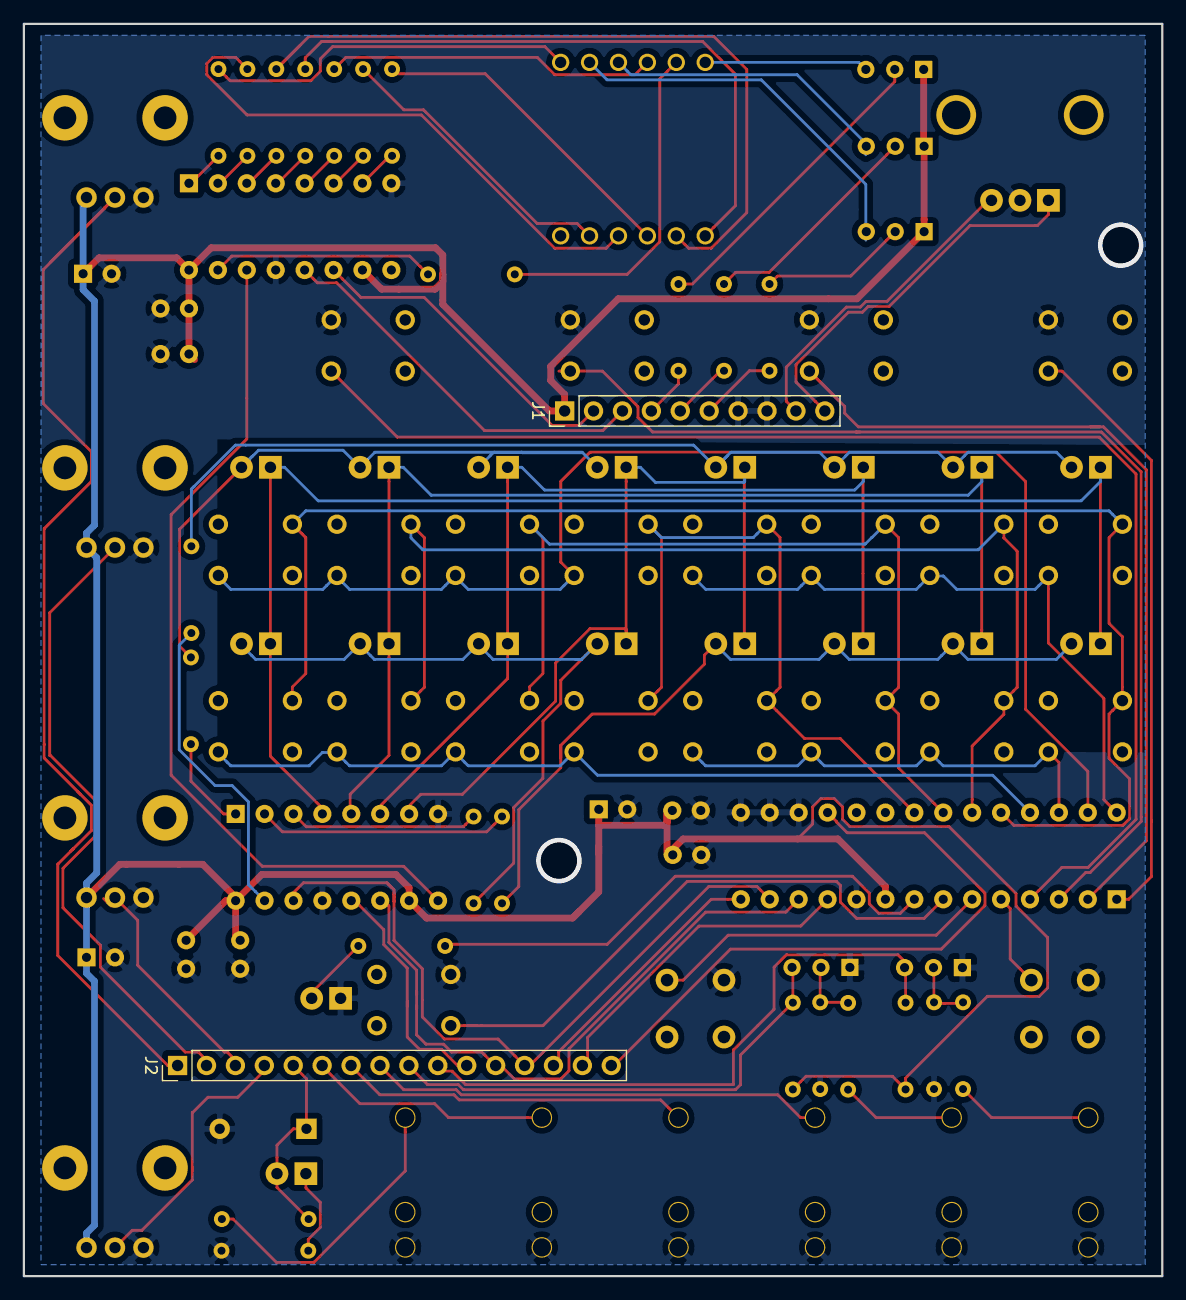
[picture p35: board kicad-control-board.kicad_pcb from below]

Board: 2 copper layers, 100.0 x 110.0 mm, 99 parts (2 on the bottom side), 83 nets.

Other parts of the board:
 : WEEE-Logo_5.6x8mm_SilkScreen
  : OSHW-Logo2_7.3x6mm_SilkScreen

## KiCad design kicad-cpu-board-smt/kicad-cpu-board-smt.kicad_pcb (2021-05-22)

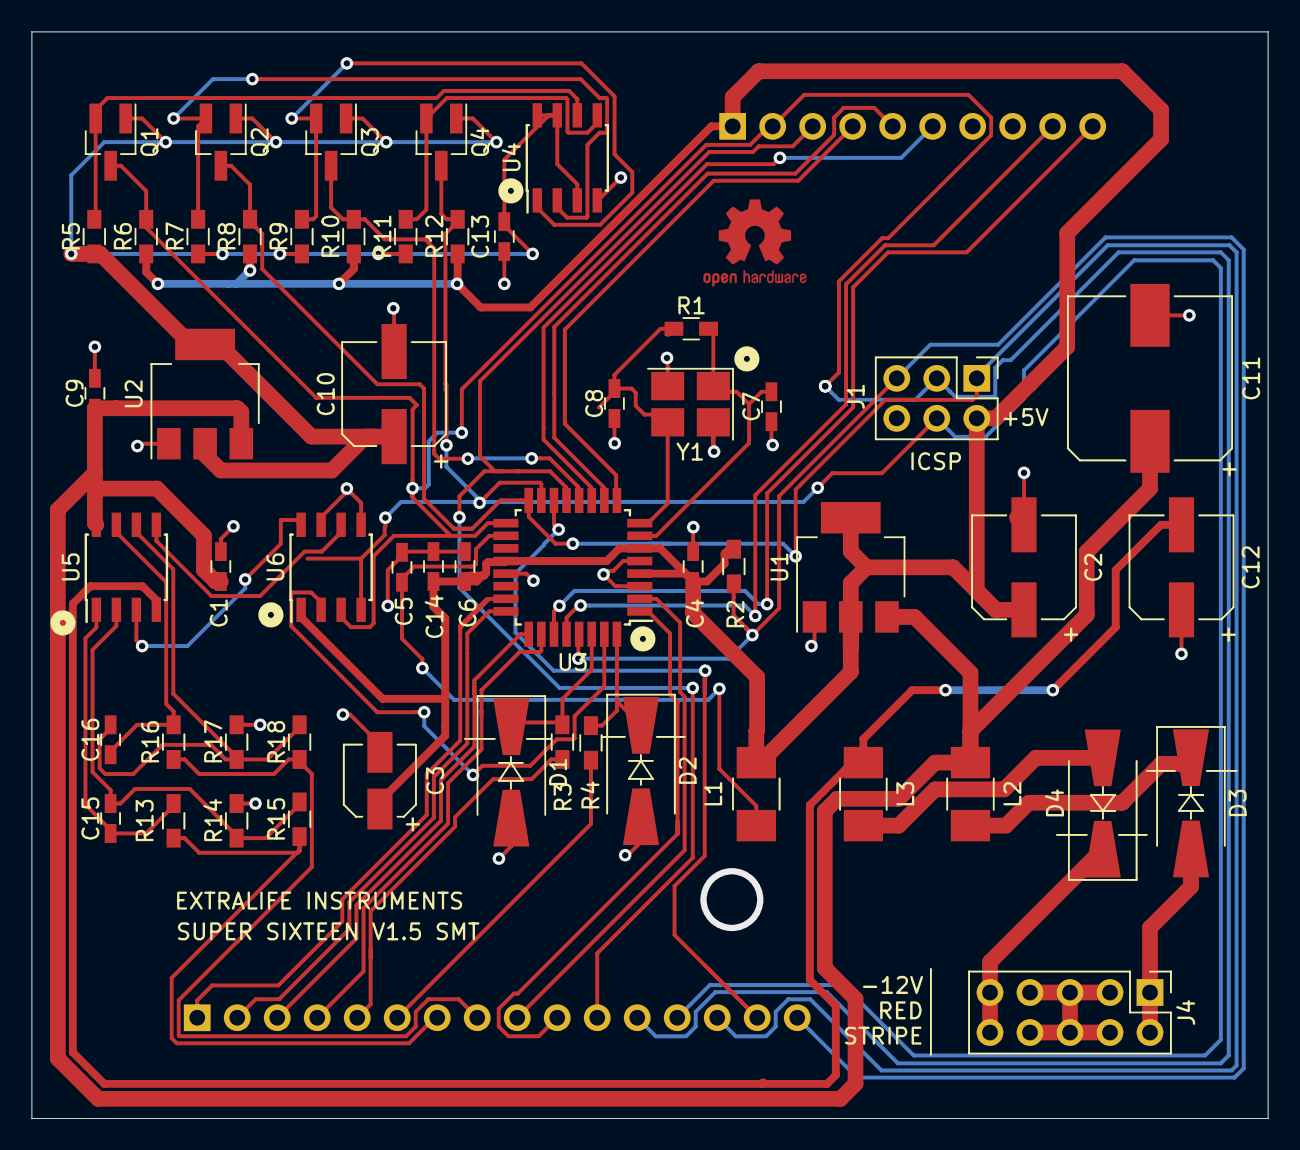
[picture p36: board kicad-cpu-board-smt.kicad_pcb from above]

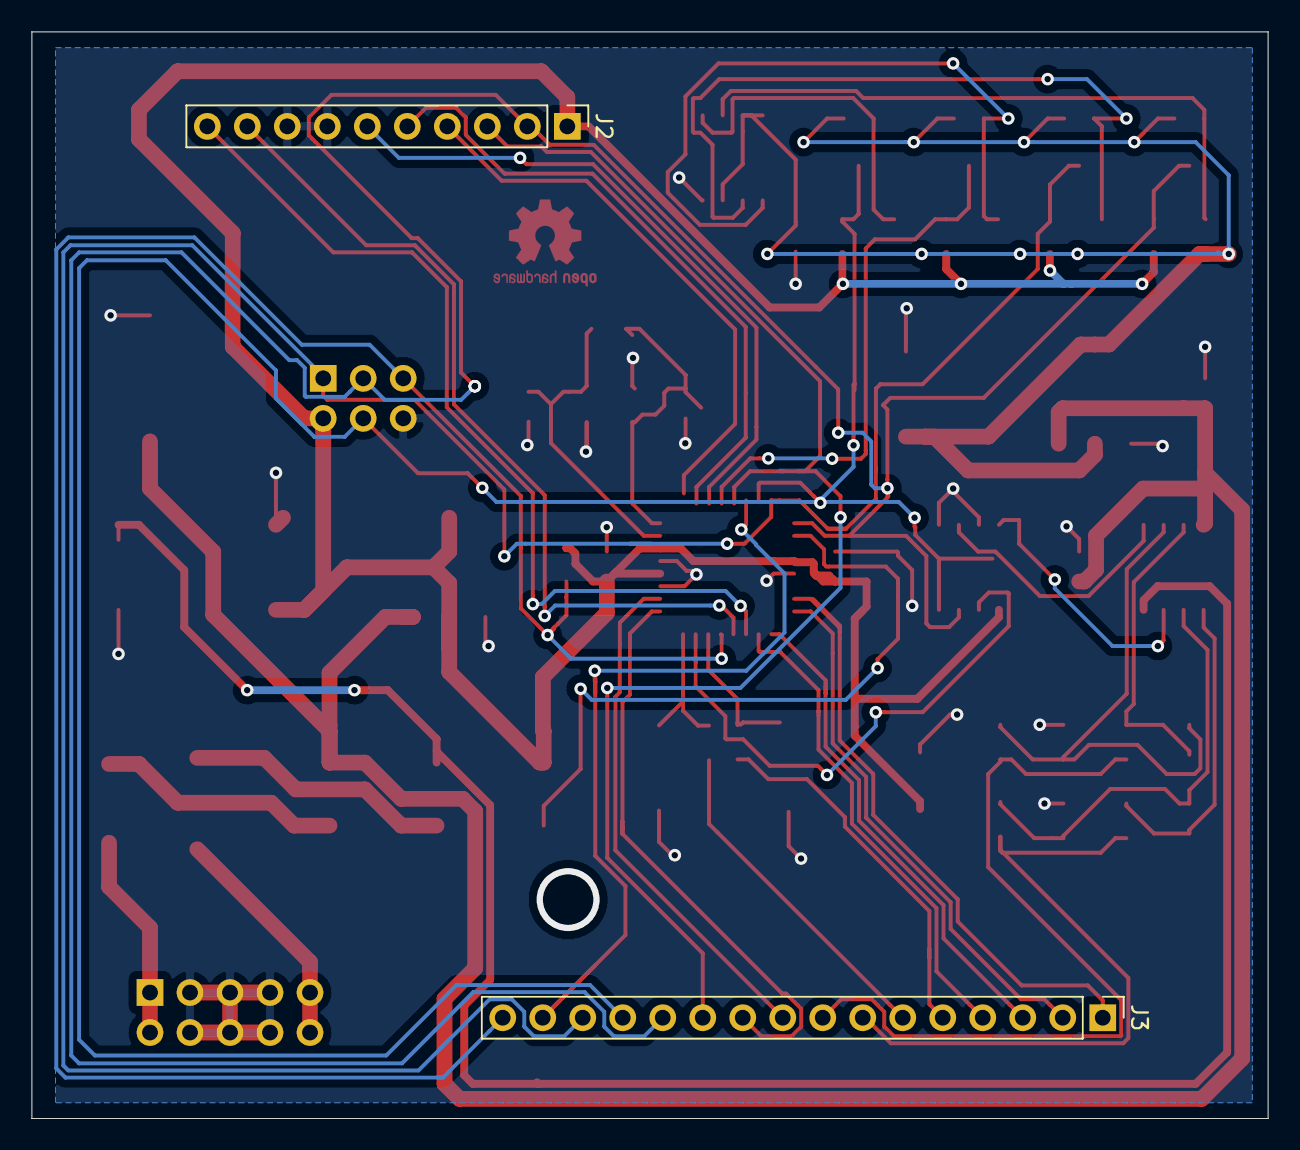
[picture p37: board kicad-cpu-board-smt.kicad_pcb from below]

Board: 2 copper layers, 78.5 x 69.0 mm, 56 parts (2 on the bottom side), 47 nets.

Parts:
C1, C4, C5, C6, C9, C13, C14: 100nF; C_0603_HandSoldering
C2, C10, C12: 47uF; CP_Elec_6.3x7.7
C3: 1uF; CP_Elec_4x5.3
C7, C8, C15, C16: 22pf; C_0603_HandSoldering
C11: 220uF; CP_Elec_10x10
D1, D2: 1SMA4733A; D_SMA-SMB_Universal_Handsoldering
D3, D4: M7; D_SMA-SMB_Universal_Handsoldering
J1: ICSP Header; Pin_Header_Straight_2x03_Pitch2.54mm
J2: Conn_01x10_Male; Pin_Header_Straight_1x10_Pitch2.54mm
J3: Conn_01x16_Female; Pin_Header_Straight_1x16_Pitch2.54mm
J4: Conn_02x05_Odd_Even; Pin_Header_Straight_2x05_Pitch2.54mm
L1, L2, L3: 220uH; L_1210_HandSoldering
Q1, Q2, Q3, Q4: 2N7002; SOT-23_Handsoldering
R1: 1M; R_0603_HandSoldering
R2, R14, R15, R17, R18: 10k; R_0603_HandSoldering
R3, R4, R13, R16: 1k; R_0603_HandSoldering
R5, R6, R7, R8, R9, R10, R11, R12: 1K; R_0603_HandSoldering
U1: AMS1117-5.0; SOT-223-3_TabPin2
U2: AMS1117-3.3; SOT-223-3_TabPin2
U3: ATmega328P-AU; TQFP-32_7x7mm_Pitch0.8mm
U4: W25Q80DVSN; SOIC-8_3.9x4.9mm_Pitch1.27mm
U5: TL072; SOIC-8_3.9x4.9mm_Pitch1.27mm
U6: MCP4822; SOIC-8_3.9x4.9mm_Pitch1.27mm
Y1: 16mHz; Crystal_SMD_3225-4pin_3.2x2.5mm_HandSoldering

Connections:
+3V3: C10.1, C13.1, Q1.1, Q2.1, Q3.1, Q4.1, R5.1, R7.1, R9.1, R11.1, U2.2, U4.3, U4.7, U4.8
+5V: C2.1, C3.1, C4.1, C6.1, C14.1, J1.2, J2.1, L1.2, R2.1, R6.1, R8.1, R10.1, R12.1, U1.2, U3.4, U3.6, U3.20, U6.1
+12V: C1.1, C9.1, C11.1, L2.1, U1.3, U2.3, U5.8
-12VA: C12.2, L3.1, U5.4
AD1: J3.1, U3.23
AD2: J3.2, U3.24
AD3: J3.3, U3.25
AD4: J3.4, U3.26
CS0: J3.15, U3.14
CS1: J2.3, J3.11, U3.13
CS2: Q3.3, R10.2, U3.12
CS3: U3.31, U6.2
CV: J3.8, R16.1, R18.1
ClockIn: J3.10, U3.1
ClockOut: J3.6, R4.1
DIG1: J2.4, U3.9
DIG2: J2.5, U3.10
DIG3: J2.6, U3.11
ENC1: J2.10, U3.27
ENC2: J2.9, U3.28
GND: C1.2, C2.2, C3.2, C4.2, C5.2, C6.2, C7.1, C8.1, C9.2, C10.2, C11.2, C12.1, C13.2, C14.2, D1.2, D2.2, J1.6, J2.7, J2.8, J4.3, J4.4, J4.5, J4.6, J4.7, J4.8, R14.2, R17.2, U1.1, U2.1, U3.3, U3.5, U3.21, U4.4, U6.5, U6.7, Y1.2, Y1.4
Gate: J3.5, R3.1
MISO: J1.1, J3.14, Q2.3, R8.2, U3.16
MOSI: J1.4, J3.13, Q4.3, R12.2, U3.15, U6.4
unnamed: C5.1, L1.1, U3.18
unnamed: C7.2, R1.2, U3.7, Y1.1
unnamed: C8.2, R1.1, U3.8, Y1.3
unnamed: C15.1, R13.2, U5.1
unnamed: C15.2, R14.1, R15.2, U5.2
unnamed: C16.1, R16.2, U5.7
unnamed: C16.2, R17.1, R18.2, U5.6
unnamed: D1.1, R3.2, U3.30
unnamed: D2.1, R4.2, U3.32
unnamed: D3.1, L2.2
unnamed: D3.2, J4.1, J4.2
unnamed: D4.1, J4.9, J4.10
unnamed: D4.2, L3.2
unnamed: Q1.2, R5.2, U4.6
unnamed: Q2.2, R7.2, U4.2
unnamed: Q3.2, R9.2, U4.1
unnamed: Q4.2, R11.2, U4.5
unnamed: U5.3, U6.8
unnamed: U5.5, U6.6
Pitch: J3.7, R13.1, R15.1
RESET: J1.5, J3.16, R2.2, U3.29
ResetIn: J3.9, U3.2
SCK: J1.3, J2.2, J3.12, Q1.3, R6.2, U3.17, U6.3

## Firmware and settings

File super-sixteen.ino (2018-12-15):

#include "Sequencer.h"
#include "Encoder.h"
#include "AnalogIO.h"
#include "LEDMatrix.h"
#include <MCP23S17.h> //https://github.com/MajenkoLibraries/MCP23S17
#include <SPI.h>
#include <elapsedMillis.h>

elapsedMillis multiplex;
elapsedMillis stepper;
elapsedMillis timekeeper;
elapsedMillis blinker;

#define ENC_PORT PINC
#define GATE_PIN 0
#define LDAC_PIN 1
#define CLOCK_OUT_PIN 2
#define CLOCK_IN_PIN 3
#define RESET_PIN 4

#define GLIDE_PIN 5
#define REPEAT_PIN 6
#define RECORD_PIN 7

#define GLIDE_LED_PIN 3 //this one's on display driver chip, not mcu
#define SAVE_PIN 4 //these four on display driver chip, not MCU
#define LOAD_PIN 5 //ditto
#define PLAY_PIN 6 //ditto
#define SHIFT_PIN 7 //ditto

const int function_buttons[4] = {SAVE_PIN, LOAD_PIN, PLAY_PIN, SHIFT_PIN};
int function_button_matrix[4] = {1, 1, 1, 1}; //store status of buttons in/out
const int aux_buttons[3] = {GLIDE_PIN, REPEAT_PIN, RECORD_PIN};
int aux_button_matrix[3] = {1, 1, 1};

const int CS0_PIN = 10;
const int CS1_PIN = 9;
const int GAIN_1 = 0x1;
const int GAIN_2 = 0x0;


uint8_t current_step = 0;
uint8_t active_step = 0;
uint8_t sequence_length = 16;
const int led_rows[4] = {0x80, 0x40, 0x20, 0x10};
//const int current_step_rows[4] = {0xE0, 0xD0, 0xB0, 0x70};
int step_map[16]       = {3, 2, 1, 0, 0, 1, 2, 3, 3, 2, 1, 0, 0, 1, 2, 3}; //rows are wired symmetrically rather than sequentially
int button_map[16]   = {3, 2, 1, 0, 0, 1, 2, 3, 3, 2, 1, 0, 0, 1, 2, 3}; //rows are wired symmetrically rather than sequentially

int pitch_matrix[16];
int octave_matrix[16];
int duration_matrix[16];
int cv_matrix[16];

bool step_matrix[16]   = {1,0,0,0, 0,0,0,0, 0,0,0,0, 0,0,0,0};
bool led_matrix[16]    = {1,0,0,0, 0,0,0,0, 0,0,0,0, 0,0,0,0};
bool button_matrix[16] = {1,1,1,1, 1,1,1,1, 1,1,1,1, 1,1,1,1};
bool glide_matrix[16];
//bool current_step_matrix[16] = {1, 1, 1, 1, 1, 1, 1, 1, 1, 1, 1, 1, 1, 1, 1, 1};
bool gate_active = false;
bool clock_active = false;
bool blinking = false;

uint8_t byte1;
uint8_t byte2;
int row_counter = 0;
int num_display = 0;
int digit_counter = 0;
int digit_display[3] = {0, 0, 0};

#define TEMPO_PARAM 0
#define PITCH_PARAM 1
#define OCTAVE_PARAM 2
#define DURATION_PARAM 3
#define CV_PARAM 4

int analog_params[4] = {PITCH_PARAM, OCTAVE_PARAM, DURATION_PARAM, CV_PARAM};

int display_param = PITCH_PARAM;


int col        = 0;
int stepnumber = 1;
int selected_step = 0;

int lastAnalogValues[4];
int analogValues[4];
int analogMultiplexor = 0;
int tempo = 300;
float calibration_value = 1.0;
float EMA_a = 0.6; //input smoothing coeff

int enc_a;
int enc_b;
int enc_a_prev;

byte font_table[] = {
  B1111110,   // [0] => "0"
  B0110000,   // [1] => "1"
  B1101101,   // [2] => "2"
  B1111001,   // [3] => "3"
  B0110011,   // [4] => "4"
  B1011011,   // [5] => "5"
  B1011111,   // [6] => "6"
  B1110000,   // [7] => "7"
  B1111111,   // [8] => "8"
  B1111011,   // [9] => "9"
  B1110111,   // [10] => "A"
  B0011111,   // [11] => "b"
  B1001110,   // [12] => "C"
  B0111101,   // [13] => "d"
  B1001111,   // [14] => "E"
  B1000111,   // [15] => "F"
  B0000001,   // [16] => "dash"
  B0000000,   // [17] => "blank"
};

uint8_t font[18];

MCP23S17 DisplayDriver(&SPI, CS0_PIN, 0);
MCP23S17 MatrixDriver(&SPI, CS0_PIN, 1);


void setup() {
  analogReference(EXTERNAL); // use AREF for reference voltage
  pinMode(CS0_PIN, OUTPUT); //enable CS for DAC
  pinMode(CS1_PIN, OUTPUT); //enable CS for DAC

  initializeMatrix();
  initializeDisplay();
  initializeFont();
  initializeButtons();

  for (int i = 0; i < 16; i++) {
    duration_matrix[i] = 80;
  }
}

void initializeFont() {
  for (int pin = 0; pin < 17; pin++) {
    int num = font_table[pin];
    font[pin] = ((num & 0x01) << 7)
                | ((num & 0x02) << 5)
                | ((num & 0x04) << 3)
                | ((num & 0x08) << 1)
                | ((num & 0x10) >> 1)
                | ((num & 0x20) >> 3)
                | ((num & 0x40) >> 5)
                | ((num & 0x80) >> 7);
  }
}
void initializeMatrix() {
  MatrixDriver.begin();
  for (int pin = 0; pin < 16; pin++) {
    if (pin < 4) {
      MatrixDriver.pinMode(pin, OUTPUT);
      MatrixDriver.digitalWrite(pin, LOW);
    } else if (pin >= 4 && pin < 8) {
      MatrixDriver.pinMode(pin, INPUT_PULLUP); //use these for reading in buttons
    } else {
      MatrixDriver.pinMode(pin, OUTPUT);
      MatrixDriver.digitalWrite(pin, LOW);
    }
  }

  MatrixDriver.writePort(0x0F00);
}

void initializeDisplay() {
  DisplayDriver.begin();
  for (int pin = 0; pin < 16; pin++) {
    if (pin >= 4 && pin < 8) {
      DisplayDriver.pinMode(pin, INPUT_PULLUP); //use these for reading in 4 top buttons
    } else {
      DisplayDriver.pinMode(pin, OUTPUT);
    }
    //DisplayDriver.writePort(0x0000);
  }
}

void initializeButtons() {
  pinMode(A4, INPUT_PULLUP); //encoder A
  pinMode(A5, INPUT_PULLUP); //encoder B
  pinMode(GLIDE_PIN, INPUT_PULLUP); //glide button
  pinMode(REPEAT_PIN, INPUT_PULLUP); //repeat button
  pinMode(RECORD_PIN, INPUT_PULLUP); //record button

  pinMode(GATE_PIN, OUTPUT); //gate
  
  //  pinMode(LDAC_PIN, OUTPUT); //LDAC
  //  pinMode(CLOCK_OUT_PIN, OUTPUT); //clock out
  //  pinMode(CLOCK_IN_PIN, INPUT); //clock in (external pullup)
  //  pinMode(6, INPUT); //reset in (external pullup)
  //
}



void updateMatrix(int row) {
  byte1 = 0x00;
  for (col = 0; col < 4; col++) {
    byte1 += ( led_matrix[row * 4 + col] << step_map[row * 4 + col]);
  }
  byte1 = (0x0F - byte1) | led_rows[row]; //invert since we want to pull low for active drain
  //byte2 = button_rows[row]; //while we're using the serial port, pull one output low for buttons so we can read them on the pullup inputs

  //turn on new light;
  //uint16_t doublebyte = (byte1 << 8) + byte2;
  //Bank3.writePort(0x0000); //hard-reset previous pins
  //Bank3.writePort(doublebyte);
  //Bank3.writePort(1, byte2);
  MatrixDriver.writePort(1, byte1);
}

void readButtons(int row) {
  //Bank3.writePort(0, button_rows[row]);
  //byte button_row = Bank3.readPort(0) & 0x00; // (mask since we only want the last 4 bits, pins 4-7);
  MatrixDriver.digitalWrite(row, LOW);
  for (int ii = 0; ii < 4; ii++) {
    int stepnum = row * 4 + ii;
    //    //check each bit in the byte and see if it's pulled low -- to reduce SPI overhead
    //    bool value = (button_rows[row] & (0x08 >> col)); //step_map[row*4+col])); //pins backwards again, iterate R-L by rightwards bitshift
    bool value = MatrixDriver.digitalRead(button_map[stepnum] + 4);
    if (value != button_matrix[stepnum]) { //detect when button changes state
      button_matrix[stepnum] = value; //store button state
      if (value == 0) { //toggle step status when button is pressed in
        selectStep(stepnum); 
      }
    }
  } 
  MatrixDriver.digitalWrite(row, HIGH);

  int function_button = DisplayDriver.digitalRead(function_buttons[row]); //get pins 4-7 of display driver chip for buttons near display
  if (function_button != function_button_matrix[row]) {
    function_button_matrix[row] = function_button;
    if (function_button == 0) {
      switch(function_buttons[row]) {
        case SHIFT_PIN: //todo write shift fn
        case PLAY_PIN: //todo write play fn
        case LOAD_PIN: //todo write load fn
        case SAVE_PIN: //todo write save fn
        default:
          num_display = (row+5) * 111;
          setDisplayNum();
      }
    }
  }

  if (aux_buttons[row]) {
    int aux_button = digitalRead(aux_buttons[row]);
    if (aux_button != aux_button_matrix[row]) {
      aux_button_matrix[row] = aux_button;
      if (aux_button == 0) { //take action on pressed, not depressed
        switch(aux_buttons[row]) {
          case GLIDE_PIN: 
            glide_matrix[selected_step] = !glide_matrix[selected_step];
            DisplayDriver.digitalWrite(GLIDE_LED_PIN, glide_matrix[selected_step] ? HIGH : LOW); //glide LED
            break;
          case RECORD_PIN: //todo write record fn
          case REPEAT_PIN: //todo write repeat fn
          default: 
           num_display = (row+1) * 222;
           setDisplayNum();
        }
      }
    }
  }
}

void selectStep(unsigned int stepnum) {
  if (selected_step == stepnum || !step_matrix[stepnum]) { //require 2 presses to turn active steps off, so they can be selected/edited without double-tapping //TODO maybe implement hold-to-deactivate
    step_matrix[stepnum] = !step_matrix[stepnum];
    led_matrix[stepnum] = step_matrix[stepnum]; 
  }
  
  selected_step = stepnum;

  //update display to show currently selected step value if applicable
  switch(display_param) {
    //case TEMPO_PARAM: break
    case PITCH_PARAM:    num_display = pitch_matrix[stepnum]; break;
    case OCTAVE_PARAM:   num_display = octave_matrix[stepnum]; break;
    case DURATION_PARAM: num_display = duration_matrix[stepnum]; break;
    case CV_PARAM:       num_display = cv_matrix[stepnum]; break;
  }

  DisplayDriver.digitalWrite(GLIDE_LED_PIN, glide_matrix[stepnum]); //glide LED

  setDisplayNum();
}

//assuming dac single channel, gain=2
void setOutput(unsigned int val) {
  if (val > 4096) {
    val = 4095;
  }
  byte lowByte = val & 0xff;
  byte highByte = ((val >> 8) & 0xff) | 0x10;

  digitalWrite(CS1_PIN, LOW);
  PORTB &= 0xfb;
  SPI.transfer(highByte);
  SPI.transfer(lowByte);
  PORTB |= 0x4;
  digitalWrite(CS1_PIN, HIGH);
}

void setOutput(byte channel, byte gain, byte shutdown, unsigned int val)
{
  byte lowByte = val & 0xff;
  byte highByte = ((val >> 8) & 0xff) | channel << 7 | gain << 5 | shutdown << 4;
   
  //PORTB &= 0xfb;
  digitalWrite(CS1_PIN, LOW);
  SPI.transfer(highByte);
  SPI.transfer(lowByte);
  digitalWrite(CS1_PIN, HIGH);
}


void updateDisplay() {
  DisplayDriver.digitalWrite(digit_counter, LOW); //turn off prev digit
  digit_counter++;
  if (digit_counter == 3) {
    digit_counter = 0;
  }
  DisplayDriver.writePort(1, 0xFF - (font[digit_display[digit_counter]] >> 1));
  DisplayDriver.digitalWrite(digit_counter, HIGH); //turn on new digit
}

void increment_step() {
  if (timekeeper > tempo) {
    timekeeper = 0;

    led_matrix[current_step] = step_matrix[current_step]; //reset previous LED
    current_step++;
    if (current_step == 16) {
      current_step = 0;
    }
    led_matrix[current_step] = !step_matrix[current_step]; //set current led

    if (step_matrix[current_step]) {
      //PITCH/OCTAVE
      int note = (octave_matrix[current_step] + 2) * 12 + pitch_matrix[current_step];
      setOutput(0, GAIN_2, 1, note * 11.63 * 4 * calibration_value); //convert from 0-88 to 0-4096, scale octave by calibration value
      
      //CV
      //setOutput(0, GAIN_2, 1, cv_matrix[current_step] * 40.96);
  
      //GATE
      active_step = current_step;
      //if (!gate_active) {
        digitalWrite(GATE_PIN, step_matrix[current_step] ? HIGH : LOW);
        gate_active = step_matrix[current_step];
      //}
  
      //CLOCK
      digitalWrite(CLOCK_OUT_PIN, HIGH);
      clock_active = true;
    }

  } 
}

void update_gate() {
  double percent_step = timekeeper / (double)tempo * 100.0;
  int steps_advanced = current_step - active_step + 1;
  if (steps_advanced < 1) {
    steps_advanced = current_step + sequence_length - active_step + 1;
  }
  if (gate_active && duration_matrix[active_step] < percent_step * steps_advanced) {
    digitalWrite(GATE_PIN, LOW);
    gate_active == false;
  }

  if (clock_active && timekeeper > 0) {
    digitalWrite(CLOCK_OUT_PIN, LOW);
  }
}

void multiplex_leds() {
  if (multiplex > 1) {
    multiplex = 0;

    updateMatrix(row_counter);
    readButtons(row_counter);
    row_counter++;

    if (row_counter == 4) {
      row_counter = 0;
    }

    updateDisplay();
  }
}

void blink_step() {
  if (step_matrix[selected_step]) {
    if (blinker > (led_matrix[selected_step] ? 600 : 100)) { //blink long when active
      blink_led();
      blinker = 0;
    }
  } else {
    if (blinker > (led_matrix[selected_step] ? 100 : 600)) { //blink short when inactive
      blink_led();
      blinker = 0;
    }
  }
}

void blink_led(){
  led_matrix[selected_step] = !led_matrix[selected_step];
}

void read_input() {
  if (stepper > 10) {
    stepper = 0;
    
    read_encoder();
    blink_step();
    
    
    analogMultiplexor += 1;
    if (analogMultiplexor > 4) {
      analogMultiplexor = 0;
    }
    int i = analogMultiplexor;
    if (i > 3 || i < 0) return; //sometimes we get desynced by interrupts, and analogRead on a wrong pin is fatal
    analogValues[i] = analogRead(i);

    int change_threshold = 100;
    if (display_param == analog_params[i]) {
      change_threshold = 4; //increase sensitivity when param is selected, decrease otherwise to reduce accidental "bump" changes
    }
    if (abs(analogValues[i] - lastAnalogValues[i]) > change_threshold) {
      lastAnalogValues[i] = analogValues[i];
      switch (i) {
        case 0: setPitch(analogValues[0]); break;
        case 1: setOctave(analogValues[1]); break;
        case 2: setDuration(analogValues[2]); break;
        case 3: setCV(analogValues[3]); break;
      }
      setDisplayNum();
    }

  }
}

void setDisplayNum(){
  digit_display[0] = abs(num_display) % 10;
  digit_display[1] = abs(num_display) / 10 % 10;
  digit_display[2] = abs(num_display) / 100 % 10;
  if (num_display < 0) {
    digit_display[2] = 16; //minus sign in font array
  } else if (abs(num_display) < 100) {
    digit_display[2] = 17; //blank leading zeros
  }
  if (abs(num_display) < 10) {
    digit_display[1] = 17; //blank leading zeros
  }
}

void setPitch(int analogValue) {
  display_param = PITCH_PARAM;
  //calibration_value = (float(analogValues[1]) + 1024.0) / 1500.0 ; //11.60
  int newVal = analogValue / 42.6 - 12; //convert from 0_1024 to 0_88 to -12_0_12
  if (pitch_matrix[selected_step] != newVal) num_display = newVal;
  pitch_matrix[selected_step] = newVal;
}

void setOctave(int analogValue) {
  display_param = OCTAVE_PARAM;
  int newVal = analogValue / 120 - 4; //convert from 0-1024 to -4_0_4
  if (octave_matrix[selected_step] != newVal) num_display = newVal;
  octave_matrix[selected_step] = newVal;
}

void setDuration(long analogValue) { //need extra bits for exponent operation
  display_param = DURATION_PARAM;
  int newVal = analogValue * analogValue / 2615; //convert from 0-1024 to 0-400 with exponential curve
  if (duration_matrix[selected_step] != newVal) num_display = newVal;
  duration_matrix[selected_step] = newVal;
}
void setCV(int analogValue) {
  display_param = CV_PARAM;
  int newVal = analogValue / 10.23; //convert from 0-1024 to 0-100
  if (cv_matrix[selected_step] != newVal) num_display = newVal;
  cv_matrix[selected_step] = newVal;
}

//magic numbers from https://www.circuitsathome.com/mcu/reading-rotary-encoder-on-arduino/
void read_encoder() {
///* returns change in encoder state (-1,0,1) */
//int8_t read_encoder()
//{
  static int8_t enc_states[] = {0,-1,1,0,1,0,0,-1,-1,0,0,1,0,1,-1,0};
  static uint8_t old_AB = 0;
  /**/
  old_AB <<= 2;                   //remember previous state
  old_AB |= ( ENC_PORT & 0x30 ) >> 4;  //add current state from pins A5 and A4, shifted to LSB
  encoder_increment ( enc_states[( old_AB & 0x0f )] * -1); //extract encrement/decrement value from state table
}

void encoder_increment(int amt) {
  if (amt == 0) return;
  tempo += amt;
  if (tempo < 20) tempo = 20;
  if (tempo > 500) tempo = 500;
  num_display = tempo;
  display_param = TEMPO_PARAM;
  setDisplayNum();
}

void loop() {
  increment_step();
  multiplex_leds();
  read_input();
  update_gate();
}

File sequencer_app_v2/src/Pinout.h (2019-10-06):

#pragma once

namespace supersixteen{

#define GATE_PIN PD0
//#define LDAC_PIN 1
#define CLOCK_OUT_PIN PD2
#define CLOCK_IN_PIN PD3
#define RESET_PIN PD4


#define GLIDE_LED_PIN 15 //these 8 are on the button driver chip, not the MCU
#define GLIDE_PIN 14
#define REPEAT_PIN 13
#define RECORD_PIN 12
#define SAVE_PIN 11 
#define LOAD_PIN 10 
#define PLAY_PIN 9 
#define SHIFT_PIN 8

#define CS0_PIN  10 //MCP23S17 for buttons, aux LEDS
#define CS1_PIN  9  //Display/matrix shift registers
#define CS2_PIN  8  //Flash memory
#define CS3_PIN  1  //DAC PD1

  //DIGIT DISPLAY PINS
#define DIGIT_1_PIN PD5
#define DIGIT_2_PIN PD7
#define DIGIT_3_PIN PD6 

#define GAIN_1  0x1
#define GAIN_2  0x0

#define ANALOG_PIN_1 A0
#define ANALOG_PIN_2 A1
#define ANALOG_PIN_3 A2
#define ANALOG_PIN_4 A3

#define ENC_A_PIN A4
#define ENC_B_PIN A5
#define ENC_PORT PINC

}

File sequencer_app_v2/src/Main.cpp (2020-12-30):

// Copyright 2019 Extralife Instruments.
//
// Author: Matthew Cieplak (extralifedisco@gmail.com)
//
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
// See http://creativecommons.org/licenses/MIT/ for more information.
//
// -----------------------------------------------------------------------------
//
// User interface.

#include <Arduino.h>
#include <string.h>
#include <MCP23S17.h> //https://github.com/MajenkoLibraries/MCP23S17
#include <SPI.h>
#include <elapsedMillis.h>


#include "Buttons.h"
#include "Encoder.h"
#include "AnalogIO.h"
#include "Dac.h"
#include "Display.h"
#include "Font.h"
#include "LEDMatrix.h"
#include "Main.h"
#include "Sequencer.h"
#include "Variables.h"
#include "Ui.h"
#include "Dac.h"
#include "Calibrate.h"
#include "Pinout.h"

using namespace supersixteen;

Ui ui;
Dac dac;
Calibration calibration;
Sequencer sequencer;

void setup() {
	analogReference(EXTERNAL); // use AREF for reference voltage

	calibration.readCalibrationValues(); // -- disable to bypass overwriting EEPROM during programming/development. uncomment for typical use
	
    sequencer.init(calibration, dac);
	ui.init(calibration, dac, sequencer);
}


void loop() {
	ui.poll();
	ui.multiplex();
	if (ui.isSequencing()){
		run_sequence();
	}
}

void run_sequence() {
	sequencer.updateClock();
	if (sequencer.stepWasIncremented()){
		ui.onStepIncremented();
	} 

}

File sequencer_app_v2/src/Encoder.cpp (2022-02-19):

#include "Variables.h"
#include "Pinout.h"
#include "AnalogIO.h"
#include "Encoder.h"
#include "Display.h"
#include "Calibrate.h"
#include "Sequencer.h"
#include "Arduino.h"
#include <stdint.h>

#include <EEPROM.h>


namespace supersixteen{

int increment_amount = 0;
int encoder_amount = 0;

uint8_t pinA = 0xFF;
uint8_t pinB = 0xFF;
int8_t invert_encoder = 1;
const int encoder_invert_address = 16;

void Encoder::init(){
	pinMode(ENC_A_PIN, INPUT_PULLUP); //encoder A
	pinMode(ENC_B_PIN, INPUT_PULLUP); //encoder B
	invert_encoder = EEPROM.read(encoder_invert_address) > 0 ? -1 : 1;
}

//magic numbers from https://www.circuitsathome.com/mcu/reading-rotary-encoder-on-arduino/
int Encoder::poll(){
	///* returns change in encoder state (-1,0,1) */
	//int8_t read_encoder()
	//{
	increment_amount = 0;
	static int8_t enc_states[] = { 0,-1,1,0,1,0,0,-1,-1,0,0,1,0,1,-1,0 };
	static uint8_t old_AB = 0;
	/**/
	old_AB <<= 2;                   //remember previous state
	old_AB |= (ENC_PORT & 0x30) >> 4;  //add current state from pins A5 and A4, shifted to LSB
	encoder_increment(enc_states[(old_AB & 0x0f)]); //extract encrement/decrement value from state table
	return increment_amount * invert_encoder;
}



void Encoder::encoder_increment(int amt) {
	if (amt == 0) return;
	encoder_amount += amt;
	if (abs(encoder_amount) < 4) return; //encoder detent is too coarse for 1-per step granularity
	increment_amount = encoder_amount > 0 ? 1 : -1;
	encoder_amount = 0;
}

bool Encoder::toggle_inverted(){
	invert_encoder = invert_encoder * -1;
	EEPROM.write(encoder_invert_address, invert_encoder < 0 ? -1 : 0);
	return invert_encoder > 0;
}

}

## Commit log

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2018-07-03 Adding kicad files
    [Super Sixteen v1.kicad_pcb, Super Sixteen v1.sch]
2018-07-25 Updating schematic
    [Super Sixteen v1.sch]
2018-07-25 Adding calibration value scale to DAC demo
2018-09-09 Updating schematic and PCB
    [Super Sixteen v1.sch]
2018-09-09 Adding gerber prints
    [Super Sixteen v1-B.Cu.gbr, Super Sixteen v1-Edge.Cuts.gbr, Super Sixteen v1-F.Cu.gbr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]
2018-09-25 First draft of sequencer in arduino code
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2018-12-15 Refactoring arduino code into C++, implementing calibration
2018-12-15 Cleaning up kicad folder
    [Super Sixteen v1-2018-07-29-00-30-48.sch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]
2019-05-28 New control board PCB
    [kicad-control-board-B.Cu.gbl, kicad-control-board-B.Mask.gbs, kicad-control-board-B.SilkS.gbo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]
2019-05-28 New CPU board PCB
    [kicad-cpu-board-B.Cu.gbl, kicad-cpu-board-B.Mask.gbs, kicad-cpu-board-B.SilkS.gbo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]
2019-05-28 Adding original arduino .INO sketch for archival use
2019-05-28 Rebuilding sequencer app for new boards and VS Code+Platform.io instead of Visual Studio
2019-05-30 Rewriting LED/matrix/button logic for new shift register pinout
2019-05-30 Updating kicad gitignore files
2019-06-04 Updating encoder read logic and tempo bpm display
2019-06-10 Fixing compilation, localizing variables
    [AnalogIO.cpp, Buttons.cpp, Dac.cpp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]
2019-06-11 Fixing LED chase and button registration
    [AnalogIO.cpp, Buttons.cpp, Encoder.cpp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]
2019-06-11 Fixing glide led mask.
    [Buttons.cpp, Display.cpp, Ui.cpp]
2019-06-11 Fixing pitch/gate out
2019-06-12 Using queue to fix button press events
    [Buttons.cpp, Display.cpp, Ui.cpp]
2019-07-15 Kicad cache
    [kicad-control-board.sch]
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2019-10-07 Fixing motion record display action
    [AnalogIO.cpp, Display.cpp, Sequencer.cpp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]
2019-10-07 Fixing glide led/button glitch
    [Buttons.cpp]
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2019-10-18 Implementing glide and reverse effects
    [Sequencer.cpp, Sequencer.h]
2019-10-18 Fixing glitch randomizing with external clock
    [Sequencer.cpp, Sequencer.h, Ui.cpp]
2019-10-19 Fixing record audition, display flicker when external clocking
    [Sequencer.cpp, Sequencer.h, Ui.cpp]
2019-10-19 Implementing bar copy/paste and fixing no-op button events
    [Buttons.cpp, Display.cpp, Sequencer.cpp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]
2019-10-19 Finally fixing record audition and overwrite bugs
    [AnalogIO.cpp, Sequencer.cpp, Sequencer.h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]
2019-12-11 Updating PCB and schematics for assembly bugfixes
    [kicad-control-board.kicad_pcb, kicad-control-board.sch, kicad-cpu-board.kicad_pcb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]
2019-12-11 De-inverting display LEDs
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2019-12-11 Updating control board gerbers
    [kicad-control-board-B.Cu.gbl, kicad-control-board-B.Mask.gbs, kicad-control-board-B.SilkS.gbo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]
2019-12-11 Updating CPU board gerbers
    [kicad-cpu-board-B.Cu.gbl, kicad-cpu-board-B.SilkS.gbo, kicad-cpu-board-B_Cu.gbl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]
2019-12-11 Swapping in 660R resistors
    [kicad-control-board.kicad_pcb]
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2019-12-18 Optimizing resistor values for display
    [kicad-control-board.kicad_pcb]
2019-12-18 Fixing voltage regulator packcage
2019-12-18 Adding SMT cpu board project
    [kicad-cpu-board-smt.kicad_pcb, kicad-cpu-board-smt.sch]
2019-12-18 Adding SMT cpu board gerbers
    [kicad-cpu-board-smt-B_Cu.gbr, kicad-cpu-board-smt-B_Mask.gbr, kicad-cpu-board-smt-B_Paste.gbr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]
2019-12-18 Adding SMT cpu board BOM and position files
    [kicad-cpu-board-smt-all.xlsx, kicad-cpu-board-smt.csv]
2019-12-18 Adding SMT control board project
    [kicad-control-board-smt.kicad_pcb, kicad-control-board-smt.sch]
2019-12-18 Addding SMT control board gerbers
    [kicad-control-board-smt-B_Cu.gbr, kicad-control-board-smt-B_Mask.gbr, kicad-control-board-smt-B_Paste.gbr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]
2019-12-18 Adding SMT control board BOM and position files
    [kicad-control-board-smt.csv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]
2020-02-29 Fixing CPU footprint on SMT board and updating bom + gerbers
    [kicad-cpu-board-smt-B_Cu.gbr, kicad-cpu-board-smt-B_Mask.gbr, kicad-cpu-board-smt-B_Paste.gbr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]
2020-02-29 Rerouting traces to avoid potentiometer support lugs shorting to ground
    [kicad-control-board-smt.kicad_pcb]
2020-02-29 Adding encoder invert function
    [Encoder.cpp]
2020-02-29 Invert encoder via shift function
    [Ui.cpp]
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2020-05-11 Adding bit-option to flip between common anode/common-cathode
    [Display.cpp]
2020-05-11 Amending common-cathode mode for non-inverted character display
    [Display.cpp]
2020-06-19 Tweaking tracerouting
    [kicad-cpu-board-smt.kicad_pcb, kicad-cpu-board-smt.sch]
2020-06-19 Updating SMT BOM files for domestic parts
    [kicad-cpu-board-digikey.csv, kicad-cpu-board-sierra.xlsx, kicad-cpu-board-smt-all.xlsx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]
2020-06-19 Adding part numbers
    [kicad-control-board-smt.kicad_pcb, kicad-control-board-smt.sch]
2020-06-19 Updating SMT BOM file for control board
    [kicad-control-board-smt-bom-digikey.csv, kicad-control-board-smt-bom-sierra.xlsx, kicad-control-board-smt.csv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]
2020-06-19 Fixing button debounce
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2020-06-19 Show visual feedback on manual reset.
    [Ui.cpp]
2020-07-01 Better debouncing to fix simultaneous release.
    [Buttons.cpp]
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2020-08-02 Creating PCB panel kicad project
    [kicad-panel.kicad_pcb, kicad-panel.sch]
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2020-08-02 Rendering front panel gerbers
    [kicad-panel-B_Cu.gbr, kicad-panel-B_Mask.gbr, kicad-panel-B_Paste.gbr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]
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2020-08-02 Updating control positions, adding standoff on control PCB
    [kicad-control-board.kicad_pcb]
2020-08-02 Updating control positions on SMT version
    [kicad-control-board-smt.kicad_pcb]
2020-08-02 Updating control board gerbers and position file (SMT version)
    [kicad-control-board-smt-B_Cu.gbr, kicad-control-board-smt-B_Mask.gbr, kicad-control-board-smt-B_Paste.gbr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]
2020-08-02 Incrementing CPU SMT board version
    [kicad-cpu-board-smt.kicad_pcb]
2020-08-02 Updating CPU board berbers
    [kicad-cpu-board-B_Cu.gbl, kicad-cpu-board-B_Mask.gbs, kicad-cpu-board-B_SilkS.gbo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]
2020-08-02 Adding R values to silkscreen
    [kicad-cpu-board.kicad_pcb]
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2020-08-02 Fixing clear function scale default.
    [Sequencer.cpp, Sequencer.h]
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2020-08-31 Optimizing reset and multiplex subroutines to fix display flicker
    [LEDMatrix.cpp, Sequencer.cpp]
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2020-08-31 Updating control board silkscreen
    [kicad-control-board-B_Cu.gbl, kicad-control-board-B_Mask.gbs, kicad-control-board-B_SilkS.gbo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]
2020-08-31 Updating SMT control board silkscreen
    [kicad-control-board-smt-B_Cu.gbr, kicad-control-board-smt-B_Mask.gbr, kicad-control-board-smt-B_Paste.gbr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]
2020-08-31 Updating CPU board silkscreen
    [kicad-cpu-board-B_Cu.gbl, kicad-cpu-board-B_Mask.gbs, kicad-cpu-board-B_SilkS.gbo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]
2020-08-31 Updating PCB panel cutout positions
    [kicad-panel-B_Cu.gbr, kicad-panel-B_Mask.gbr, kicad-panel-B_Paste.gbr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]
2020-09-05 Enabling quicksave/quickload and fixing step record
    [Ui.cpp]
2020-09-05 Factory reset on 5x clear sequence.
    [Ui.cpp]
2020-09-05 Fixing unsigned integer comparison.
    [Display.cpp]
2020-12-28 Organizing SMT BOM
    [kicad-cpu-board-bom-smt.xlsx, kicad-cpu-board-digikey.csv, kicad-cpu-board-sierra.xlsx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]
2020-12-30 Enabling note name mode C0, B1 etc toggleable in calibrate menu
2020-12-30 Implementing turing mode to store random pitch changes
2021-03-04 Fixing clock reset desync issue and updating build to 1.1a
    [Sequencer.cpp]
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2021-05-22 Updating silkscreen on SMT cpu board
    [kicad-cpu-board-smt-B_Cu.gbr, kicad-cpu-board-smt-B_Mask.gbr, kicad-cpu-board-smt-B_Paste.gbr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]
2021-05-22 Flipping 2n3906 transistors silkscreen
    [kicad-control-board-B_Cu.gbl, kicad-control-board-B_Mask.gbs, kicad-control-board-B_SilkS.gbo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]
2021-05-22 Flipping SMT MMBT2N3906 transistor orientation
    [kicad-control-board-smt-B_Cu.gbr, kicad-control-board-smt-B_Mask.gbr, kicad-control-board-smt-B_Paste.gbr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]
2021-05-22 Updating CPU board version silkscreen
    [kicad-cpu-board-B_Cu.gbl, kicad-cpu-board-B_Mask.gbs, kicad-cpu-board-B_SilkS.gbo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]
2021-07-28 Bugfix for sequence loading of different length - adding jog function on shift+encoder - prototype brightness function
    [Display.cpp, Sequencer.cpp, Sequencer.h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]
2022-01-01 Fixed some filename typos to fix compiling on case-sensitive filesystems
2022-02-19 Enabling note audition w shift+pitch, cleaning up calibration mode display
2022-02-19 Better feedback for encoder invert mode
    [Encoder.cpp]
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2022-04-12 Fixing turing pitch cv2 generation and rec note display
    [AnalogIO.cpp, Sequencer.cpp, Sequencer.h]
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2022-06-11 Fixing default voltage level to remain consistent with 1.0-1.1
    [Sequencer.cpp]
2022-06-11 Applying octave fix to CV2
    [Sequencer.cpp]
2023-05-15 Discard 0 octave calibration, better cv adjust range

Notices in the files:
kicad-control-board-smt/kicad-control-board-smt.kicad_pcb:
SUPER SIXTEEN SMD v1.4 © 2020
